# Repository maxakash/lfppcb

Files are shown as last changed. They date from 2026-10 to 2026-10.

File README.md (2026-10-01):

# LFP-8: 40-cell LiFePO4 33140 charger / discharger / IR tester

An open hardware tester for LiFePO4 32140/33140 cells. One **LFP-8 board**
handles **8 cells**. Five boards, JLCPCB's minimum order, test **40 cells at
once**. Each channel can

* **charge** with constant current then constant voltage: ≈ 1.0 A, CV 3.58 V,
  hardware OV latch at 3.82 V
* **discharge** at ≈ 1.07 A, with a hardware under-voltage backstop at 2.22 V
* measure **capacity** (coulomb counting, mAh/mWh) and **internal resistance**
  (pulse method, R_ohmic at 10 ms and DC-IR at 1 s) through true **4-wire
  Kelvin** connections
* read a 10 k **NTC** on every cell

Every board reports over Wi-Fi: a web dashboard and a JSON API served by its
ESP32-C3. The boards find each other, so any one of them shows all 40 cells.

| | |
|---|---|
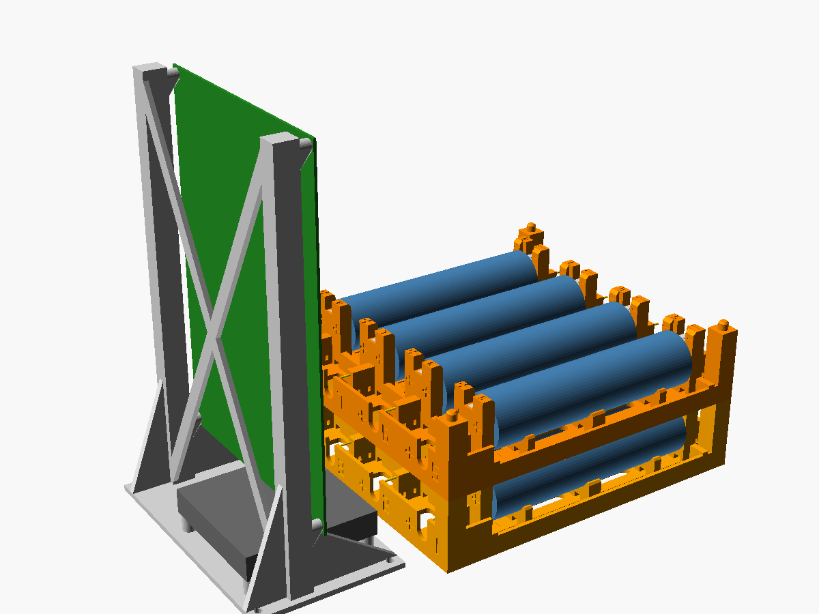
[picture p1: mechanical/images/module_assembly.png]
holder
| PCB |  |
| LFP-8 PCB (216 × 146 mm, 2 layers, JLCPCB assembly) | 3D-printed 8-cell module + board stand (Ender 3 S1 Pro) |

## Repository map

| Path | What |
|---|---|
| [`docs/DESIGN.md`](docs/DESIGN.md) | Architecture, circuit description, design numbers |
| [`docs/INTERFACE.md`](docs/INTERFACE.md) | Hardware ⇄ firmware contract: GPIO map, shift-register bits, thresholds, measurement formulas |
| [`docs/TEST_REPORT.md`](docs/TEST_REPORT.md) | Results of every simulation, adversarial and board-level test |
| [`docs/ORDERING_AND_ASSEMBLY.md`](docs/ORDERING_AND_ASSEMBLY.md) | How to order from JLCPCB, hand-solder parts, wiring, bring-up |
| `hardware/gen/` | **Single source of truth**: the netlist DSL (`lfp8_circuit.py`) and the generators for schematic, PCB, routing, checks and fab files |
| `hardware/kicad/` | Generated KiCad 7 project (schematic, PCB, project library) |
| `hardware/fab/` | Gerbers, drill, JLCPCB BOM + CPL, DRC report, check report |
| `sim/` | ngspice models, benches and the pytest suite (functional, adversarial, Monte Carlo, loop stability) |
| `firmware/` | ESP32-C3 Arduino firmware, web UI, REST API, IR calculator, host tests and simulator |
| `mechanical/` | OpenSCAD holder (4-cell cradles, board stand), STLs, printability checks |

## Quick start

1. **Order PCBs**: upload `hardware/fab/lfp8_gerbers.zip`, then
   `lfp8_bom_jlcpcb.csv` and `lfp8_cpl_jlcpcb.csv` for assembly. Details in
   [ORDERING_AND_ASSEMBLY.md](docs/ORDERING_AND_ASSEMBLY.md).
2. **Print the holders**: `mechanical/stl/`, 10 cradles + 5 board stands, PETG,
   no supports.
3. **Flash the firmware** through the J3 USB header:
   `make -C firmware build upload`, or open `firmware/lfp8` in the Arduino IDE
   with the ESP32 core, board *ESP32C3 Dev Module*, partition scheme
   *Minimal SPIFFS*.
4. **Power**: 5.20 V, ≥ 10 A per board. Join the board's Wi-Fi AP `LFP8-<id>` (password `lfp8admin`)
   and open `http://192.168.4.1`, or configure your Wi-Fi and use
   `http://lfp8-<id>.local`.

## Safety features (hardware, independent of firmware)

| Feature | Behaviour |
|---|---|
| CV limit | Kelvin-sensed 3.576 V (3.51–3.62 V worst case); firmware also stops at 3.60 V |
| OV latch | 3.82 V: cell isolated + charger drive killed until the cell is removed or SAFE_EN cycles |
| UV backstop | discharge stops at 2.22 V under load even if firmware hangs |
| Charge/discharge interlock | the charger is forced off while the load is on |
| Reverse cell | detected in < 50 µs; cell isolated (0.1 mA residual) whether the board is powered or not |
| Back-to-back isolation FETs | an unpowered board does not drain or back-feed the cells (81 µA residual) |
| Watchdog | a stuck or too-slow firmware loop (< 100 Hz heartbeat) shuts every channel down in 23–33 ms |
| Rail UV / OV | 4.48 V / 5.49 V |
| Board over-temperature | 70–95 °C → all channels off |
| E-STOP button | all channels off in 126 µs |
| PTC fuse per channel | 2 A hold; a board-side short trips in 0.22 s |
| TVS + reverse crowbar on the 5 V input | |

## Running the tests

```bash
./run_all_tests.sh          # ngspice suite, netlist + DRC checks, firmware tests, holder checks
QUICK=1 ./run_all_tests.sh  # shorter Monte Carlo
```

Regenerate the hardware from the DSL with `make -C hardware` (KiCad 7,
Freerouting 2.x and Java are required for routing).

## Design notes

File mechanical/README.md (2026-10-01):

# LFP-8 cell holder system (40 × LiFePO4 33140)

3D-printable, parametric holders for the 40-cell LFP-8 tester. Five LFP-8 boards with
8 channels each test 40 cells. Every cell gets a **4-wire Kelvin** connection (force and
sense at each terminal) plus an NTC bead under the cell.

* **Cradle**: 4 cells lying side by side. Two cradles stack (pins/sockets) into one
  **8-cell module per LFP-8 board**. 10 cradles = 40 cells.
* **Board stand**: holds one LFP-8 PCB vertically next to the module, with 4 × M3
  standoffs and a 60/80 mm 5 V fan under the board blowing up across both faces.
* Accessory: **pogo gauge** (sets the pogo pin protrusion). The earlier flat `board_tray`
  is still in the SCAD, but it is not built: the final 216 × 146 mm PCB is larger than a cradle.

Everything is generated from one OpenSCAD file. Every part prints in its modelled
orientation **without supports** on a Creality Ender 3 S1 Pro, inside a
210 × 210 mm footprint and under 260 mm height.

| | |
|---|---|
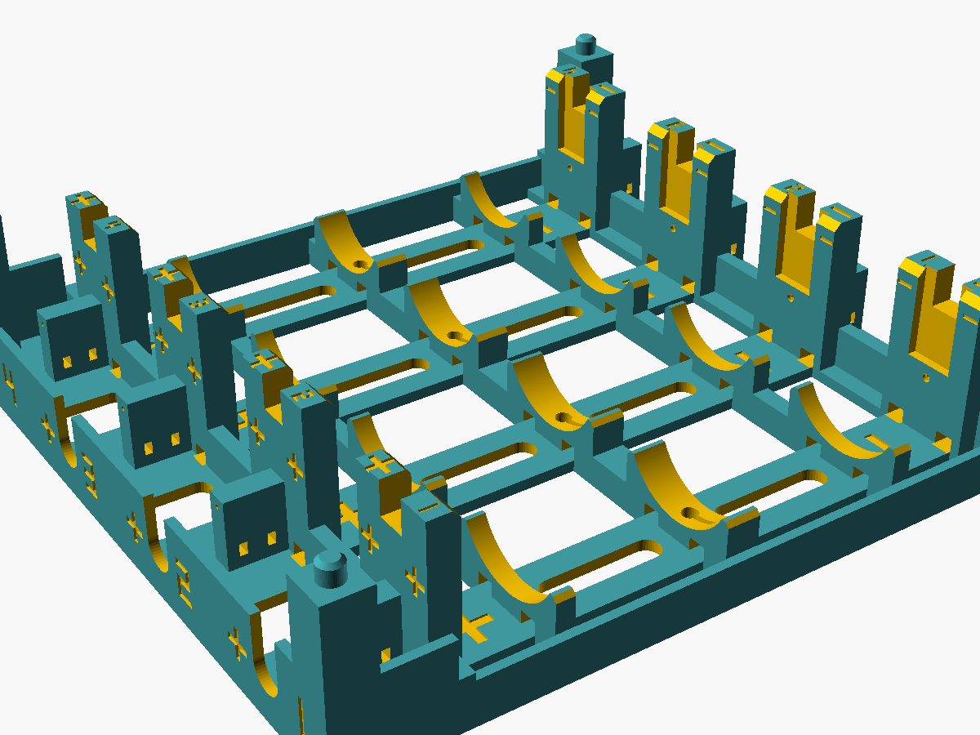
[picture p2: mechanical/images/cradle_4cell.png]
cradle
|  | module |
| 4-cell cradle (channels 1–4) | 8-cell module (2 cradles) + LFP-8 board stand |
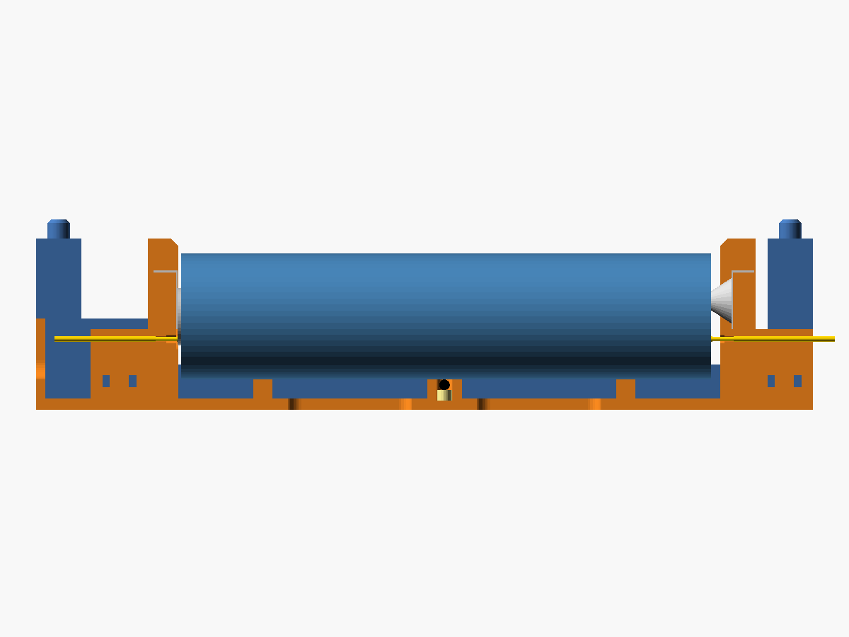
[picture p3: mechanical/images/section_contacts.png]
section
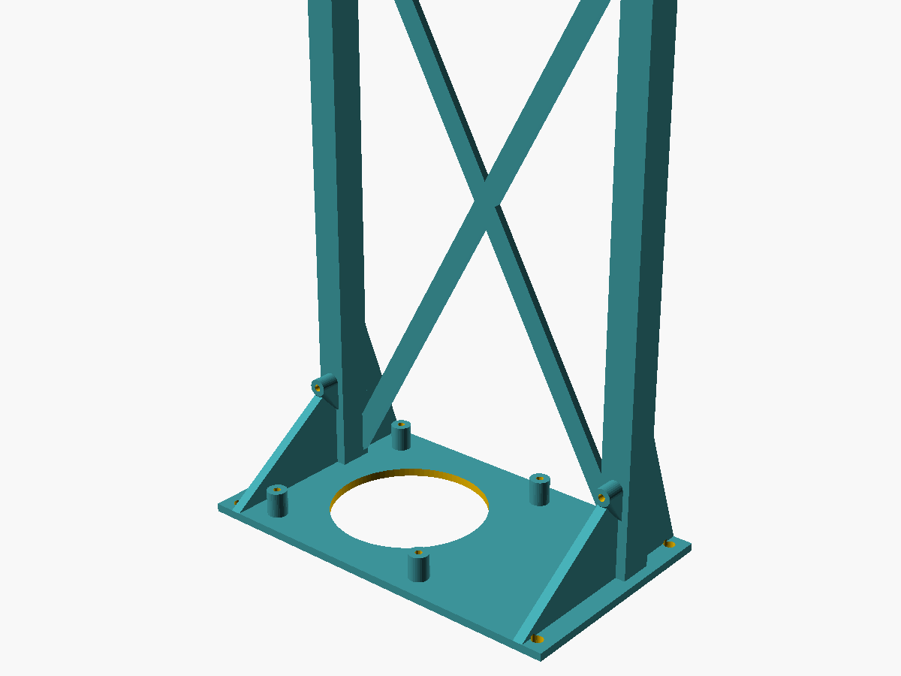
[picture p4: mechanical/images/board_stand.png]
stand
|  |  |
| Section through one cell: + plate, + pogo, NTC bead, − spring, − pogo | Board stand (fan posts, gusseted M3 standoffs, X-brace) |

## Files

| File | Purpose |
|---|---|
| `lfp_holder.scad` | Parametric source. Select the part with `-D 'part="…"'`: `cradle`, `board_stand`, `board_tray`, `pogo_gauge`, `assembly`, `section` |
| `build.sh` | Regenerates all STLs and PNGs, then runs the checker. Any OpenSCAD warning aborts it. |
| `check_printability.py` | Mesh and design checks. Exits non-zero on failure (see *Checks*). |
| `stl/cradle_4cell_labels_1-4.stl` | Cradle labelled channels 1–4: the **lower** cradle of a module (print 5) |
| `stl/cradle_4cell_labels_5-8.stl` | Cradle labelled channels 5–8: the **upper** cradle of a module (print 5) |
| `stl/board_stand.stl` | Vertical PCB stand with fan mount (print 5) |
| `stl/pogo_gauge.stl` | Pogo protrusion gauge (print 1) |
| `stl/params.echo` | Parameter dump (JSON in the OpenSCAD echo) that the checker reads |
| `images/*.png` | Previews |

Rebuild everything with `./build.sh`. You need OpenSCAD 2021.01, `xvfb-run` for the PNGs, and
`pip install numpy-stl trimesh rtree networkx`.

## Design summary

Coordinates are those of the cradle in its print orientation, in mm.
X runs along the cell axis, with x = 0 at the outer face of the wire raceway (connector / **+** end).
Y runs across the cells, with y = 0 at one long side. Z is up, with z = 0 at the bed/table.

| Item | Value |
|---|---|
| Cradle outside dimensions (X × Y × Z) | 203.95 × 192.0 × 45.0 (+5 mm stacking pins) |
| Stack pitch | 45.0 (the upper cradle floor sits 3.4 mm above the tallest cell) |
| Cell centres (Y) | 24, 72, 120, 168 (pitch 48, so there is a 14.4 mm finger gap between cells) |
| Saddle radius / clearance | R 17.2, which is 0.40 mm radial for Ø33.6 and 0.70 mm for Ø33.0 |
| Cell axis height (resting) | z 24.5 (Ø33.0) … 24.8 (Ø33.6); contacts referenced to z 24.65 |
| **+ contact plane P** (face of + plate) | x = 37.25. The spring presses every cell against it, so P is the fixed datum. |
| + force plate (B+F) | 15 × 15 plate. Centre is 4.0 mm **above** the cell axis (y = cell centre, z = 28.65). |
| + sense pogo (B+S) | 6.0 mm **below** the axis (z 18.65, y = cell centre). Free tip at x 38.25, i.e. 1.0 mm preload. |
| − spring plate (B−F) | Spring base at x 182.55. Plate centre is 4.0 mm above the axis, so the spring tip misses any M4/M5 hole. |
| − sense pogo (B−S) | z 18.65, y = cell centre. Free tip at x 176.25, so a 139.5 mm cell compresses it by 0.5 mm. |
| + plate face to − spring base | 145.3 mm (nominal 0.4 mm plates) |
| NTC pocket | Ø4.2 × 5.5 deep at x 107.25 (cell middle), y = cell centre, top at the saddle bottom (z 8) |
| Wire exit per channel | U-notch in the raceway lip at y = cell centre, z 8…24 (+45 for the upper cradle) |

**Spring calculation.** The check script verifies this over all tolerances: cell
139.5–141.5 mm, plates 0.3–0.5 mm, spring free height 8–10 mm, solid height 3 mm.

* 141.5 mm cell with the thickest plates: the spring is compressed to **3.6 mm** working height.
  That is ≥ 2 mm, 0.6 mm above solid, with 4.4–6.4 mm of deflection.
* 139.5 mm cell with the thinnest plates and an 8 mm spring: the spring still has **2.0 mm pre-load**
  (3–4 mm with 9–10 mm springs).

**Why the + plate is offset.** On the **+** end the force plate and the sense pogo must
both land on the raised cap (Ø14–16 mm) without touching each other. The plate is shifted
4 mm up and the pogo sits 6 mm below the axis. That leaves 1.75 mm between the plate edge
and the pogo head, and the plate still covers 124 mm² of a Ø14 cap. A Ø17.5 × 0.6 mm recess
around the cap means only the plate and the pogo can touch it. The rest of the wall stays
≥ 0.2 mm behind the cell shoulder, so a cap raised by ≥ 0.5 mm, with or without an M4/M5
thread, always seats on the plate. The pogo at 6 mm off-axis misses an M5 thread (r 2.5 mm).

**Pogo stroke.** P100 probes are 33.35 mm long with Ø1.36 mm barrels, a 4 mm working stroke
and 6.2–6.5 mm full stroke.

* + pogo: always compressed by 1.0 mm, because the cell is pressed against the + plate.
  The Ø2.2 head-clearance bore ends exactly at 4.0 mm of compression, which acts as a hard stop.
* − pogo: 0.5–2.5 mm of compression over the full 139.5–141.5 mm length range.
  If you use short-stroke pins (≈2 mm), set the − pin per cell batch with the gauge
  (see Assembly step 4).

**Printability rules.**

* All structural walls are ≥ 2.4 mm. The only thinner features are 0.6 mm label and recess
  depths, and the 1.6 mm web between the − slot floor and the pogo bore.
* There are no overhangs steeper than 45°.
* Bridges are ≤ 10 mm. The widest is the 5 mm wire tunnel. The fan opening in the tray has a 45° roof.
* Stacking pins are Ø6.0 in Ø6.4 sockets, i.e. **0.2 mm radial clearance**. The sockets have
  45° cone roofs and a 0.6 mm entry chamfer against elephant foot.

### Main parameters (top of `lfp_holder.scad`)

| Parameter | Default | Meaning |
|---|---|---|
| `cell_d_max`, `cell_len_min/max`, `cell_clr` | 33.6, 139.5/141.5, 0.4 | Cell envelope and radial clearance |
| `n_cells`, `pitch` | 4, 48 | Cells per cradle, centre distance |
| `base_t`, `min_wall` | 3, 2.4 | Floor and minimum wall |
| `fp_w/fp_h/fp_t`, `spring_free_min/max`, `spring_solid`, `spring_preload_min` | 15/15/0.4, 8/10, 3, 2 | Force contacts. `L_contact` is derived from these. |
| `force_off`, `sense_off` | 4.0, 6.0 | Plate offset above / pogo offset below the cell axis |
| `sense_style` | `"pogo"` | `"plate"` gives a second 10 × 10 slot per end for a sense plate instead of a pogo pin (− end: 10 × 10 plate **with** small spring) |
| `pogo_hole_d` | 1.40 | Pogo bore. Press fit for P100 after reaming. Use 1.70 for R100 receptacles. |
| `pos_pogo_preload`, `neg_pogo_preload` | 1.0, 0.5 | Pogo tip positions |
| `label_offset` | 0 | 0 gives labels 1–4, 4 gives labels 5–8 |
| `pcb_w`, `pcb_h`, `pcb_hole_inset` | 146, 216, 4.5 | LFP-8 PCB (216 × 146 mm) mounted **portrait**: `pcb_w` is the horizontal side. The stand follows these values. |
| `fan_size`, `fan_hole_spacing`, `fan_t`, `fan_dx` | 80, auto, 15, 20 | Fan: 80 × 15 mm slim fan, which keeps the stand 252 mm tall. 60 gives 50 mm hole spacing, 80 gives 71.5 mm. `fan_dx` shifts it towards the PCB's power-stage edge. |
| `screw_pilot_d` | 2.8 | M3 self-tapping pilot. Use 4.0 for M3 heat-set inserts. |
| `bed_x/y/z`, `bed_margin` | 220/220/270, 5 | Printer. The SCAD asserts that the cradle fits. |

Example: `openscad -o stl/board_stand_60mm.stl -D 'part="board_stand"' -D fan_size=60 -D fan_t=15 lfp_holder.scad`

## Bill of materials

### For all 40 cells (10 cradles, 5 stands)

| Qty | Item | Search terms / notes |
|---|---|---|
| 40 (+10) | **+ contact plate**, flat, nickel-plated steel, 15 × 15 × 0.3–0.5 mm, solder tab | "battery contact plate 15x15 positive flat nickel plated solder tab". Usually sold as +/− pairs. Tab ≤ 7 mm wide. |
| 40 (+10) | **− contact plate with conical spring**, 15 × 15 mm, spring free height 8–10 mm, base Ø ≤ 12 mm | "battery spring contact plate 15x15 negative conical spring" |
| 80 (+20) | **Pogo pin P100 series**: Ø1.36 barrel, 33.35 mm long, 4 mm working stroke | "P100-B1 spring test probe 1.36mm 33.35mm" (pointed). A crown/serrated head (often listed as P100-H2 / P100-Q2; check the head drawing) bites better on nickel-plated flat terminals. Avoid cup heads. Usually sold in 100-packs. |
| (80) | *optional* R100 receptacle Ø1.67 mm | "R100-2W pogo receptacle". Makes pins replaceable; set `pogo_hole_d = 1.70`. |
| 40 (+5) | **NTC 10 kΩ, B = 3950**, epoxy bead Ø ≤ 3 mm | "MF52AT 10K 3950 NTC thermistor". Needs ~130 mm leads to the raceway, so extend with 30 AWG wire if they are shorter. |
| 40 | Foam disc Ø4 × 3 mm (EVA / silicone sponge) | Pushes the NTC bead against the cell |
| 40 | **JST-XH 2.54 mm 6-pin pre-crimped lead, single-ended, 40–50 cm** | "JST XH 6P single head 50cm 24AWG". XH contacts take 22–28 AWG; 22 AWG preferred for the force wires. The mating B6B-XH-A headers are on the LFP-8. |
| ~10 m | Hook-up wire 22–24 AWG (silicone) | Extensions / repairs. Force wires 22–24 AWG, sense and NTC 24–28 AWG. |
| 1 set | Heat-shrink 1.5 mm and 3 mm | Over every solder joint at pogo tails and tabs |
| 200 | Zip ties 2.5 × 100 mm | 2 per fin (+ and − end) per cell |
| 5 | **Fan 5 V, 80 × 80 × 15 (slim)**, ≤ 0.25 A | Driven by `FAN_PWM` on the LFP-8 (J2). A 25 mm thick fan makes the stand 262 mm tall, too tall for the S1 Pro. |
| 20 | M3 × 8–10 pan-head screw (self-tapping into PETG, or machine screw + heat-set insert) | PCB, 4 per stand |
| 20 | M3 × 20 (80 × 15 fan) | Fan, 4 per stand, self-tapping into the Ø2.8 posts |
| (20) | *optional* M3 heat-set inserts M3 × 5 × 4 | Rebuild with `screw_pilot_d = 4.0` |
| (20) | *optional* M4 screws | Fix stand bases to a common base board (Ø4.5 holes) |
| – | Tools | 1.4 mm drill bit in a pin vise (1.35 mm for a tighter press fit), soldering iron, thin CA glue (optional) |

Per cradle: 4 + plates, 4 − spring plates, 8 pogo pins, 4 NTC, 4 foam discs, 8 zip ties.

## Print settings (Ender 3 S1 Pro)

* **Material: PETG** (preferred over PLA). The cradles sit next to warm electronics and
  cells. PLA softens at ~55 °C, PETG at ~75–80 °C. Nozzle 235–245 °C, bed 75–80 °C,
  part cooling 30–50 %. Use glue stick as a release agent on smooth PEI.
* 0.4 mm nozzle, **0.2 mm layers** (0.24 mm first layer), **4 walls**, 5 top / 4 bottom layers,
  **25–30 % gyroid**, 50–60 mm/s (outer walls 30–40 mm/s).
* **No supports.** Print every part as exported: cradle floor down, stand base down,
  tray down, gauge flat.
* Brim optional (5 mm), useful on the cradles because of their large thin floor grid.
  Elephant-foot compensation 0.1–0.15 mm helps the pin/socket fit.
* The cradles nearly fill the bed (204 × 192 mm). Align their long side with X if your slicer
  complains.

### Filament and time

From `check_printability.py`: solid volume × 45 % effective fill × 1.27 g/cm³. Time uses a
rough Ender 3 S1 Pro model (≈4 mm³/s average, 6 s per layer, 6 min setup).

| Part | Qty | Solid vol. | Filament each | Time each | Total |
|---|---:|---:|---:|---:|---:|
| `cradle_4cell_labels_1-4` | 5 | 213.8 cm³ | 122 g (40 m) | 7.2 h | 611 g, 36 h |
| `cradle_4cell_labels_5-8` | 5 | 213.8 cm³ | 122 g (40 m) | 7.2 h | 611 g, 36 h |
| `board_stand` | 5 | 150.5 cm³ | 86 g (28 m) | 6.9 h | 430 g, 34.5 h |
| `pogo_gauge` | 1 | 3.0 cm³ | 2 g | 0.2 h | 2 g |
| **Whole set** | | | | | **≈1.65 kg PETG (~2 × 1 kg spools), ≈107 h** |

Most cradle features are within 4 perimeters (ribs, rails, fins, the 3 mm floor). A slicer
may therefore report 20–40 % more filament than the 45 % rule. Use the slicer figure for
ordering.

## Assembly

1. **Post-process.** Remove the brim. Check that two cradles stack: pins on the corner posts,
   sockets underneath.
2. **Ream the pogo bores.** Small horizontal holes print undersize. From the **cell side**,
   run a 1.4 mm drill (1.35 mm for a tighter grip) through the end wall **and** the support fin
   in one pass, at both ends of every slot.
3. **Contact plates.** Do this before the pogo pins.
   * **− end (spring)**: bend the solder tab 90° backwards at the plate edge. Slide the plate
     down the slot with the spring facing the cell and the tab riding down the notch in the
     back of the wall. The plate edges are held behind the 2.4 mm skin and the spring sticks
     through the window.
   * **+ end (flat)**: bend the tab the same way and slide the plate down the pocket. The bent
     tab comes to rest on the notch floor, so the plate hangs at exactly the right height.
     The cell's spring force presses it flat.
   * Solder the force wires (**B+F**, **B−F**) to the tab ends behind the walls.
4. **Pogo pins.** The head (Ø1.5) is larger than the bore, so insert each pin **tail first
   from the cell side**. Push it through the wall and the fin until the free tip protrudes:
   * **+ end:** **0.8 mm** in front of the wall face (the `+` pad of the gauge). That is
     1.0 mm in front of the plate.
   * **− end:** **3.4 mm** in front of the wall face (the `−` pad of the gauge). That is right
     for any 139.5–141.5 mm cell with P100 pins.

   To use the gauge, lay its flat side on the wall face with the slot around the plunger.
   The tip must be flush with the top of the pad. If the fit is loose, add a drop of thin CA
   at the fin end. Tin the tail ends and solder **B+S** / **B−S** quickly; don't overheat the
   spring inside. Add heat-shrink.
5. **NTC.** Put a foam disc in the pocket of the middle rib and lay the bead on it, so it
   stands ≈0.5–1 mm above the saddle. Lead the wires through the small groove into the wire bay.
6. **Route the wires.** The − end wires (B−F from the tab, B−S from the pogo tail):
   * go down the back of the − wall, beside the fin;
   * pass through the two bottom tunnels;
   * run along the floor strip under the cell, through the rib notches;
   * leave through the tunnels at the bottom of the + wall into the raceway.

   Zip-tie the wires to the fins (2 slots per fin). In the raceway, gather the 6 wires of the
   channel and tie them to the + fin for strain relief. They leave through the U-notch next
   to the channel number.
7. **Connectors.** Solder or crimp to the JST-XH 6-pin lead in the pin order below.
   Heat-shrink every joint and label the lead with its channel number.
8. **Module.** The `1-4` cradle goes at the bottom and the `5-8` cradle on top (pins in
   sockets). Leave a ~10 cm service loop: to change cells in the lower cradle you lift the
   upper one off.
9. **Board stand.**
   * Screw the fan onto the 4 posts with the airflow arrow **up**. Air enters through the
     10 mm gap under the fan.
   * Screw the PCB onto the 4 standoffs with its component side away from the X-brace,
     **portrait** (long side vertical), with the JST connector edge on the side the fan is
     offset to. The 8 power stages then sit in the fan's air stream.
   * Place the stand at the + (connector) end of the module and plug in the 8 leads.
10. **Cells.** Check the polarity marks, then insert:
    * Marks: the big **+** on the floor, the tower tops and the raceway is the **connector end**.
      **−** is at the spring end.
    * To insert: push the cell's flat **− end into the spring** (≈2 mm), then lower the **+ cap**
      end into the saddle against the + plate.
    * To remove: grip the cell in the finger gaps, push it toward the spring and lift the + end.

### Kelvin wiring, per channel

```
 JST-XH 6P (to LFP-8)                       cell slot (top view)
 pin 1  B+F  ─22-24 AWG─┐                                                    ┌─22-24 AWG─  B-F  pin 4
 pin 2  B+S  ─24-26 AWG─┼──┐                                              ┌──┼─24-26 AWG─  B-S  pin 3
                        │  │      + end (fixed datum)        - end        │  │
                        │  │    ┌──────────────────────────────────────┐  │  │
                        └──┼──► │+ plate │                   │ spring  │◄─┼──┘   force: plate / spring
                           │    │  ║    │  +cap  33140  can  │   ║     │  │      carry the current
                           └──► │+ pogo ●│        cell       │● - pogo │◄─┘      sense: separate pogo
                                │        │         ◉ NTC     │         │         pins, no current
                                └─────────────────┬──────────────────────┘
 pin 5  NTC  ──────────────────────────────────── ┤  (10k B3950 bead, under the cell middle)
 pin 6  GND  ──────────────────────────────────── ┘
```

* Force and sense meet **only at the cell terminal**. On each end they are separate parts,
  ≥ 1.6 mm apart. The voltage drop of plates, springs, wires and connector is
  therefore not measured.
* All 6 wires of a channel run in one bundle (raceway → U-notch → lead) to keep loop area
  and noise pickup low. Twist B+S / B−S if you extend them.
* The NTC is isolated (epoxy bead on the PVC wrap). Pin 6 is its return.

## Checks (`check_printability.py`)

The script is run by `build.sh`; its output for the current design ends with **ALL CHECKS PASSED**.

* Every STL:
  * watertight, consistent winding, positive volume, a single body;
  * numpy-stl and trimesh volumes agree;
  * bounding box ≤ 210 × 210 × 260 mm and sitting on z = 0;
  * every downward patch steeper than 45° is a bridge ≤ 10 mm (widest: 5.0 mm cradle tunnels,
    2.0 mm on the stand, 4.0 mm in the tray roof).
* Volume → grams, metres of 1.75 mm filament and print time, per part and for the whole set.
* Cradle checks, using the parameters exported by `lfp_holder.scad`:
  * radial clearance ≥ 0.3 mm (0.40 mm);
  * the longest cell stays 0.9 mm off the − wall;
  * shoulder clearance on the + wall;
  * cap recess;
  * spring height and pre-load over all tolerances;
  * pogo stroke budget and hard stop;
  * the + pogo lands on a Ø14 cap;
  * plate-to-pogo separation and plate/cap overlap;
  * pogo tail room;
  * stack gap and pin clearance.
* **Mesh test**: ≈46 k points on the cell envelope (Ø33.6 + 0.3 mm radial, 141.5 mm long,
  both diameters resting in the saddle, cap face and shoulder) must all be outside the
  cradle mesh in all 4 slots. A **negative control**, an envelope only 0.05 mm larger than
  the saddle, must be detected, which shows the test actually works.

## Safety

* **Never leave cells charging or discharging unattended.** A 15 Ah LiFePO4 cell holds
  ~48 Wh. A short through a mis-bent tab or a loose wire can drive > 100 A.
* **Check the polarity marks before every insertion.** **+** (flat plate) is at the
  raceway / connector end, **−** (spring) at the far end. A reversed cell is not shorted by
  the holder, because each end's contacts touch only one terminal, and the LFP-8 reports
  it as `REVERSED`. Still, remove it immediately.
* Insulate every solder joint (heat-shrink). Keep tabs and pogo tails from touching
  neighbouring channels. The − pogo tails stick out 5.7 mm behind the cradle, so leave
  ≥ 15 mm free behind the module.
* Do not use cells with damaged wraps: the can is the negative terminal. Do not stack more
  than two cradles.
* Use PETG (or ABS/ASA), not PLA. Keep the module away from flammable material, run the fan,
  and respect the firmware temperature limits.

## Notes for the electronics designer

* **Connector end = cell + end.** Per channel, one 6-wire bundle leaves the cradle through
  the raceway lip:
  * position: y = 24 / 72 / 120 / 168 mm from one long side, at the exit centre (pitch 48 mm);
  * height: z = 8–24 mm (channels 1–4, lower cradle) or z = 53–69 mm (channels 5–8, upper cradle).
* **Wire length** from each contact to the exit notch:
  * B+S ≈ 30 mm, B+F ≈ 80 mm, NTC ≈ 130 mm;
  * B−F / B−S ≈ 260 mm (they run back under the cell).

  The default stand places the PCB plane about 60 mm from the raceway face. The total length
  from contact to header is then ≈ 0.35–0.5 m, including a 10 cm service loop for lifting
  the upper cradle. **Specify 40–50 cm XH leads.**
* **Force-loop resistance.** Per wire: 0.5 m of 24 AWG ≈ 42 mΩ (22 AWG ≈ 26 mΩ). Each
  plate/spring contact adds 5–20 mΩ and each XH contact ≈ 10 mΩ. That gives ≈ 0.15 Ω per loop,
  ≈ 0.25 V at 1.7 A, which must fit in the charger headroom on the 5 V rail. Sense lines carry
  no current, so this does not affect the measured voltage.
* **Sense contact.** P100 pogo, ~50 mΩ, 1.8 N. It lands on the + cap 6 mm off-axis, and on
  the flat − can 6 mm off-axis.
* **Reversed cell.** The + plate and + pogo touch the cell's −, and the spring and − pogo
  touch the cell's + (the spring tip lands 4 mm off-axis on the cap). All four wires then see
  ≈ −3.3 V, so the `REVERSED` detection in `docs/INTERFACE.md` works.
* **Empty slot.** Both force paths and both sense pins are open, so the inputs float.
  `EMPTY` detection relies on the board's bias, not the holder.
* **NTC.** 10 kΩ B3950 bead, sitting on the PVC wrap at the cell's middle. Expect it to lag
  the can by minutes and read 1–3 °C low.
* **PCB / stand.**
  * Holes: 4 × M3 at the PCB corners, 4.5 mm inset, i.e. 137 × 207 mm spacing for the
    146 × 216 mm board mounted portrait. They are parametric: set `pcb_w`, `pcb_h`,
    `pcb_hole_inset`.
  * Clearance behind the board: 8 mm. Keep bottom-side parts and leads < 6 mm.
  * The uprights cover a 12 mm-wide strip behind each pair of holes, so keep back-side parts
    > 10 mm from the left and right edges.
  * The fan (80 × 15 mm) sits under the bottom edge, centred on the PCB plane but shifted
    20 mm towards the power-stage edge, and blows up along both faces. On the LFP-8 the eight
    power stages (load resistors, pass FETs) form one strip along the JST edge, so mounted
    portrait they are a vertical column in the air stream.
  * The component side faces the module, so the 8 JST-XH headers are best on the bottom or
    side edges of that face.

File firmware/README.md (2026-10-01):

# LFP-8 firmware

Firmware for the **LFP-8** board: one ESP32-C3-WROOM-02 controlling 8
LiFePO4 channels (33140, 3.2 V, 15 Ah). Five boards test 40 cells and show up
together on one web dashboard. The hardware/firmware contract is
[`docs/INTERFACE.md`](../docs/INTERFACE.md); this firmware follows it
(GPIO map, 74HC595 bit map, CD4051 mux, ADS1115 configs, safety chain, test
policy, IR method, networking).

Features: charge (CC/CV with pulse precharge), discharge to 2.5 V, full
capacity test (charge -> rest -> discharge with mAh/mWh -> rest -> storage
charge to 50 % -> IR), DC-IR and ohmic IR (section 7.1), per-cell and board
temperature supervision, 24 h V/I history per channel, multi-board dashboard,
resistance calculator, pack builder (SxP grouping), CSV export, settings and
calibration in NVS, OTA.

## Layout

```
firmware/
  lfp8/                     Arduino sketch (arduino-cli compile ... firmware/lfp8)
    lfp8.ino                setup()/loop() -> app_esp32
    lfp8_config.h           board constants, pins, timing (INTERFACE.md sections 2-8)
    hal.h                   HAL interface: shift register, ADS1115 registers, ESP32 ADC, GPIO, time
    adc_conv.*              ADS1115 config words, code->V/I, NTC, VIN, board temperature
    shiftreg.*              32-bit 74HC595 word builder, CHG/DIS interlock
    channel.*               per-channel state machine + test programs, coulomb counters
    coulomb.h               trapezoidal mAh/mWh integration (double accumulators)
    ir_calc.*               R_ohmic (10 ms) / R_dc (1 s) computation
    supervisor.*            safety supervisor (SAFE_RB, VIN, temperatures, ADC/I2C faults)
    controller.*            scanner, IR engine, outputs, heartbeat, fan, LEDs, commands
    history.*, leds.*, settings.*, peers.*, packbuilder.*
    json_writer.*, json_reader.*   tiny JSON emitter / reader (no ArduinoJson)
    api.*                   JSON/CSV documents and request parsing for the HTTP API
    *_esp32.*               ESP32-only glue: HAL, control task, NVS, WiFi/mDNS/UDP/OTA, HTTP
    webui_html.h            the dashboard (HTML/CSS/JS, PROGMEM, no CDN)
  test/                     host tests (own mini framework) + simulated board
  API.md                    HTTP/UDP API
  Makefile                  make test | make build | make clean
```

Everything outside `*_esp32.*`, `lfp8.ino` and `webui_html.h` is plain C++17
without Arduino headers and is compiled and tested on the host against
`test/sim_board.cpp`, a model of the board (74HC595 decode, ADS1115 register
emulation, LFP cells with OCV curve + R0 + RC, CC/CV charger with ISET DAC and
CV limit, 2.75 ohm load with UV backstop, OV latch, NTCs, heartbeat charge
pump / SAFE_EN chain).

## Building

### arduino-cli

```sh
arduino-cli config add board_manager.additional_urls \
  https://raw.githubusercontent.com/espressif/arduino-esp32/gh-pages/package_esp32_index.json
arduino-cli core update-index
arduino-cli core install esp32:esp32          # tested with 3.3.12
arduino-cli compile --fqbn esp32:esp32:esp32c3:PartitionScheme=min_spiffs firmware/lfp8
# or: make -C firmware build
```

Only libraries bundled with the core are used (WiFi, WebServer, ESPmDNS,
Preferences, Wire, Update, ArduinoOTA). The partition scheme is
**Minimal SPIFFS** (2 x 1.9 MB OTA app slots, 128 KB SPIFFS, same NVS
location as the default scheme). Result with core 3.3.12:

```
Sketch uses 1240851 bytes (63%) of program storage space. Maximum is 1966080 bytes.
Global variables use 165144 bytes (50%) of dynamic memory, leaving 162536 bytes for local variables.
```

(With the default scheme the same image would fill 94 % of a 1.25 MB slot.)
The LFP-8 code itself is ~90 KB of flash (37 KB of it the web page) and
~122 KB of static RAM (92 KB is the 24 h history ring). A board that was
flashed with a different partition scheme must be flashed once over USB with
this one (OTA cannot change the partition table; settings in NVS survive).

Flash over USB (native USB-Serial/JTAG on IO18/IO19):

```sh
arduino-cli upload -p /dev/ttyACM0 --fqbn esp32:esp32:esp32c3:PartitionScheme=min_spiffs firmware/lfp8
arduino-cli monitor -p /dev/ttyACM0 -c baudrate=115200    # console log
```

To produce `lfp8.ino.bin` for OTA:
`arduino-cli compile --fqbn esp32:esp32:esp32c3:PartitionScheme=min_spiffs --output-dir /tmp/lfp8-bin firmware/lfp8`.

The console uses the USB-Serial/JTAG peripheral regardless of the
"USB CDC On Boot" menu (an own `HWCDC` instance) - UART0 is never started,
because its pins IO20/IO21 are `SAFE_RB` and `FAN_PWM` on this board. The
ROM bootloader still prints on IO21 at reset (the fan may twitch briefly).

### Arduino IDE 2.x

1. *File -> Preferences -> Additional boards manager URLs*: add the URL above;
   install **esp32 by Espressif Systems** (3.x) in the Boards Manager.
2. Open `firmware/lfp8/lfp8.ino`. Board: **ESP32C3 Dev Module**,
   Partition Scheme **"Minimal SPIFFS (1.9MB APP with OTA/128KB SPIFFS)"**,
   Flash 4 MB, USB CDC On Boot either setting.
3. Upload via the USB port. If the board does not enter the bootloader, hold
   BOOT (IO9) while pressing EN.

### Host tests

```sh
make -C firmware test
```

Builds and runs 76 unit/integration tests (ADC conversions incl. sign,
ADS1115 config words, ISET set-points and the passive current ceiling,
shift-register bit map and interlock, state machine: empty/reversed
detection, CC/CV, I_TERM and plateau termination (hardware CV 3.51 V),
V_MAX_CHG, 2.5 V cut-off, thermal-policy pulsing (20 % below 2.80 V, 50 %
below 3.05 V), refusal below 2.0 V, OV faults and hardware OV-latch
detection/release, timeouts, temperature pause/resume, current plausibility;
contact-resistance hint, IO1 cross-check dwell with the RC filter, heartbeat
timing (VREF delay at boot, 15 ms hiccup tolerated, 40 ms trips); IR on a
simulated cell (R0 8 mOhm, R1 4 mOhm, tau 0.5 s -> R_ohmic 8.07, R_dc 11.47
mOhm) incl. the charge-pulse fallback; coulomb counting (1.000 A x 1 h =
1000 mAh, also through the full ADC chain: -0.006 %); supervisor (SAFE_RB
loss, stalled loop, ADC cross-check mismatch and stray current stop the
heartbeat, I2C faults, VIN window, board temperature derating); pack builder
(40 random cells, 4S10P spread < 1 %); JSON emitter/reader and every API
document), parses all emitted JSON with `python3 -c 'import json'`, checks the
embedded web UI (`node --check` when node is installed) and runs
`sim_cell_test`: a full capacity test on 8 simulated 15 Ah cells (37 h of
simulated time in ~70 s, hardware CV spread over 3.51-3.62 V, one cell
starting at 2.58 V) that must report every capacity within +-1 % and never
keep CHG_EN on longer than one 1 s pulse below 3.0 V.

## Power

Set the external +5V supply to **5.20 V** (5.00-5.25 V allowed; the
charge-current set-points scale with V_IN/5.20). The hardware drops SAFE_EN
below 4.48 V or above 5.50 V; the firmware aborts jobs outside its own window
(default 4.80-5.40 V, `vin_min`/`vin_max`) and shows a hint when the rail is
outside 5.00-5.25 V.

## First boot and WiFi

1. Power the board. Without stored credentials it opens the access point
   **`LFP8-<id>`**, password **`lfp8admin`**. Connect and open
   `http://192.168.4.1/`.
2. *Settings*: enter WiFi SSID/password and a unique **board id 1..5**
   (cells are numbered `(id-1)*8 + k`, so board 3 shows cells 17-24; the
   default id is derived from the MAC and may collide). *Save*, then
   *Reboot board*.
3. The board joins the WiFi (hostname `lfp8-<id>`, mDNS
   `http://lfp8-<id>.local/`). If the network is not reachable within 15 s it
   opens the AP again (and keeps retrying the WiFi in the background; the AP
   is switched off 2 minutes after the WiFi connection is back and no AP
   client is connected).
4. Holding **BOOT for 5 s** while running clears the WiFi credentials and
   restarts in AP mode.

On the first boot the board-temperature diode is calibrated assuming the
board is at 25 C (V25); recalibrate later in *Settings* if needed.

## Multi-board operation

* Every board broadcasts `{"t":"hello","id":..,"ip":..,"fw":..}` on UDP
  45454 every 2 s and keeps a peer table (`GET /api/peers`).
* Open the dashboard of **any** board: the browser fetches `/api/peers` from
  that board and then polls `http://<peer>/api/status` of every board
  directly (CORS `*`), so the grid shows all 40 cells. Commands go straight
  to the owning board (`POST http://<peer>/api/cmd`). Offline boards are
  marked, duplicate board ids are flagged.
* History charts and IR traces are fetched from the owning board; the pack
  builder posts the cells of all boards to the board that served the page.
* All boards and the browser must be in the same broadcast domain (same
  WiFi/subnet). Through the AP (192.168.4.1) only that board is visible.

## Using the tester

Per cell: **Charge**, **Discharge**, **Cap test**, **IR**, **Stop**,
**Reset** (clears a fault and the stored results). Board panel: VIN, board
temperature, SAFE status, heartbeat, fan, **ISET** (0..7, 0.24-1.69 A,
board-wide; >= 6 only below 50 C), alarm acknowledge, stop board, identify.
Header: **Stop all** (all boards).

| Program | Sequence |
|---|---|
| charge | rest voltage < 2.00 V -> `FAULT_DEAD_CELL` (refused); 2.00-2.80 V -> precharge at 20 % duty (1 s on / 4 s off); 2.80-3.05 V -> 50 % duty (0.5 s on / 0.5 s off) - thermal policy of the SOT-23 pass FET, decided on the rest voltage in the off phases; >= 3.05 V continuous CC; CV detected at >= 3.50 V or when the current falls below 85 % of what the charger should deliver (set-point and passive ceiling (V_IN-0.38-V)/1.5 ohm). End of charge by **current**: I < 0.05 A for 60 s, or a CV current below 0.2 A that stopped falling for 10 min (plateau); the hardware CV is 3.51-3.62 V so no particular voltage is required. V >= 3.60 V (V_MAX_CHG) stops the charge as well. |
| discharge | 2.75 ohm load (~1.07 A at 3.29 V) until 2.50 V under load (3 consecutive samples); mAh/mWh reported. Refused below 2.62 V (the load cannot start below 2.59 V; hardware backstop 2.22 V under load). |
| captest | charge -> rest 30 min -> discharge (capacity) -> rest 30 min -> charge 50 % of the measured Ah -> rest 5 min -> IR -> DONE |
| ir | rest >= 5 s, 16-sample V0/I0, 1 s load pulse sampled at 860 SPS, R at 10 ms and 1 s; charge pulse (ISET 4) below 2.65 V |

The **B- path** value on each cell is the wire + contact resistance of the
negative connection, estimated whenever >= 0.2 A flows from the B-
diagnostic (AIN1-AIN3 = I x (R + 2 x 28 mOhm + 0.1 ohm), measured at
+-1.024 V full scale). Above 300 mOhm it shows `CONTACT_WARN` (warning only).

The measured current is used for all accounting (trapezoidal integration at
~6 Hz per channel, double accumulators); results survive a reboot (NVS).

LED codes (green LED per channel): EMPTY off, IDLE 50 ms blip / 2 s,
REVERSED 4 Hz, PRECHARGE double blink, CC 1 Hz, CV long on, DISCHARGING 2 Hz,
RESTING short flash, IR 10 Hz, PAUSED 0.5 Hz, DONE steady. Faults: N blinks
then a pause - 2 OV, 3 DEAD_CELL, 4 TIMEOUT, 5 OVERTEMP, 6 ADC, 7 CURRENT,
8 SAFETY. Board alarm: all LEDs 2 Hz in sync; identify: all LEDs 5 Hz.

## Calibration

Defaults are 1.000 for every `CAL_V[k]`/`CAL_I[k]`; factors are limited to
0.90-1.10 and stored in NVS.

1. **Voltage**: insert a cell, measure it with a calibrated DMM directly at
   the cell terminals, enter the value in *Settings -> Calibration ->
   Reference V* of that channel, press *Cal V*. (`{"ch":k,"cmd":"calv","value":3.3012}`)
2. **Current**: start a charge (or discharge) on the channel, put a DMM in
   series (or use a calibrated clamp), enter the reading (negative while
   discharging), press *Cal I*. Repeat per channel; the shunt is +-1 %.
3. **Board temperature**: enter the true board temperature and press
   *Calibrate* (sets V25; diode 0.601 V at 25 C, -1.97 mV/K). Done
   automatically at first boot assuming 25 C.
4. Check: the ESP32 IO1 cross-check (`vchk` in `/api/status`) must stay
   within 60 mV of the ADS1115.

## Safety design

The hardware safety chain (INTERFACE.md section 6) isolates every cell when
SAFE_EN drops; the firmware is designed to fail into that state.

* **Heartbeat** (IO10) is a plain GPIO write at the end of every control-loop
  iteration (`Controller::step()`, edges every ~1 ms = ~500 Hz square wave;
  the hardware needs >= 100 Hz and rejects <= 50 Hz), executed only when the
  supervisor is happy. It is never generated by LEDC/RMT/timers. The control
  loop is a dedicated FreeRTOS task (priority 10, above the web server; it
  waits at most 3 ms for the shared lock) so slow HTTP clients cannot starve
  it; if it stalls, the hardware drops SAFE_EN within 23-33 ms; the task
  watchdog resets the chip after 3 s. SAFE_EN is low for ~50 ms after
  power-up (VREF settling); that is not treated as a fault.
* **Flash writes** (NVS) can stall the CPU longer than 23 ms during a sector
  erase, so settings/results are written only while no job is running (or
  just before a reboot, after the outputs are off); changes take effect in RAM
  immediately. OTA is refused while jobs run.
* **Heartbeat is stopped** (all jobs aborted, all-zero written to the
  74HC595, hardware isolates every cell; latched until *Acknowledge*) on:
  SAFE_RB lost while expected high (reason recorded: VIN, temperature,
  control-loop stall, otherwise E-STOP/unknown - SAFE_EN therefore cannot come
  back by itself when the E-STOP is released), ADC cross-check mismatch
  (ESP32 IO1 vs ADS1115 B+ > 60 mV, 3 consecutive checks), repeated
  I2C/ADS1115 failures, ADS1115 missing at boot, current > 0.1 A on a channel
  whose outputs are off ("stray current", e.g. a shorted MOSFET), CHG+DIS
  requested together (interlock). Acknowledging restarts the heartbeat; if
  the cause persists the alarm trips again.
* **VIN** outside 4.80-5.40 V for 1 s, **board** > T_BOARD_MAX + 7 C: abort all
  jobs (latched alarm). Board > 70 C: discharges paused, no new discharges;
  >= 50 C: ISET limited to 5; unreadable board sensor: treated as hot.
* **OV latch** (hardware, 3.78-3.87 V): isolates the cell and kills its
  charger; firmware detects it (CHG_EN on, I ~ 0, V >= 3.75 V -> `FAULT_OV`).
  The latch only releases when SAFE_EN drops, so *Reset* of a `FAULT_OV`
  channel (or *Acknowledge* while an OV fault exists) pauses the heartbeat
  for 120 ms as soon as no job is running on the board (shown as "OV latch
  release pending/active"; new jobs on that channel are refused until then).
* **Per channel**: V > V_ABS_MAX with the charger on -> `FAULT_OV`
  immediately, for 2 s at rest -> `FAULT_OV`; V >= V_MAX_CHG ends the charge;
  cell > 55 C pause / < 45 C resume, > 65 C `FAULT_OVERTEMP`; < 0 C no charging;
  NTC short or lost during a job -> `FAULT_ADC`; no or wrong-direction current,
  current above ISET, > 2.2 A -> `FAULT_CURRENT`; no valid measurement for
  3 s or any I2C error during a job -> `FAULT_ADC`; charge/discharge
  timeouts 30 h; precharge that does not recover the cell in 4 h -> dead.
* CHG_EN and DIS_EN are never set together (word builder interlock, tested),
  and every change between charge and discharge goes through >= 2 s of rest.
* Settings are clamped to LFP-safe ranges (e.g. V_MAX_CHG <= 3.65 V,
  V_MIN_DIS >= 2.30 V) whatever is sent to the API.
* OTA (web or ArduinoOTA) is refused while any job runs (unless forced);
  during an update the outputs are off and the heartbeat stops on purpose.

Practical notes: never leave lithium cells charging unattended in a place
where a fire could spread; use a fused 5 V supply sized for 8 x 1.7 A plus
fans; the hardware CV limit (3.575 V +-1.5 %) and OV latch (3.82 V) work
independently of this firmware.

## Known limitations / open points

* IO1 (ADC_VCHK) has a 1M/1M + 10 nF divider (tau 5 ms): the cross-check
  keeps the multiplexer on the channel >= 26 ms before reading IO1, which
  is done for one channel per scan cycle (full scan ~175 ms, >= 5 Hz/channel).
* Results finished while other jobs keep running are held in RAM until the
  board is idle (NVS write deferral); a power loss before that loses them.
* The ESP32-C3 ADC at 11 dB saturates around 2.9-3.1 V, below the 3.2 V
  "no NTC" threshold of INTERFACE.md section 5; readings that convert to
  < -20 C are therefore also treated as "no NTC fitted".
* An open B- *sense* wire cannot be told apart reliably from the data the
  hardware provides; the B- diagnostic only gives warnings (idle offset,
  CONTACT_WARN).
* While an IR pulse runs (~1.1 s) the other 7 channels are not sampled
  (coulomb counting interpolates across the gap; hardware protections remain
  active).
* The interface leaves the sign convention of the section 7.1 formula open; the
  firmware reports positive resistances for both pulse types
  (R = dV/dI with signed current) and the pulse current with its sign.
* Unauthenticated LAN API for commands (settings/OTA can be protected with the
  admin password). Do not expose the boards to untrusted networks.

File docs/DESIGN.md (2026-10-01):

# LFP-8 design notes

LFP-8 is an 8-channel charger, discharger and internal-resistance tester for
LiFePO4 32140/33140 cells (3.2 V, ~15 Ah). Five identical boards test **40 cells
at once**. Each board runs on one 5 V supply and reports over Wi-Fi through its
ESP32-C3.

```
            +5V bus (5.20 V, ≤ 8.5 A)                       ESP32-C3 ── Wi-Fi / web UI
                │                                              │ SPI-like      │ I²C
   ┌────────────┼──────── channel k (×8) ─────────────┐   4×74HC595 (32 bit)  ADS1115
   │  Q1 P-FET ─ D1 SS34 ─ R6 1.2 Ω ─┬─ BP ─ PTC ─ B+F │   CHG/DIS/LED ×8     ▲ ▲
   │  (linear CC/CV pass)            │                 │   mux select, ISET   │ │
   │       ▲ CC amp ◄── R6 drop      ├─ 4×11 Ω ─ Q4 ─ GND  (discharge 1.07 A) │ │
   │       ▲ CV amp ◄── Kelvin B+S/B−S                 │                      │ │
   │  OV latch, UV backstop, reverse sentinel          │   5× CD4051 ─────────┘ │
   │  B− ─ Q5 ┐ back-to-back ┌ Q8 ─ 0.1 Ω shunt ─ GND  │   (B+S, B−S, SH+, SH−, NTC)
   └──────────┴──────────────┴─────────────────────────┘
        SAFE_EN = watchdog ∧ rail UV ∧ rail OV ∧ board OT ∧ E-STOP  → isolates every cell
```

## Why this architecture

* **Cheapest possible BOM that still measures properly.** Every channel is
  built from JLCPCB *basic* parts (LM324, SOT-23 MOSFETs, BJTs, 0603 passives).
  Only six part types are *extended*: ESP32-C3 module, ADS1115, the 0.1 Ω shunt,
  the 1.2 Ω and 11 Ω 2512 resistors and the PTC fuse. There is no charger IC per
  channel. A discrete linear CC/CV loop costs about $0.15 per channel and has
  no inductor, so there is no switching noise in the Kelvin measurements.
* **One 5 V supply.** An LFP cell charges to 3.6 V, so a linear charger from
  5.2 V wastes at most (5.2 − 3.2 V) × 1 A ≈ 2 W per channel. It is spread over
  the pass FET, the Schottky diode and the 1.2 Ω ballast. The ballast also
  senses the CC current, so the FET only dissipates ≈ 0.3 W. Five boards need a
  common 5 V / 50 A supply; a 5 V / 10 A brick per board also works.
* **Resistive discharge.** 4 × 11 Ω 2512 resistors (2.75 Ω) switched by an
  AO3400A draw 1.07 A at the 3.29 V LFP plateau (≈ 0.07 C for a 15 Ah cell).
  That is slow but adequate for a capacity test and needs no regulation. The
  ADS1115 measures the real current through the Kelvin shunt, so the
  coulomb counter does not care that the current falls slightly with voltage.
* **True 4-wire (Kelvin) measurement.** Each cell has force and sense wires at
  both terminals (6-pin JST-XH: B+F, B+S, B−S, B−F, NTC, GND). The ADS1115
  measures the cell differentially between the sense wires through the
  multiplexers, and the current differentially across the Kelvin pads of the
  shunt. The CV loop and every protection comparator also use the sense wires,
  so contact resistance (often 30–100 mΩ with pogo pins) affects neither the
  charge voltage nor the IR result. If a sense wire breaks, a 100 Ω fall-back
  resistor ties it to its force wire, so the channel degrades gracefully.

## Channel circuit (`hardware/gen/lfp8_circuit.py`, `build_channel`)

| Block | Parts | Function |
|---|---|---|
| Pass device | Q1 AO3401A, Q2 MMBT3904 (1 k emitter degeneration), R3 10 k, C9 1 nF | Q2 sinks a gate current set by the error amps, so Q1 is a voltage-controlled current source |
| Error amps (LM324 A/B) | CC amp: differential integrator across the 1.2 Ω ballast vs VS (balanced, 47 nF / 1 k). CV amp: differential Kelvin B+S − B−S vs 0.38 × VREF (10 nF / 10 k) | The lower of the two outputs wins (diode min-select D2/D3 into the Q2 base node NB) |
| Charge enable | R7/R8 from `CHG_EN_k`, D7/D8 anti-windup into CHG_EN | Soft start; the integrators start from zero on every enable |
| Interlock | Q3 2N7002 on NB driven by the discharge driver output | The charger cannot run while the load is on |
| Discharge | LM324 C: drives Q4 when `DIS_EN_k` is high **and** Kelvin V_cell > UV threshold (positive feedback gives 2.22 V trip / 2.59 V re-arm) | Hardware backstop: a stuck firmware can never over-discharge a cell |
| OV latch | LM324 D: differential comparator with heavy positive feedback | Trips at 3.82 V; pulls GEN (gate enable) low, which isolates the cell and kills the charger drive. Releases when the cell is removed or SAFE_EN drops |
| Isolation | Q5 + Q8 AO3400A back-to-back in the B− path, gates driven from +5V via Q9 (PNP) and referenced to their common source with R53 22 k | Blocks current in both directions when off, including when the board is unpowered and with a reversed cell |
| Reverse sentinel | Q6 NPN, Q7 PNP + Q11 NPN, 150 k / 91 k divider | Pulls GEN low when B− is more than ~1.6 V above B+ in either power state |
| Measurement | 0.1 Ω Kelvin shunt R50, 1 k series resistors + 10 nF into the CD4051 muxes, NTC pull-up | ADS1115 AIN0−AIN1 (cell) and AIN2−AIN3 (current) |
| Fuse | 2 A hold PTC in B+ force | Board-side short or a stuck pass FET into a short cell |

All the numbers in the table below come from ngspice (behavioural LM324 /
LM393 / TL431, VDMOS FETs, an LFP cell model with OCV curve and RC polarisation),
see `sim/` and [TEST_REPORT.md](TEST_REPORT.md).

| Parameter | Value |
|---|---|
| CC charge current (ISET 4, 5.20 V rail) | 0.97–1.00 A (passive ceiling ≈ (V_IN − 0.38 − V_cell)/1.5 Ω) |
| ISET codes 0–7 | 0, 0.26, 0.52, 0.77, 1.0, 1.0, 1.0, 1.0 A at 3.3 V cell |
| CV voltage | 3.576 V nominal, 3.51–3.62 V over tolerances (Monte Carlo, 100 runs) |
| OV latch | 3.82 V nominal, 3.78–3.87 V |
| Discharge current | 1.07 A at 3.29 V |
| Discharge UV backstop | 2.22 V under load, no restart below 2.59 V |
| IR measurement error (Kelvin) | +0.6 % (8.13 vs 8.08 mΩ ohmic, 11.60 vs 11.54 mΩ DC) |
| Loop stability | CC phase margin ≥ 90° (fc 26 Hz – 1.3 kHz over 23 corners), CV ≥ 94° |
| Unpowered drain per cell | 81 µA |

## Board-level safety chain (`SAFE_EN`)

Two LM393s form an open-collector wired-AND. SAFE_EN drives the 74HC595 `/OE`
(through Q8 2N7002), so when it is low every control output goes high-Z and is
pulled to its off state. It also pulls every channel's GEN node low, which
isolates every cell.

| Input | Implementation | Trip |
|---|---|---|
| Watchdog | `HEARTBEAT` (ESP32 IO10, ≥ 100 Hz) → 100 nF / BAT54 charge pump → comparator vs VREF divider | 23–33 ms after the toggling stops; ≤ 50 Hz rejected |
| Rail UV | 8.2 k / 10 k divider vs VREF, 1 M hysteresis | 4.48 V |
| Rail OV | 12 k / 10 k divider vs VREF | 5.49 V (also catches a failed VREF) |
| Board over-temperature | diode-connected MMBT3904 (0.601 V @ 25 °C, −1.97 mV/K) vs VREF divider | 70–95 °C |
| E-STOP | SW1 shorts SAFE_EN to GND | 126 µs to isolation |

## Supply

* `+5V` input through a terminal block (J1). An SMBJ6.0A TVS and an SS54
  reverse-polarity crowbar sit next to it. The supply must be current-limited
  or fused (≤ 15 A); a reversed PSU otherwise burns the SS54.
* AMS1117-3.3 for the ESP32. CJ431 2.495 V shunt reference (VREF) for every
  threshold.
* ISET DAC: three 74HC595 outputs into a binary-weighted resistor network
  (10 k / 20 k / 40.2 k / 4.3 k) buffered by an LM358. It scales with the rail,
  which keeps the charger's headroom constant.

## PCB

* 216 × 146 mm, 2 layers, 1.6 mm FR-4, 1 oz copper, JLCPCB standard rules.
  Minimum 0.2 mm clearance, 0.25 mm tracks, 0.3 mm vias.
* Eight 25 mm channel columns. The JST-XH connectors are on the bottom edge,
  with the power stage (pass FET, Schottky, ballast, load bank, isolation FETs,
  shunt) directly above them and the analogue small-signal parts above that.
  The common section (ESP32-C3 with its antenna on the top edge, shift
  registers, multiplexers, ADC, safety chain) runs along the top.
* `+5V` bus: 6.5 mm wide on both layers along the bottom edge, fed from J1 by a
  5 mm wide feed on both layers. Each channel taps it with a 1 mm spur.
* GND: solid plane on B.Cu, plus a GND pour on F.Cu.
* Every 1 A path is pre-routed as a locked 0.8–1.6 mm track (`make_pcb.py`,
  `ch_preroutes`). The load-bank pads sit on solid copper zones for heat
  spreading. Freerouting routes everything else.
* The board needs a fan while discharging. 8 channels × 4.1 W = 33 W of heat
  goes mostly into the 11 Ω resistors. The board stand in `mechanical/` holds
  a fan under the board, and the firmware runs it from the `FAN` header (J2).

## Single source of truth

```
hardware/gen/lfp8_circuit.py ──► sim/spicelib.py    → ngspice benches (sim/tests)
                             ├─► make_sch.py        → hardware/kicad/*.kicad_sch
                             ├─► make_pcb.py        → placement + power pre-routes → DSN
                             │   route_pcb.py       → Freerouting → routed board
                             ├─► verify_netlist.py  → schematic == PCB == DSL (pin by pin)
                             └─► make_fab.py        → Gerbers, drill, BOM, CPL
```

The same Python netlist feeds the simulator, the schematic and the PCB, so the
simulated circuit is, pin for pin, the circuit that gets manufactured.
`verify_netlist.py --pcb` proves it after every change.

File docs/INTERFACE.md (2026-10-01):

# LFP-8 Hardware ⇄ Firmware Interface Specification

This document is the contract between the **LFP-8 channel board** (8 LiFePO4
channels per board, 5 boards = 40 cells) and the ESP32-C3 firmware. If the
schematic and this document disagree, the schematic generator
(`hardware/gen/lfp8_circuit.py`) is the source of truth and this file must be
updated.

## 1. Electrical domains

| Rail | Source | Used by |
|---|---|---|
| `+5V`  | External PSU, **set to 5.20 V** (5.00–5.25 V allowed) | Charge path, LM324/LM393/LM358, 74HC595, CD4051, ADS1115 |
| `+3V3` | AMS1117-3.3 from `+5V` | ESP32-C3-WROOM-02 only (+ NTC pull-ups) |
| `VREF` | CJ431 shunt reference 2.495 V | CV set-point, OV/UV thresholds, watchdog/rail/temp thresholds |

The ESP32 (3.3 V) talks to the 5 V domain through BSS138 level shifters
(I²C and the shift-register lines).

## 2. ESP32-C3-WROOM-02 GPIO map

| GPIO | Module pin | Direction | Net | Function |
|---|---:|---|---|---|
| IO0  | 18 | ADC1_CH0 in | `ADC_NTC`  | Output of mux D (cell NTC divider, 0–3.3 V) |
| IO1  | 17 | ADC1_CH1 in | `ADC_VCHK` | Mux A output ÷ 2 (1M/1M + 10 nF, τ = 5 ms) – independent cross-check of the selected cell's B+ sense. Keep the mux on that channel ≥ 25 ms before reading |
| IO2  | 16 | out (strap, pulled high) | `RCLK3` | 74HC595 storage-register clock (latch), rising edge latches |
| IO3  | 15 | ADC1_CH3 in | `ADC_VIN`  | `+5V` × 0.3197 (100k over 47k divider) |
| IO4  |  3 | ADC1_CH4 in | `ADC_TBRD` | Board temperature: Vbe of diode-connected MMBT3904 biased at ≈100 µA (0.601 V @ 25 °C, −1.97 mV/K) |
| IO5  |  4 | I²C SDA | `SDA3` | ADS1115 (addr 0x48) via level shifter, 100–400 kHz |
| IO6  |  5 | I²C SCL | `SCL3` | |
| IO7  |  6 | out | `SER3` | 74HC595 serial data |
| IO8  |  7 | out (strap, pulled high) | `SRCLK3` | 74HC595 shift clock, rising edge shifts |
| IO9  |  8 | in (strap, BOOT button to GND, pull-up) | `BOOT` | User button after boot (active low) |
| IO10 | 10 | out | `HEARTBEAT`| Hardware watchdog charge pump input. **Must be toggled by software in the main control loop, ≥ 100 Hz square wave (toggle at least every 5 ms)** (see §6) |
| IO18 | 13 | USB D− | `USB_DN` | Native USB-Serial/JTAG (programming + console) |
| IO19 | 14 | USB D+ | `USB_DP` | |
| IO20 | 11 | in | `SAFE_RB`  | Read-back of `SAFE_EN` (high = hardware allows power stages) |
| IO21 | 12 | out | `FAN_PWM`  | Fan low-side MOSFET gate (PWM allowed, 25 kHz recommended) |
| EN |  2 | – | `EN` | Reset button |

Boot straps: IO2 and IO8 are held high by the level-shifter pull-ups, IO9 by
its pull-up. Do not drive IO2/IO8 low before `setup()` runs.

## 3. Shift-register chain (4 × 74HC595, 32 bits)

* Firmware shifts a 32-bit word **MSB first** on `SER3`/`SRCLK3`, then pulses
  `RCLK3`. After that, **bit *i* of the word appears on output position *i***,
  where position = 8·(chip−1) + (QA=0 … QH=7).
* The 74HC595 `OE` pin is driven by hardware (`OE_N = NOT SAFE_EN`). When the
  hardware safety chain is not satisfied, all outputs are high-Z and pulled
  to their safe (off) state. Firmware must still write 0s on any fault.
* Max shift clock: 1 MHz (BSS138 shifters). Use ≤ 400 kHz.

| Bits | Name | Meaning (1 = active) |
|---|---|---|
| 3·(k−1)+0 | `CHG_EN_k` | Enable charger of channel k (k = 1…8) |
| 3·(k−1)+1 | `DIS_EN_k` | Enable discharge load of channel k |
| 3·(k−1)+2 | `LED_k` | Channel LED (green) |
| 24 | `MUX_S0` | CD4051 select A (all five muxes in parallel) |
| 25 | `MUX_S1` | CD4051 select B |
| 26 | `MUX_S2` | CD4051 select C |
| 27 | `ISET_B0` | Charge-current DAC bit 0 (LSB) |
| 28 | `ISET_B1` | Charge-current DAC bit 1 |
| 29 | `ISET_B2` | Charge-current DAC bit 2 (MSB) |
| 30 | `AUX_OUT` | Spare open output on header J_AUX pin 3 |
| 31 | – | unused, write 0 |

Mux select value `n = S2·4 + S1·2 + S0` selects **channel k = n + 1**.

**Interlock:** hardware forces the charger off while the discharge driver
output is high, but firmware must never set `CHG_EN_k` and `DIS_EN_k`
together.

## 4. Charge current DAC (board-wide)

`ISET = ISET_B2·4 + ISET_B1·2 + ISET_B0` (0…7) sets the CC limit of **all
8 channels** of the board (`I = VS / 1.2 Ω`, VS from a 3-bit DAC fed by the
5 V shift-register outputs, so it scales with the rail):

| ISET | 0 | 1 | 2 | 3 | 4 | 5 | 6 | 7 |
|---|---|---|---|---|---|---|---|---|
| set-point @ 5.20 V (A) | 0 (charger blocked) | 0.265 | 0.532 | 0.797 | 1.064 | 1.328 | 1.595 | 1.860 |
| simulated @ 3.30 V cell (A) | 0.000 | 0.260 | 0.517 | 0.772 | 1.004 | 1.003 | 1.003 | 1.003 |

`ISET_LUT_A[] = {0, 0.265, 0.532, 0.797, 1.064, 1.328, 1.595, 1.860}` × `V_IN/5.20`.
The linear charger also has a **passive current ceiling** set by the 1.2 Ω
ballast, the SS34 diode and the cell wiring:
`I_max ≈ (V_IN − 0.38 V − V_cell) / 1.5 Ω` (≈ 1.0 A at 3.3 V with a 5.20 V
rail). Codes above 4 therefore only help for low cell voltages. Default
ISET = 4. The *measured* current is used for all accounting.

**Hardware CV limit:** 3.576 V nominal; component tolerances give
3.51–3.62 V (Monte Carlo, 100 runs). Firmware still stops at `V_MAX_CHG`.

**Thermal policy (pass MOSFET is a SOT-23):** continuous CC only when
`V_cell ≥ 3.05 V`. Between 2.80 and 3.05 V pulse `CHG_EN_k` at 50 % duty
(1 s period); between 2.00 and 2.80 V precharge at 20 % duty; below 2.00 V
refuse (`DEAD_CELL`).

## 5. Analog measurement chain

Five CD4051 multiplexers share the select lines; for channel k:

| Mux | Input k | Output goes to | Signal |
|-----|---|---|---|
| A | `B+S_k` (via 1 kΩ) | ADS1115 **AIN0** and ESP32 IO1 (÷2) | Cell + Kelvin sense |
| B | `B−S_k` (via 1 kΩ) | ADS1115 **AIN1** | Cell − Kelvin sense |
| C | `SHP_k` (via 1 kΩ) | ADS1115 **AIN2** | Shunt top (Kelvin) |
| E | `SHN_k` (via 1 kΩ) | ADS1115 **AIN3** | Shunt bottom (Kelvin) |
| D | `NTC_k` | ESP32 IO0 | Cell NTC (10 k pull-up to 3.3 V) |

ADS1115 (address 0x48, VDD = 5 V):

| Quantity | MUX config | PGA | Formula |
|---|---|-----|---|
| Cell voltage | AIN0 − AIN1 (`0b000`) | ±4.096 V (LSB 125 µV) | `V_cell = code · 4.096/32768 · CAL_V[k]` |
| Cell current | AIN2 − AIN3 (`0b011`) | ±0.256 V (LSB 7.8125 µV) | `I_cell = code · 0.256/32768 / R_SHUNT · CAL_I[k]` with `R_SHUNT = 0.100 Ω` |
| Neg. sense vs shunt-gnd (diagnostic) | AIN1 − AIN3 (`0b010`) | ±1.024 V | B− contact / wiring resistance: `R = V/I − 0.156 Ω` while ≥ 0.2 A flows; > 300 mΩ ⇒ `contact_warn` |

* **Sign convention:** `I_cell > 0` = charging, `I_cell < 0` = discharging.
* `CAL_V[k]`, `CAL_I[k]` default to 1.000 (stored in NVS, editable on the web UI).
* After changing the mux select, wait ≥ 2 ms before starting a conversion
  (1 kΩ + mux R into 10 nF filter caps).
* Use 128 SPS for routine scanning, 860 SPS for IR pulses.
* `V_cell` reads ≈ −1 V to −3.3 V for a **reversed cell** (hardware isolates it
  within ~50 µs; firmware must flag `REVERSED`).
* `V_cell` < 0.5 V with no current ⇒ `EMPTY` (no cell; an empty slot reads ≈ 0.03 V). A full channel scan
  (both conversions × 8 channels) at 128 SPS takes ≈ 150 ms.

ESP32 ADC (12-bit, use `analogReadMilliVolts`, 11 dB attenuation):

| Pin | Conversion |
|-----|---|
| IO0 `ADC_NTC` | `R_ntc = 10k · V/(3.3 − V)`; Beta model B=3950, R25=10k. V > 3.2 V ⇒ no NTC fitted |
| IO1 `ADC_VCHK` | `V_B+S = 2 · V`. Must agree with ADS1115 `B+S` within ±60 mV (ESP32 ADC is coarse) else `ADC_FAULT` |
| IO3 `ADC_VIN` | `V_IN = V / 0.3197` |
| IO4 `ADC_TBRD` | `T = 25 + (V − V25)/(−0.00197)` °C, `V25` calibrated at first boot assuming ambient (default 0.601 V) |

## 6. Hardware safety chain (`SAFE_EN`) – what firmware must respect

`SAFE_EN` is the AND (open-collector wired-AND) of:

1. **Watchdog:** `HEARTBEAT` square wave ≥ 100 Hz (a charge pump keeps a
   comparator happy; ≤ 50 Hz is rejected). If the toggling stops (stuck high
   or low) `SAFE_EN` drops within 23–33 ms. `SAFE_EN` also stays low until
   VREF has settled (≈ 50 ms after power-up).
   **Never use LEDC/RMT/timer hardware to generate the heartbeat** – it must
   come from the main control loop so a hung loop really trips the watchdog.
2. **Rail UV:** `+5V` > 4.48 V (with ~40 mV hysteresis).
3. **Rail OV:** `+5V` < 5.50 V.
4. **Board over-temperature:** board sensor < ≈ 80–90 °C (trips between 70 and 95 °C in simulation).
5. **E-STOP button** not pressed.

When `SAFE_EN` is low: every cell is galvanically isolated by its low-side
MOSFET, the 74HC595 outputs are high-Z, chargers and loads are off.
Firmware behaviour on `SAFE_RB` = low while it expected high: abort all
channel jobs, record the reason (heartbeat stopped? VIN? temperature? e-stop),
write all-zero to the shift registers, show the alarm on the web UI.

Per-channel hardware protections that firmware will observe:

| Protection | Trip | Firmware sees |
|---|---|---|
| CV limit (charger) | Kelvin V_cell ≥ 3.576 V (3.51–3.62) | current tapers to 0 |
| OV latch | Kelvin V_cell ≥ 3.82 V (3.78–3.87) | cell isolated **and** charger drive killed; releases only when V_cell < 2.74 V (cell removed) **or when SAFE_EN goes low** — firmware can reset all latches by stopping the heartbeat for ≥ 100 ms (firmware uses 120 ms) |
| Discharge UV backstop | Kelvin V_cell < 2.22 V under load; discharge cannot (re)start below 2.59 V | discharge current stops; use a charge pulse for IR on cells below 2.6 V |
| Reverse polarity | B− more than ~1.6 V above B+ | cell isolated (~0.1 mA residual), charger drive killed; `V_cell` negative |
| Unpowered | PSU off | cell isolated by back-to-back MOSFETs; residual drain ≈ 80 µA via the sense networks (≈ 0.4 %/month) |
| PTC fuse 2 A hold | short / > 4 A | `V_cell` collapses / channel dead until PTC cools |
| Charge path current limit | `I_chg` > ISET setpoint | measured current never exceeds setpoint (+10 %) |

## 7. Firmware cell-test policy (LiFePO4 33140, 15 Ah nominal)

| Parameter | Default | Notes |
|---|---|---|
| `V_MAX_CHG` | 3.60 V | firmware stops CV phase if exceeded (hardware CV is 3.575 V) |
| `V_ABS_MAX` | 3.70 V | > this for 2 s with CHG_EN=0 ⇒ `OV_FAULT` |
| `I_TERM` | 0.05 A | end of charge when CV current < I_TERM for 60 s |
| `V_MIN_DIS` | 2.50 V | discharge cut-off (measured under load) |
| `V_PRECHARGE` | 2.80 V | below this: pulse charge 1 s on / 4 s off |
| `V_DEAD` | 2.00 V | below this: refuse to charge (`DEAD_CELL`) |
| `T_CELL_MAX` | 55 °C | pause channel; resume < 45 °C |
| `T_BOARD_FAN` | 40 °C | fan 100 % above, else 40 % when any channel active |
| `T_BOARD_MAX` | 70 °C | firmware derates (stop new discharges) |
| `MAX_CHG_TIME` | 30 h | timeout ⇒ `TIMEOUT` |
| `MAX_DIS_TIME` | 30 h | |
| Capacity | coulomb counting at ≥ 5 Hz | report mAh and mWh |
| DC-IR | see §7.1 | report mΩ |

### 7.1 Internal resistance ("resistance calculator")

For each cell (on demand or automatically at 50 % SoC during a test):

1. Charger and load off; rest ≥ 5 s. Measure `V0`, `I0` (16-sample average,
   mux locked on the channel).
2. Enable `DIS_EN_k` (≈ 1.05 A). Sample `V_cell`/`I_cell` alternately at
   860 SPS for 1.0 s.
3. `R_ohmic = (V0 − V(10 ms)) / (I(10 ms) − I0)` — fast (≈ AC-IR like).
4. `R_dc = (V0 − V(1 s)) / (I(1 s) − I0)` — IEC 61960-style DC-IR.
5. Disable load. Report both in mΩ with the measurement current.

If the cell is below 2.65 V (UV backstop blocks the load), do the same with a
charge pulse instead (`CHG_EN_k`, ISET 4) and report with the sign flipped.

## 8. Fixed board constants

```
R_SHUNT        = 0.100 Ω  (2512, ±1 %, 50 ppm/K)
R_CHG_BALLAST  = 1.2 Ω    (charge path, also the CC sense resistor)
R_LOAD         = 2.75 Ω   (4 × 11 Ω 2512 in parallel) -> ≈1.07 A at 3.29 V, 1.2 A at 3.6 V
DIV_VCHK       = 0.5      (1M/1M, 10 nF)
DIV_VIN        = 0.3197   (+5V → 100k → ADC_VIN → 47k → GND)
NTC_PULLUP     = 10 kΩ to 3.3 V
VREF           = 2.495 V
CV_SET         = 3.576 V nominal (differential Kelvin sense)
OV_TRIP        = 3.82 V (latching, release 2.74 V or SAFE_EN low)
UV_TRIP        = 2.22 V under load (DIS_EN=1), re-arm 2.59 V
TBRD           = 0.601 V @ 25 °C, −1.97 mV/K
```

## 9. Multi-board networking (firmware convention)

* Each board has a `board_id` 1–5 (NVS, default from MAC) and hostname
  `lfp8-<id>`; channel numbers on the UI are global: `(board_id−1)·8 + k`.
* Boards announce themselves with a UDP broadcast on port **45454** every 2 s:
  `{"t":"hello","id":<id>,"ip":"x.x.x.x","fw":"x.y.z"}`.
* Every board serves the full dashboard at `/` and `GET /api/status`
  (JSON for its own 8 cells), `GET /api/peers`, `POST /api/cmd`. The
  dashboard aggregates all peers by fetching `http://<peer>/api/status`
  (CORS `Access-Control-Allow-Origin: *`).

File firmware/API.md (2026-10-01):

# LFP-8 HTTP / UDP API

Every board serves the same API on port 80. All JSON responses carry
`Access-Control-Allow-Origin: *` (plus `-Methods`/`-Headers: *`), so the
dashboard of one board can aggregate all boards. `OPTIONS` pre-flight requests
on any path are answered with `204`. Responses are `Cache-Control: no-store`.

Numbers that are unknown/not measured are `null` (never `NaN`). Channel `k`
is the **local** channel 1..8; `g = (board_id-1)*8 + k` is the global cell
number used on the UI. Current sign: **I > 0 charging, I < 0 discharging**.

Write requests accept a JSON body with `Content-Type: text/plain` (a CORS
"simple request", no pre-flight needed) or `application/json`.
Errors: `{"ok":false,"err":"reason"}` with HTTP 400 (bad request), 404, 409
(refused by the safety logic / state machine), 503 (controller busy) or 500.

| Method | Path | Purpose |
|---|---|---|
| GET  | `/` | dashboard (single page, embedded, works offline) |
| GET  | `/api/status` | board + 8 channels |
| GET  | `/api/history?ch=k` | 24 h V/I history of channel k (1 sample / 30 s) |
| GET  | `/api/irtrace` | samples of the last IR pulse on this board |
| GET  | `/api/peers` | boards discovered via UDP |
| POST | `/api/cmd` | channel / board commands |
| GET  | `/api/config` | settings (passwords are never returned) |
| POST | `/api/config` | change settings (admin password if set) |
| GET  | `/api/export.csv` | results of this board as CSV |
| POST | `/api/pack` | pack builder (S x P grouping) |
| GET  | `/update` | minimal OTA upload page |
| POST | `/update` | firmware upload (multipart, field `fw`) |

## GET /api/status

```json
{"id":2,"fw":"1.0.0","host":"lfp8-2","ip":"192.168.1.52","mode":"STA","rssi":-61,"dup_id":false,"uptime":5321,
 "board":{"vin":5.012,"tb":31.4,"safe":true,"safe_rb":true,"hb":true,"power":true,"meas":true,"fan":40,
          "iset":4,"iset_eff":4,"iset_a":0.970,"hot":false,"maint":false,"ident":false,
          "alarm":"","alarm_text":"","cond":"","loop_max_us":1180,"overruns":0,"i2c_err":0,
          "safe_losses":0,"scan_ms":168,"ir_busy":false,"ir_ch":0,"latch_reset":""},
 "ch":[{"k":1,"g":9,"st":"CHARGING_CC","prog":"captest","step":"charge","pause":"","valid":true,
        "v":3.3412,"i":0.9693,"t":24.6,"ntc":"ok","vchk":3.452,"vbm":0.1842,"bm_warn":false,
        "contact_mohm":34,"contact_warn":false,"ov_pending":false,"pulse_pct":0,
        "chg":true,"dis":false,"mah":1234.5,"mwh":4101.2,"target_mah":null,"el":4523,"step_el":4523,
        "cap_mah":null,"cap_mwh":null,"cap_s":0,"dis_term":"","chg_mah":null,"chg_mwh":null,"chg_term":"",
        "store_mah":null,"ir_ohm":null,"ir_dc":null,"ir_i":null,"ir_v0":null,"ir_mode":"","ir_at":0,"msg":""}, ...]}
```

Board fields: `vin` +5V rail (V), `tb` board temperature (C), `safe` debounced
SAFE_RB, `safe_rb` raw pin, `hb` heartbeat allowed by the supervisor, `power`
power stages may be enabled, `meas` measurements running (SAFE high),
`fan` %, `iset` configured DAC code, `iset_eff` after derating (>= 50 C limits
to 5), `iset_a` nominal current, `hot` board > T_BOARD_MAX (discharges
paused), `maint` OTA maintenance, `alarm` latched alarm
(`SAFE_LOST`, `VIN`, `BOARD_OVERTEMP`, `ADC_MISMATCH`, `I2C`, `ADS1115_MISSING`,
`STRAY_CURRENT`, `INTERLOCK`) with `alarm_text`, `cond` informational
condition, `loop_max_us` longest control-loop gap in the last 10 s,
`scan_ms` time for a full 8-channel scan, `latch_reset` `pending` (OV latch
release waits for an idle board) / `active` (heartbeat paused 120 ms) / empty.

Channel fields: `st` state: `EMPTY IDLE REVERSED CHARGING_PRE CHARGING_CC
CHARGING_CV DISCHARGING RESTING IR_MEASURE PAUSED DONE FAULT_OV
FAULT_DEAD_CELL FAULT_TIMEOUT FAULT_OVERTEMP FAULT_ADC FAULT_CURRENT
FAULT_SAFETY`; `prog` `none|charge|discharge|captest|ir`; `step`
`none|charge|rest_chg|discharge|rest_dis|storage|rest_ir|ir`; `pause`
`cell_hot|cell_cold|board_hot|iset0`; `ntc` `ok|none|short|invalid`;
`vchk` ESP32 IO1 cross-check of B+ (V), `vbm` B- diagnostic AIN1-AIN3 (V,
±1.024 V range); `contact_mohm` implied B- force-path (wire + contact)
resistance `vbm/I - 0.156 ohm`, estimated while >= 0.2 A flows (null if
unknown), `contact_warn` true above 300 mOhm (warning only), `bm_warn` B-
offset with no current (open B- wire?, warning only); `ov_pending` OV latch
release pending for this channel; `pulse_pct` 20/50 during pulsed charging
(thermal policy), else 0;
`chg`/`dis` actual CHG_EN/DIS_EN bits; `mah`/`mwh` live counter of the current
step (charged or discharged); `el`/`step_el` elapsed seconds of job/step.
Results (kept until the next job or a channel `reset`, persisted in NVS):
`cap_mah`/`cap_mwh`/`cap_s` discharge capacity to V_MIN_DIS and its duration,
`dis_term` (`cutoff|uv_backstop`), `chg_mah`/`chg_mwh`/`chg_term`
(`i_term|plateau|v_max`) last full charge, `store_mah` storage charge,
`ir_ohm` (10 ms) and `ir_dc` (1 s) resistance in mOhm, `ir_i` pulse current
(A, signed), `ir_v0` rest voltage, `ir_mode` `dis|chg`, `ir_at` uptime (s).

## GET /api/history?ch=k

```json
{"ch":1,"g":9,"interval":30,"count":2880,"age_s":12,"fmt":"mv,ma pairs, oldest first",
 "d":[3301,0,3305,968,null,null, ...]}
```

`d` holds `count` pairs (mV, mA), oldest first; the newest pair is `age_s`
seconds old. `null,null` = no valid measurement in that interval. Use
`d.length/2` as the authoritative count (the ring may advance while streaming).

## GET /api/irtrace

```json
{"valid":true,"ch":3,"g":11,"ok":true,"err":"","mode":"dis","v0":3.3001,"i0":0.0001,
 "v_10ms":3.2908,"i_10ms":-1.1462,"v_1s":3.2869,"i_1s":-1.1463,"r_ohmic_mohm":8.067,"r_dc_mohm":11.471,
 "v":[[0.58,3.2911],[2.91,3.2910], ...],"i":[[1.75,-1.1462], ...]}
```

`v`/`i` are `[ms after load on, value]`, decimated to <= 220 points.

## GET /api/peers

```json
{"self":{"id":1,"ip":"192.168.1.51","fw":"1.0.0","host":"lfp8-1"},"dup_id":false,
 "peers":[{"id":2,"ip":"192.168.1.52","fw":"1.0.0","age":0.8}]}
```

## POST /api/cmd

Channel commands (`ch` = local channel 1..8):

| Body | Effect |
|---|---|
| `{"ch":k,"cmd":"charge"}` | charge: 20 % duty below 2.80 V, 50 % duty below 3.05 V, then CC/CV; refuses below 2.00 V; ends on current taper |
| `{"ch":k,"cmd":"discharge"}` | discharge to 2.50 V, reports mAh/mWh (refused below 2.62 V) |
| `{"ch":k,"cmd":"captest"}` | charge -> rest -> discharge -> rest -> storage charge (50 % by Ah) -> rest -> IR |
| `{"ch":k,"cmd":"ir"}` | rest >= 5 s, IR pulse (section 7.1) |
| `{"ch":k,"cmd":"stop"}` | stop the job (results kept) |
| `{"ch":k,"cmd":"reset"}` | clear a fault **and the results** of the channel; for `FAULT_OV` also schedules the OV-latch release (heartbeat pause >= 100 ms when no job runs on the board) |
| `{"ch":k,"cmd":"calv","value":3.3012}` | set CAL_V[k] so that V reads the reference (cell present) |
| `{"ch":k,"cmd":"cali","value":-1.052}` | set CAL_I[k] from a reference current (>= 0.2 A flowing) |

Board commands:

| Body | Effect |
|---|---|
| `{"cmd":"iset","value":n}` | charge-current DAC 0..7 (persisted; >= 6 only below 50 C) |
| `{"cmd":"stop"}` / `{"cmd":"stopall"}` | stop all channels |
| `{"cmd":"ack"}` (or `reset` without `ch`) | acknowledge latched board alarms; restarts a stopped heartbeat (VIN / over-temperature alarms only clear once the cause is gone); schedules the OV-latch release if a channel is in `FAULT_OV` |
| `{"cmd":"identify"}` | blink all LEDs for 10 s |
| `{"cmd":"caltb","value":24.5}` | calibrate the board temperature sensor to the given C |
| `{"cmd":"reboot"}` | restart the board (outputs off first) |

Response: `{"ok":true}` or `{"ok":false,"err":"..."}` (HTTP 409 when refused,
e.g. `"dead cell (V < V_DEAD) - refusing to charge"`, `"no cell"`,
`"power stages not enabled (SAFE/alarm)"`).

## GET / POST /api/config

GET returns all settings; POST accepts any subset of the same keys (values
are clamped to safe ranges; malformed values are rejected and nothing is
changed). With an admin password set, POST requires HTTP basic auth (user
`admin`).

```json
{"board_id":1,"iset":4,"v25":0.6400,"v_max_chg":3.600,"v_abs_max":3.700,"i_term":0.050,"t_term_s":60,
 "v_min_dis":2.500,"v_precharge":2.800,"v_cc_min":3.050,"v_dead":2.000,"t_cell_max":55.0,"t_cell_resume":45.0,
 "t_cell_fault":65.0,"t_cell_min_chg":0.0,"t_board_fan":40.0,"t_board_max":70.0,"max_chg_h":30.0,
 "max_dis_h":30.0,"rest_chg_min":30,"rest_dis_min":30,"rest_ir_s":300,"ir_rest_s":5,"storage_pct":50,
 "captest_ir":1,"nominal_mah":15000,"xchk_tol_v":0.060,"vin_min":4.80,"vin_max":5.40,
 "wifi_ssid":"lab","wifi_pass_set":true,"admin_pass_set":false,
 "cal_v":[1.00000,...8],"cal_i":[1.00000,...8]}
```

Write-only keys: `wifi_pass` (>= 8 characters or empty), `admin_pass`.
Response: `{"ok":true,"changed":3,"reboot_required":false,"persisted":true}`
- a reboot is required after changing `wifi_ssid`, `wifi_pass` or
`board_id`. Changes apply immediately; `persisted:false` means they are
written to flash once no job is running (flash erases can stall the CPU
longer than the 23 ms hardware watchdog window).

Safe ranges enforced by the firmware: `v_max_chg` 3.40-3.65, `v_abs_max`
3.60-3.80 (and >= v_max_chg+0.05), `v_min_dis` 2.30-3.00, `v_precharge`
2.50-3.00, `v_cc_min` 3.05-3.20, `v_dead` 1.50-2.50 (and <= v_precharge-0.2), `t_cell_max` 35-60,
`t_board_max` 50-75, `max_*_h` 1-48, `ir_rest_s` >= 5, `cal_*` 0.90-1.10,
`vin_min` 4.55-4.95, `vin_max` 5.25-5.50.

## GET /api/export.csv

`board,ch,cell,state,program,step,v,i,t_cell,cap_mah,cap_mwh,cap_s,dis_term,chg_mah,chg_mwh,chg_term,store_mah,ir_dc_mohm,ir_ohmic_mohm,ir_i_a,ir_v0,ir_mode,elapsed_s,msg`
(one row per channel, CRLF line ends). The dashboard's "Export" tab builds
the same CSV for all boards.

## POST /api/pack

```json
{"s":4,"p":10,"sel":"top","irw":0.1,"cells":[9,15012.5,8.3, 10,14890.1,9.1, ...]}
```

`cells` is a flat array of `[id, capacity_mAh, dc_ir_mOhm]` triples (IR 0 =
unknown), up to 128 cells. `sel`: `top` (highest capacities) or `tight`
(narrowest capacity window) when more cells than S*P are given; `irw` weight
of the group-resistance balancing (0..10). Response:

```json
{"ok":true,"s":4,"p":10,"cap_spread_pct":0.157,"ir_spread_pct":0.16,"pack_cap_mah":148960.2,
 "pack_ir_mohm":3.52,"swaps":5,
 "groups":[{"n":1,"cap_mah":149021.4,"ir_mohm":0.881,"cells":[[9,15012.5,8.30], ...]}, ...],
 "unused":[17,23]}
```

## POST /update

Multipart upload of `lfp8.ino.bin` (field name `fw`). Refused with 409 while
any job is running unless `?force=1`. During the update all outputs are off
and the heartbeat is stopped on purpose. On success the board restarts.

## UDP discovery (port 45454)

Every 2 s each board broadcasts (subnet broadcast of STA and/or AP interface):

```json
{"t":"hello","id":1,"ip":"192.168.1.51","fw":"1.0.0"}
```

Peers not heard for 10 s are dropped. A board that hears its own `id` from a
different IP reports `dup_id:true`.

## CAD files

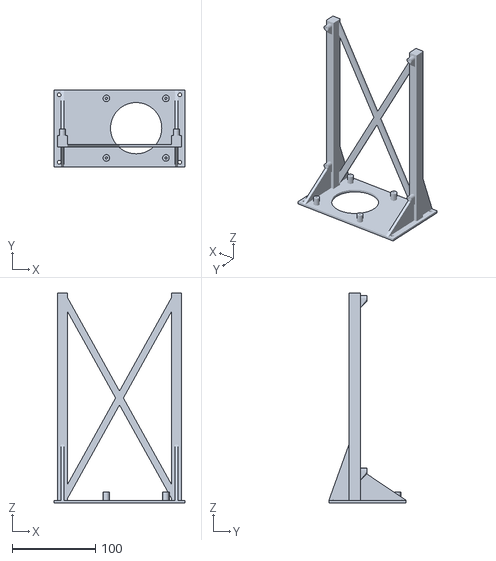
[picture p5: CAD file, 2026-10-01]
mechanical/stl/board_stand.stl
157.0 x 92.8 x 252.2

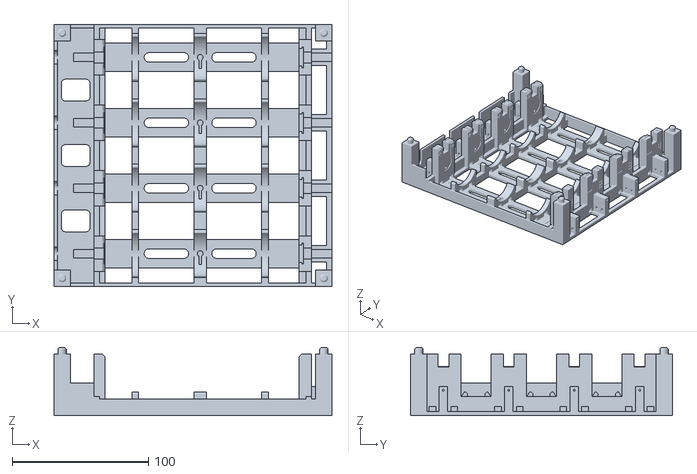
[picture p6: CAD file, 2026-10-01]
mechanical/stl/cradle_4cell_labels_1-4.stl
203.9 x 192.0 x 50.0

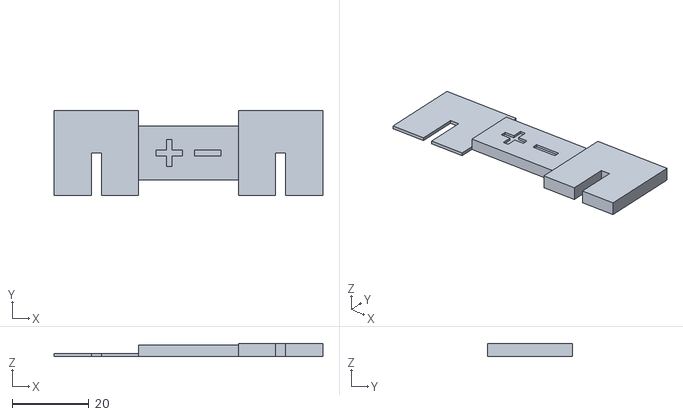
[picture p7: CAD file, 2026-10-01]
mechanical/stl/pogo_gauge.stl
70.0 x 22.0 x 3.40

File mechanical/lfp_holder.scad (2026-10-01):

// =============================================================================
//  lfp_holder.scad  -  parametric 3D-printable holder system for 40 x LiFePO4
//                      33140 cells, tested by five LFP-8 boards (8 ch each)
// -----------------------------------------------------------------------------
//  Target printer : Creality Ender 3 S1 Pro (220 x 220 x 270 mm bed); every part
//                   is kept inside 210 x 210 mm footprint and <= 260 mm height.
//  Tool           : OpenSCAD 2021.01 (no libraries, no fonts needed - all
//                   lettering is drawn as 7-segment glyphs).
//
//  PARTS (select with  -D 'part="..."'):
//    "cradle"      4-cell horizontal cradle (default). 10 are needed for 40 cells.
//                  Two cradles stack (pins/sockets) = one 8-cell module per LFP-8.
//                  -D label_offset=0 -> channels 1..4, label_offset=4 -> 5..8
//    "board_stand" vertical stand for one LFP-8 PCB (4x M3 standoffs) with a
//                  60/80 mm 5 V fan underneath blowing UP across both PCB faces.
//    "board_tray"  (accessory) flat tray that sits on top of a stacked module
//                  using the same stacking pins; PCB flat, fan blows across it.
//    "pogo_gauge"  (accessory) depth gauge to set the pogo-pin protrusion.
//    "assembly"    visual check only: 2 cradles + dummy cells + board stand.
//    "section"     visual check only: cut through one cell with plates, spring,
//                  pogo pins and NTC bead in place.
//
//  COORDINATE SYSTEM OF THE CRADLE (print orientation = use orientation):
//    X = cell axis.  x = 0 is the outer face of the wire raceway at the
//        POSITIVE ("connector") end; the NEGATIVE (spring) end is at +X.
//    Y = across the cells, cell i (0..n-1) is centred at y = (i + 0.5)*pitch.
//    Z = up, z = 0 is the print bed / table.
//    P (variable below) is the "positive contact plane" = face of the positive
//    force plate; every axial dimension of the cell is referenced to P.
//
//  KELVIN CONTACT SCHEME PER CELL
//    + end : flat 15x15 force plate (B+F) in a pocket, pogo pin (B+S) 6.0 mm
//            below the cell axis (lands on the raised + cap, clear of any M4/M5
//            thread), plate shifted 4.0 mm up so plate and pogo never touch.
//    - end : 15x15 plate with conical spring (B-F) in a captured slot, pogo pin
//            (B-S) 6.0 mm below the axis on the flat can bottom.
//    NTC   : pocket in the saddle under the middle of the cell.
//    The spring pushes every cell against the + plate, so the + end is the
//    fixed datum; cell-length tolerance is taken by the spring (and by the
//    4 mm working stroke of the - end pogo pin).
// =============================================================================

/* [Part selection] */
part = "cradle";        // [cradle, board_stand, board_tray, pogo_gauge, assembly, section]
label_offset = 0;       // 0 -> labels 1..4 ; 4 -> labels 5..8 (second cradle of a module)

/* [Printer] */
bed_x = 220;            // Ender 3 S1 Pro bed
bed_y = 220;
bed_z = 270;
bed_margin = 5;         // per side -> usable 210 x 210
z_margin = 10;          // -> usable height 260
nozzle = 0.4;
min_wall = 2.4;         // 3 perimeters x 0.4 mm x 2 (requirement)

/* [Cell (33140 LiFePO4, 15 Ah)] */
cell_d_nom = 33.0;
cell_d_max = 33.6;      // design envelope
cell_len_min = 139.5;   // overall length incl. + cap
cell_len_nom = 140.0;
cell_len_max = 141.5;
cap_d_min = 14;         // raised + cap (terminal) diameter range
cap_d_max = 16;
cap_h_min = 0.5;        // raised + cap height range 0.5..1 mm
cell_clr = 0.4;         // radial clearance: saddle radius - max cell radius (>= 0.3)
cell_mass_g = 290;

/* [Cradle layout] */
n_cells = 4;            // cells per cradle
pitch = 48;             // cell centre distance -> 14 mm finger gap between cells
base_t = 3;             // floor thickness (>= min_wall)
wire_gap = 5;           // floor top -> lowest point of the saddle (wires run here)
stack_gap = 3.4;        // max-cell top -> underside of the cradle stacked above
rib_t = 5;              // saddle rib thickness (X)
ntc_rib_t = 9;          // the middle rib carries the NTC pocket (2.4 mm walls around it)
rib_frac = [0.16, 0.5, 0.84];  // rib positions as fraction of cell_len_nom from P
ntc_rib_index = 1;
rib_drop = 8;           // rib top this far below the saddle axis (saddle wraps +-62 deg)
saddle_wing = 2.4;      // material beside the saddle at rib top
rib_link_h = 8;         // low link between saddles of a rib (leaves finger gap)
strip_w = 21;           // floor strip under each cell (wire bed)
strip_slot_w = 7;       // ventilation slot along the middle of the strip (middle bays)
rail_t = 2.4;           // side rails
rail_h = 12;
web_h = 14;             // height of the end-wall web between the contact towers
web_t = 4;              // web thickness (at the back side of each end wall)
tower_w_pogo = 26;      // contact tower width, sense_style = "pogo"
tower_w_plate = 32;     // contact tower width, sense_style = "plate"
ch_top = 2;             // 45 deg chamfer on tower top edges (cell lead-in)
ch_rib = 1.2;           // 45 deg chamfer on rib lips

/* [Force contacts] */
fp_w = 15;              // force plate width  (standard nickel-plated steel plate)
fp_h = 15;              // force plate height
fp_t = 0.4;             // nominal plate thickness (0.3..0.5)
fp_t_tol = 0.1;         // +- thickness tolerance used in the spring calculation
fp_clr = 0.2;           // side clearance of plate in pocket / slot
tab_notch_w = 8;        // notch for the solder tab (tab goes UP, bent 90 deg back)
pos_notch_drop = 0;     // + : notch floor = plate top edge -> plate hangs on its bent tab
neg_notch_drop = -0.7;  // - : plate sits on the slot floor, bent tab clears the notch floor
force_off = 4.0;        // force plate centre above cell axis (pogo style)
spring_free_min = 8;    // conical spring free height range 8..10 mm
spring_free_max = 10;
spring_solid = 3;       // fully compressed height
spring_preload_min = 2; // minimum compression for the SHORTEST cell
spring_base_d = 12;     // large diameter of the conical spring
pocket_d = 0.6;         // + plate pocket depth (plate face 0.1..0.3 behind wall face)
cap_clear_d = 17.5;     // recess around the + cap (cap 16 max + axis tolerance)
neg_skin = 2.4;         // front skin of the - slot (holds plate edges)
neg_slot_t = 0.9;       // - slot thickness (plate 0.3..0.5 + clearance)
neg_window_w = 13;      // window in the skin for the spring
pos_wall_t = 8;         // + end wall (contact tower) thickness
neg_back_t = 6;         // - end wall material behind the slot

/* [Sense contacts] */
sense_style = "pogo";   // [pogo, plate]
sense_off = 6.0;        // pogo centre below the cell axis (lands on + cap / - can)
pogo_hole_d = 1.40;     // press fit for P100 barrel 1.36 (drill/ream 1.40 after print;
                        //  1.70 for R100 receptacles)
pogo_guide_d = 1.40;    // bore in the support fin (same drill as the wall: ream both in one pass)
pogo_head_clear_d = 2.2;// clearance for the 1.5 mm plunger head
pogo_len = 33.35;       // P100 overall length (plunger free)
pogo_ext = 6.85;        // plunger tip beyond barrel front, free (P100: full stroke 6.2..6.5)
pogo_work = 4.0;        // recommended working travel of P100
pogo_full = 6.2;        // full travel
pos_pogo_preload = 1.0; // + pogo tip stands this far in front of the + plate face
neg_pogo_preload = 0.5; // - pogo compression for the SHORTEST cell
sp_w = 10;              // sense plate (sense_style = "plate")
sp_h = 10;
sp_gap = 1.6;           // plastic / air gap between force and sense plate
sp_spring_base_d = 7;   // small spring on the - sense plate
sp_notch_w = 5;
sp_window_w = 8;

/* [Wire management] */
race_w_min = 20;        // raceway inner width; with pogo pins it grows so that the
tail_clear = 2.5;       //  pogo tail ends tail_clear before the outer lip (solder room)
race_lip_t = 2.4;
race_lip_h = 24;
exit_w = 10;            // U-notch where each cell's 6-wire bundle leaves
exit_floor = 8;
fin_t = 6.2;            // pogo support fin (2.4 mm walls around the bore)
fin_len = 15;
fin_above = 2.6;        // fin top above pogo axis
tie_w = 2.0;            // zip-tie slot through the fins (for 2.5 mm ties)
tie_h = 3.2;
tunnel_w = 5;           // wire tunnels / rib notches (bridge <= 10 mm)
tunnel_h = 3.5;
wire_notch_off = 8;     // tunnels at cell centre +- this (2.4 mm under the saddle)
ntc_d = 4.2;            // NTC bead pocket (bead <= 3 mm + epoxy)
ntc_depth = 5.5;        // pocket depth below saddle bottom (bead + 3 mm foam)
ntc_lead_w = 1.6;

/* [Stacking] */
post = 12;              // corner post size
pin_d = 6;
pin_h = 5;
stack_clr = 0.2;        // radial clearance pin/socket

/* [Labels] */
label_depth = 0.6;      // deboss depth
lip_digit_h = 10;
top_digit_h = 8;
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

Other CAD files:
mechanical/stl/cradle_4cell_labels_5-8.stl

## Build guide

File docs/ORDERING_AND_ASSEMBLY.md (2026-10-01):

# Ordering, assembly and bring-up

## 1. Order the boards (JLCPCB)

Files are in `hardware/fab/` (regenerate with `make -C hardware fab`).

1. Upload **`lfp8_gerbers.zip`** at jlcpcb.com → *Order now*.
   * Layers 2, thickness 1.6 mm, 1 oz copper, HASL lead-free (cheapest) or ENIG,
     any solder-mask colour (green is cheapest and fastest).
   * Quantity **5**: one board per 8 cells, so 5 boards give 40 cells. This is
     also JLCPCB's minimum.
   * "Remove order number": *Specify a location* is not needed; choose
     *No* or accept the default.
2. Enable **PCB Assembly**, *Economic*, *Top side*, quantity 5 (or 2 to test
   first, then order the rest).
3. Upload **`lfp8_bom_jlcpcb.csv`** (BOM) and **`lfp8_cpl_jlcpcb.csv`**
   (pick-and-place).
4. In the parts list, check that every line matched the LCSC number given.
   * **U6 ESP32-C3-WROOM-02-N4 (C2934560)** could not be verified offline when
     this design was made. If JLCPCB shows it out of stock, pick another
     ESP32-C3-WROOM-02 4 MB variant (same footprint), or leave U6 unplaced and
     solder a module by hand.
   * Extended parts cost a one-time $3 loading fee each. There are 6 extended
     types: U6, U7 (ADS1115), R_x50 (0.1 Ω shunt), R_x06 (1.2 Ω), R_x24–27
     (11 Ω) and F_x01 (PTC). Everything else is basic or preferred, which has no
     loading fee.
5. **Check the placement preview carefully** (JLCPCB's DFM / 3D view). Rotation
   offsets for SOT-23, SOT-223, SOIC and TSSOP have already been applied in
   the CPL. Still confirm the pin-1 / cathode marks of:
   * SS34 / SS54 / SS14 diodes, BAT54WS, LEDs and SMBJ6.0A (cathode bar)
   * SOT-23 FETs and transistors (pin 3 alone on one side)
   * LM324 / LM358 / LM393 / 74HC595 / CD4051 / ADS1115 (pin-1 dot)
   * ESP32 module (antenna towards the board edge)
   If any part is rotated wrongly, fix it in the JLCPCB web editor (it lets you
   rotate parts), or correct `ROT_DB` in `hardware/gen/make_fab.py` and
   regenerate.

### Cost estimate (October 2026, before shipping and tax)

Researched and cross-checked against JLCPCB's fee pages, 2026 checkout records
and the JLC part database. No live quote was possible from the build machine,
so upload the files for an exact figure.

| Order | PCB fab | Fixed PCBA fees¹ | Joints² | X-ray³ | Parts | **Total** | **Per board** |
|---|---|---|---|---|---|---|---|
| 5 PCBs, 2 assembled (JLC minimum) | ≈ $26 | $29 | $6 | $3 | ≈ $44 | ≈ $108 | **≈ $54** |
| 5 PCBs, 5 assembled (one 40-cell set) | ≈ $26 | $29 | $16 | $8 | ≈ $100 | ≈ $180 | **≈ $36** |
| 10 PCBs, 10 assembled | ≈ $46 | $29 | $32 | $16 | ≈ $185 | ≈ $308 | **≈ $31** |

1. Economic PCBA, once per order:
   * setup $8.18
   * stencil $1.53
   * nitrogen reflow ≈ $0.90
   * $3.07 loading fee for each of the 6 extended part types: ESP32-C3 module,
     ADS1115, 0.1 Ω shunt, 1.2 Ω and 11 Ω 2512 resistors, PTC. The other 60
     BOM lines are basic or preferred parts and pay no loading fee.
2. 2016 SMT joints per board × $0.0016.
3. $1.64 per board if JLCPCB X-rays the ESP32 module's ground pad.

* Uncertainty is about ±15 %. The bare-PCB price ($20–34 for 5) and the
  basic-part prices are the soft spots. A $9 monthly SMT coupon may apply.
* Hand-soldered connectors (§2) add about $0.5–1 per board at LCSC minimum
  quantities.
* The board must stay on **Economic** PCBA:
  * 216 × 146 mm fits its 480 × 320 mm limit.
  * It is under the 650 cm² large-size fee threshold.
  * Standard PCBA would add ≈ $107 per order: feeder fees on all 66 BOM lines,
    higher setup and stencil fees.
* JLCPCB adds 5 mm edge rails automatically, because the ESP32 antenna sits at
  the edge (about +$1–3).
* Economic PCBA quantities are probably 2, 5, 10…, so check whether 3 or 4
  assembled boards can be selected.
* Shipping, tariffs and taxes depend on the destination. Example: to the US
  with DHL DDP (≈ $50–75), JLCPCB's pre-collected tariff (≈ 35 %) and state
  sales tax, the landed cost is ≈ $64–68 per board for the 5-board order.

## 2. Hand-soldered parts (per board)

`lfp8_hand_solder.csv` lists them:

| Ref | Part | Qty | Notes |
|---|---|---|---|
| J101…J801 | JST-XH B6B-XH-A, 6-pin vertical, 2.5 mm | 8 | Cell harness: 1 B+F, 2 B+S, 3 B−S, 4 B−F, 5 NTC, 6 GND |
| J1 | 2-pin 5.08 mm screw terminal (≥ 10 A, e.g. KF301-5.0-2P) | 1 | **+5 V input**. Use ≥ 1.5 mm² (16 AWG) wire, keep it short |
| J2 | 2-pin 2.54 mm header | 1 | 5 V fan (+ on pin 1) |
| J3 | 6-pin 2.54 mm header | 1 | USB: VBUS, D−, D+, GND, EN, BOOT (programming) |
| J4 | 6-pin 2.54 mm header | 1 | +5V, GND, AUX_OUT, SDA, SCL, +3V3 (expansion) |

## 3. Wiring the cells

Each channel connector carries **separate force and sense wires** at both cell
terminals. The holder in `mechanical/` provides a force plate plus a sense pogo
pin at each end:

```
JST pin 1  B+F  ─── + force plate     (≥ 0.5 mm² / 20 AWG, ≤ 30 cm)
JST pin 2  B+S  ─── + sense pogo      (any thin wire)
JST pin 3  B−S  ─── − sense pogo
JST pin 4  B−F  ─── − spring plate    (≥ 0.5 mm² / 20 AWG, ≤ 30 cm)
JST pin 5  NTC  ─── 10 k NTC (B 3950) on the cell body, other leg to pin 6
JST pin 6  GND
```

Do **not** join B+F and B+S (or B−F and B−S) at the connector. The
point of 4-wire sensing is that they meet only at the cell terminal.

## 4. Power supply

* 5.20 V (5.00–5.25 V) regulated, **≥ 10 A per board**, current-limited or
  fused. Five boards can share one 5 V / 50–60 A supply; run a separate pair of
  wires to each board.
* Adjust the PSU to 5.20 V **measured at J1 under load**. The web UI shows the
  rail voltage (`V_IN`).
* The board protects itself against reversed polarity with a crowbar diode
  (SS54) that shorts the input. Only a current-limited or fused supply survives
  that.

## 5. Bring-up checklist (per board)

1. Before connecting cells: power from a bench supply at 5.2 V with a 1 A limit.
   Idle current should be ≈ 80–120 mA. The red power LED (D10) is on and the
   green SAFE LED (D9) is off: SAFE_EN stays low until firmware runs the
   heartbeat.
2. Flash the firmware through J3 (USB D+/D− of the ESP32-C3), see
   `firmware/README.md`. After boot D9 turns on (SAFE_EN high).
3. Press E-STOP (SW1): D9 must go off and the web UI must show `ESTOP`.
4. Connect one cell. The UI shows its voltage within ±5 mV of a DMM measured
   at the cell terminals.
5. Start a charge at ISET 4. Current settles at ≈ 1.0 A. Raise the PSU current
   limit to 10 A before using all 8 channels.
6. Start a discharge. ≈ 1.07 A at 3.29 V, and the fan starts.
7. Run an IR measurement on a known cell and compare with a 4-wire IR meter.

## 6. Printing the holder

See `mechanical/README.md`. In short: 10 × cradle (5 of each label variant),
5 × board stand, PETG, 0.2 mm layers, no supports, all within the Ender 3 S1 Pro
volume.

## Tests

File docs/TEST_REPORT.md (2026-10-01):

# LFP-8 test report

Everything here is reproducible with `./run_all_tests.sh`. Raw numbers:
`sim/results/summary.json` (ngspice), `hardware/fab/check_report.json`
(PCB) and `hardware/fab/drc_report.txt` (KiCad DRC).

| Suite | Tests | Result |
|---|---|---|
| ngspice: functional + adversarial + Monte Carlo + stability (`sim/tests`) | 32 | **all pass** |
| Schematic netlist == DSL netlist (`verify_netlist.py`) | 835 parts, 431 nets | **pass** |
| PCB: DRC, PCB netlist == DSL, current capacity, BOM (`check_pcb.py`) | see §4 | see §4 |
| Firmware host tests (`make -C firmware test`) | 78 tests, 2230 checks + simulated 8-cell capacity run | **all pass** |
| Firmware ESP32-C3 build (arduino-cli, esp32 core 3.3.12) | flash 63 %, RAM 50 % | **pass** |
| Holder printability (`mechanical/check_printability.py`) | mesh + fit checks | **pass** |

## 1. Simulation setup

* ngspice 42 transient and AC analysis of the **exact** circuit that goes to
  the PCB: the netlist is generated from `hardware/gen/lfp8_circuit.py`.
* Models (`sim/models/lfp8_models.lib`):
  * LM324 / LM358: tanh input stage, GBW 1.2 MHz, Aol 100 dB, slew rate 0.5 V/µs,
    output high VCC − 1.5 V, input offset as a parameter
  * LM393: open-collector output
  * CJ431: shunt reference with VREF0 as a parameter
  * FETs: VDMOS AO3400A / AO3401A / 2N7002 / BSS138 with body diodes and
    capacitances
  * BJTs, Schottky diodes, TVS, LEDs
  * PTC: electro-thermal model, I_hold 2 A
  * LFP cell: OCV(SoC) table, R0 8 mΩ, two RC polarisation branches
    (4 mΩ / 0.5 s and 5 mΩ / 60 s); capacity is scaled down in the
    time-compressed tests
* Monte Carlo, 100 runs:
  * resistors ±1 %
  * CJ431 VREF ±0.5 %
  * LM324 offset: normal, σ 2.3 mV, truncated at ±7 mV

## 2. Functional results

| Test | Result | Pass criterion |
|---|---|---|
| CC→CV charge cycle (90 % → full) | I_CC 0.970 A, V_max 3.593 V, ends at 3.582 V / 0 A | CV ≤ 3.62 V, no overshoot past the OV latch |
| ISET DAC codes 0–7 at 3.30 V cell | 0 / 0.260 / 0.517 / 0.772 / 1.003 / 1.003 / 1.003 / 1.003 A | monotonic, code 0 blocks |
| Discharge current at 3.29 V | 1.075 A (R_eff 3.06 Ω incl. FET + shunt + wiring) | 1.0–1.15 A |
| IR measurement (Kelvin), cell R_ohmic 8.08 mΩ / R_dc 11.54 mΩ | 8.13 mΩ / 11.60 mΩ (+0.6 %) | ±3 %; a 2-wire reading would show 131 mΩ |
| Empty slot | reads 0.033 V, charger open-circuit V 3.572 V, no oscillation | firmware detects `EMPTY` |
| CC loop stability (Middlebrook, 23 corners: SoC, rail 4.75–5.25 V, cell R, ISET) | worst phase margin 90.3°, f_c 26 Hz – 1.3 kHz | PM ≥ 45° |
| CV loop stability (7 corners) | worst phase margin 94.0° | PM ≥ 45° |

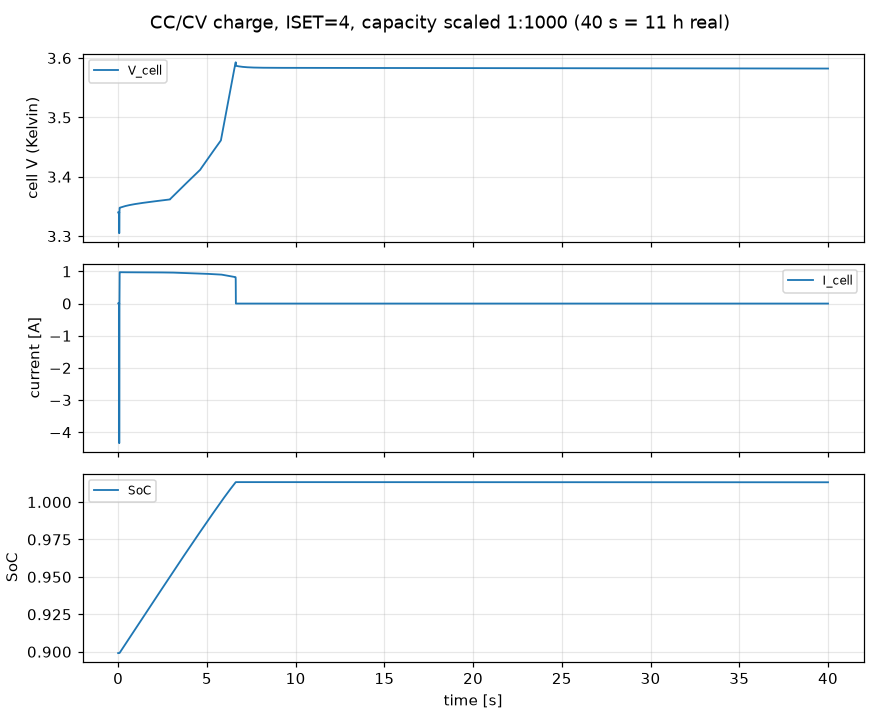
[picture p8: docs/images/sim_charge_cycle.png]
charge

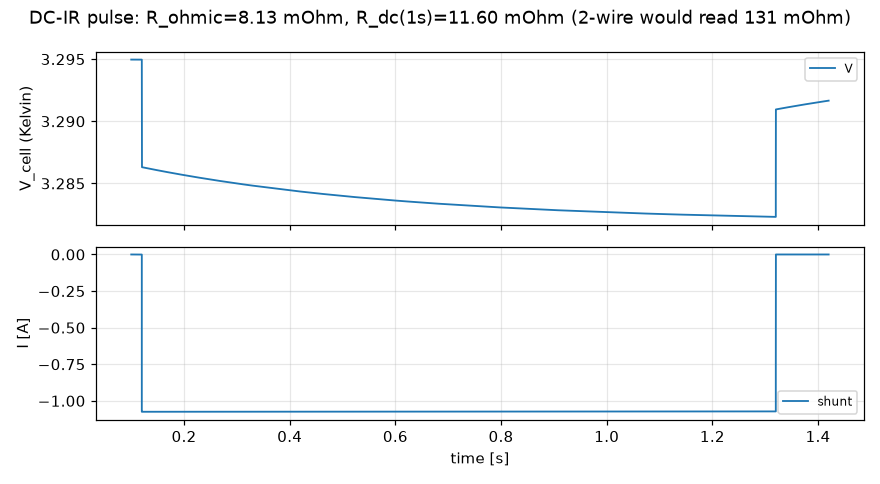
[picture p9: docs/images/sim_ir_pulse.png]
IR

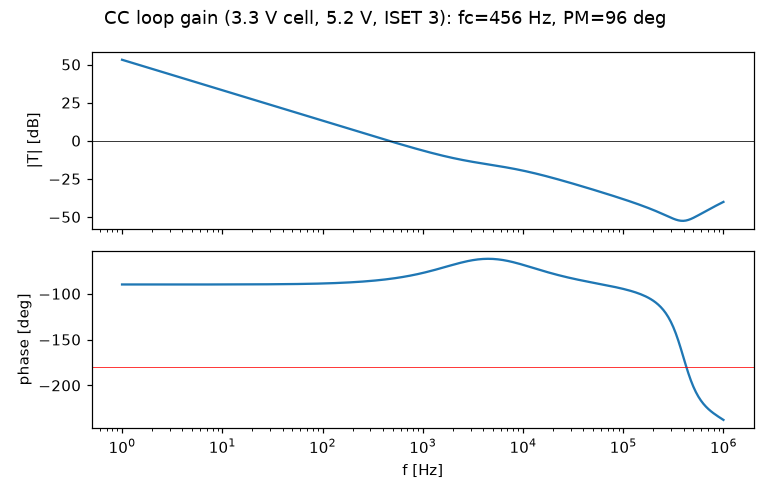
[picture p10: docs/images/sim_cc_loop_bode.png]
bode


## 3. Adversarial / fault-injection results

| Attack / fault | Result | Criterion |
|---|---|---|
| Firmware forgets to stop the discharge | hardware cuts off at **2.218 V** under load, no restart (rest 2.219 V) | ≥ 2.0 V, latched off |
| Discharge request on a 2.50 V cell | refused (0.1 mA) | < 1 mA |
| CHG_EN and DIS_EN both high | charge path 0.00002 A (was 0.987 A), discharge continues | charger forced off |
| Reversed cell while idle / charging / discharging | 0.1 mA steady, isolation FET gate 0.03–0.04 V, min IC input −0.46 V | < 1 mA, no IC input below −0.5 V |
| Reversed cell hot-plugged into a charging channel | 28 A peak for **52 µs** (0.05 mC), then 0.06 mA | < 100 µs, latched off |
| Unpowered board, cell inserted | 81 µA drain (58 mAh/month) | < 200 µA |
| Brown-out while charging (rail ramps down) | SAFE_EN drops at **4.48 V**, max reverse current 0.08 mA | no back-feed |
| Heartbeat stops (stuck low / stuck high) | SAFE_EN falls after **22.9 / 32.8 ms**, all outputs off | < 50 ms |
| Heartbeat frequency 20 / 50 / 100 / 200 / 1000 Hz | trips / trips / ok / ok / ok | ≤ 50 Hz must trip |
| Rail over-voltage 6 V | SAFE_EN 0.07 V, cell current 0.1 mA; recovers after | isolate |
| Board over-temperature 25 / 70 / 95 °C | ok / ok / **tripped** | trip between 70 and 95 °C |
| E-STOP pressed while charging | cell isolated in **126 µs** | < 1 ms |
| Pass FET shorted (D–S) during charge | OV latch at **3.824 V**, cell isolated (16 µA) | ≤ 3.9 V, isolated |
| B+ sense wire open / B− sense wire open | V_cell max 3.583 / 3.578 V | no over-charge |
| Board-side short across a channel | 12 A peak, PTC trips in **0.22 s**, 0.16 A after | PTC protects |
| Cell hot-plugged into a charging channel | 1.41 A inrush, settles 1.007 A, no false OV latch | < 2 A |
| Cell removed while charging | BP rises to 5.11 V max, OV latch released | no damage, recovers |
| Shift-register outputs high-Z (SAFE_EN low) | cell current 0.17 mA | everything off |
| Monte Carlo (100 runs) | CV 3.509–3.623 V (σ 26.7 mV), OV 3.778–3.872 V, min OV−CV margin **155 mV** | CV ≤ 3.65 V, margin ≥ 100 mV |
| Thermal budget | Q1 ≤ 0.38 W (continuous above 3.05 V; pulsed below), 1.2 Ω 1.27 W, each 11 Ω 1.01 W, board 32.9 W discharging | SOT-23 ≤ 0.4 W, 2512 ≤ 2 W |

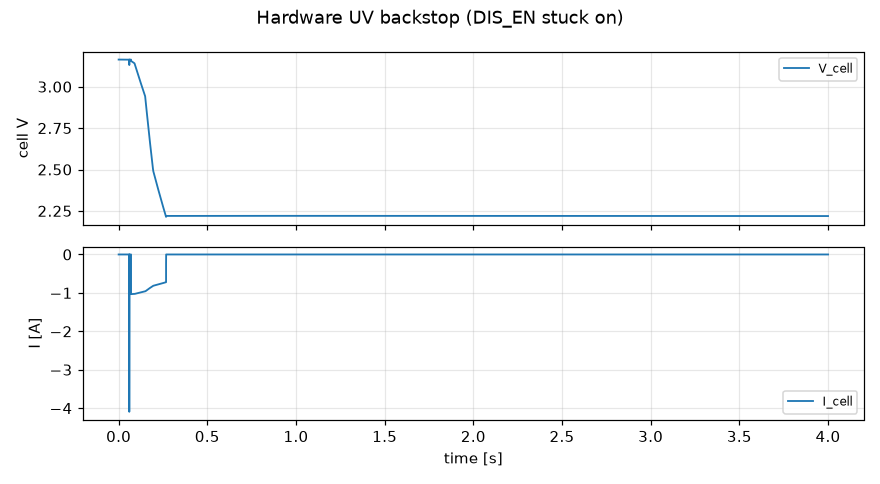
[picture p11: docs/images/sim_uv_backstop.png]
uv

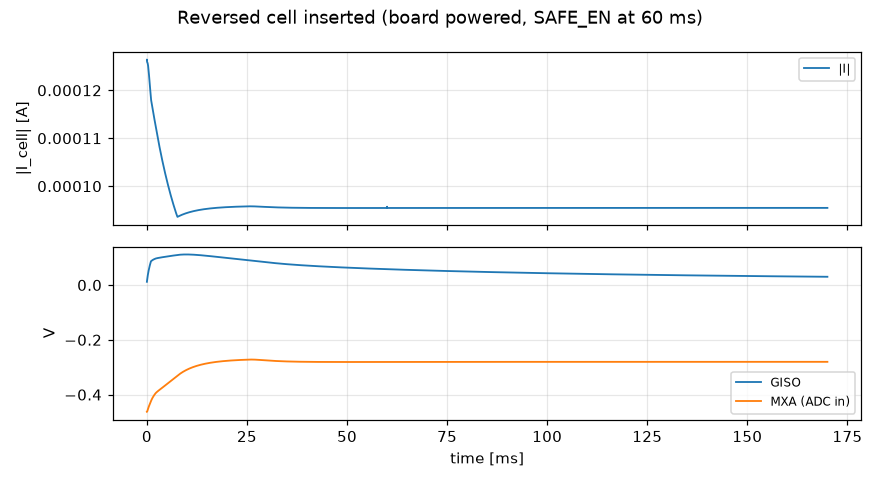
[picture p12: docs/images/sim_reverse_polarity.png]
reverse

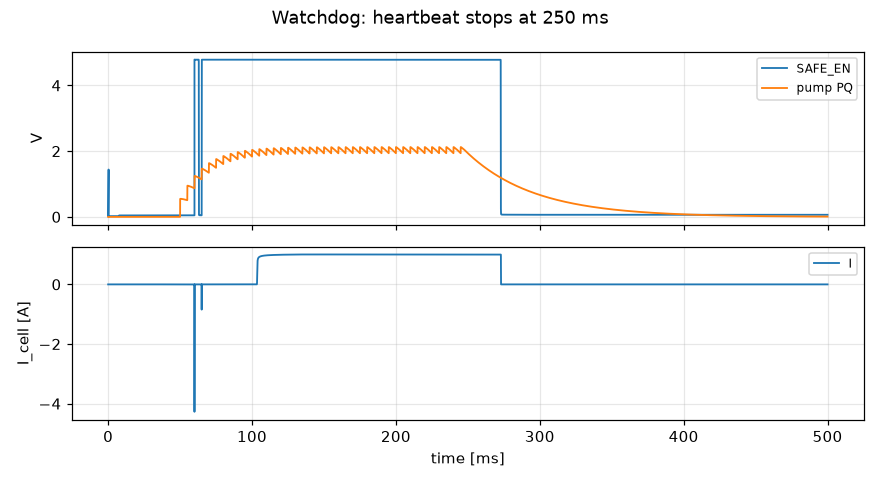
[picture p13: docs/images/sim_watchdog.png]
watchdog

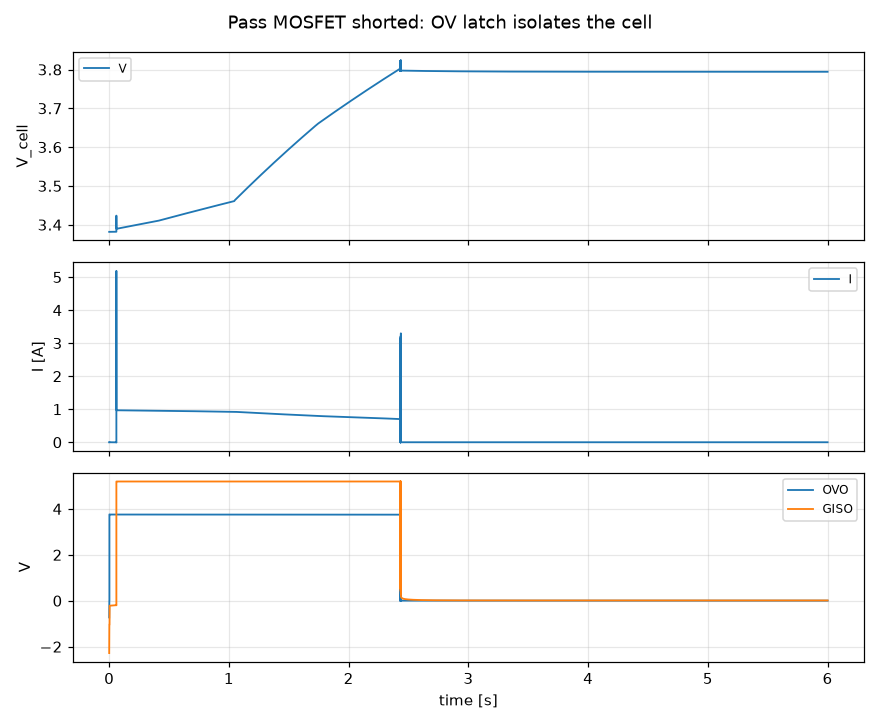
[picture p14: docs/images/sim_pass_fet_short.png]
fet short

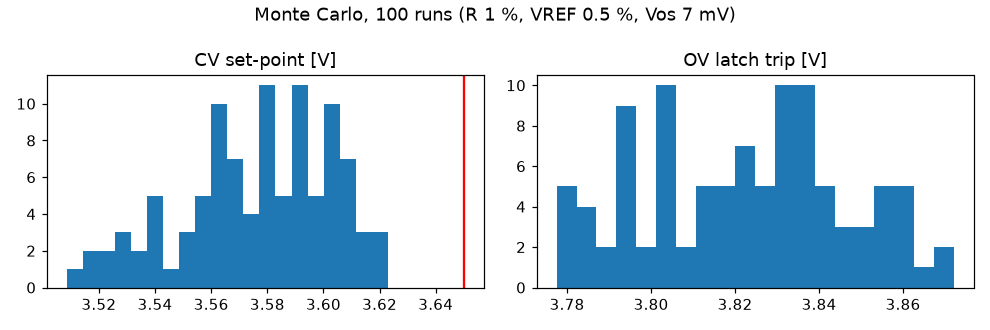
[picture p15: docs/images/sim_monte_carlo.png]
monte carlo

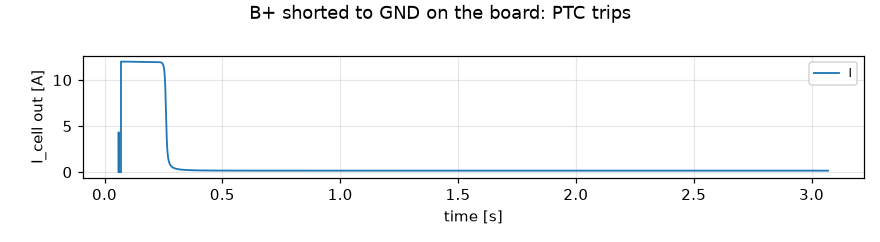
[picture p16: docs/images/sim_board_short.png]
board short

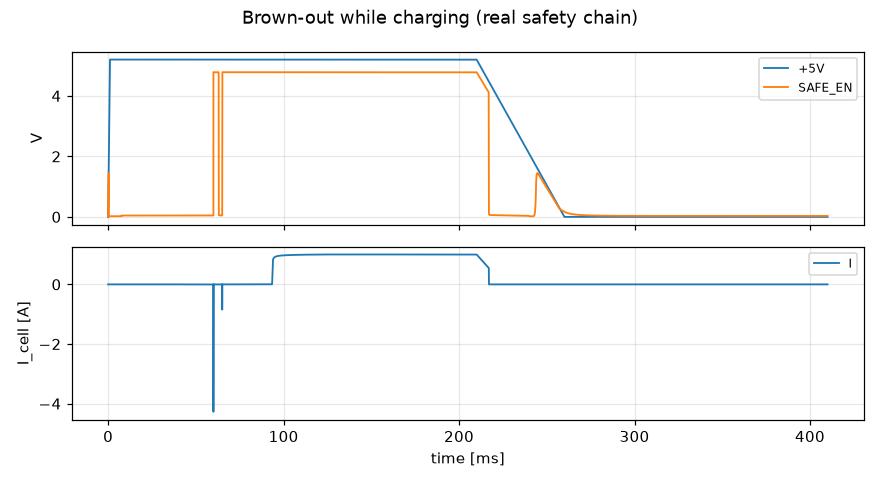
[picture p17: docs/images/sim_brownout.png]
brownout


Design bugs these tests found and fixed during development:
* integrator wind-up (fixed by soft start through anti-windup diodes)
* single-ended CV sense (made differential/Kelvin)
* OV latch tripping at power-up
* CC loop instability caused by an unbalanced differential integrator
* pass-FET over-temperature on deeply discharged cells (now a pulse policy
  enforced by firmware)
* reverse current through the isolation FET body diode
* isolation gate referenced to GND instead of the common source
* empty slot detected as a reversed cell
* sentinel unable to act while B+ is negative (added a complementary transistor)
* excessive unpowered drain (dividers scaled ×10)
* watchdog accepting a 20 Hz heartbeat

## 4. PCB checks

PCB_RESULTS_PLACEHOLDER

## 5. Firmware

`make -C firmware test` builds the portable controller core on the host and
runs 78 unit tests (2230 checks). They cover:
* the charge, discharge, capacity and IR state machines
* the thermal pulse policy
* the OV-latch reset sequence
* the shift-register bit map and interlock
* mux settling and the VCHK cross-check
* empty and reversed slots
* the JSON API
* the watchdog timing
* IR bursts: 8 simultaneous IR tests, and 3 IR tests while 5 channels discharge,
  finish without starving the scanner. This is a regression test for a bug found
  in review: queued IR pulses used to run back to back and fault the other
  channels with `FAULT_ADC`. The scanner now runs at most one IR pulse per
  full sweep.

A simulated 8-cell capacity test (`sim_cell_test`) checks the controller
against cell models with hardware CV spread 3.51–3.62 V:
* reported capacity within 0.24 % of the model
* IR within 0.15 mΩ
* never more than 1 s of continuous charge below 3.0 V

Hardware-in-the-loop testing has **not** been done: no boards exist yet.
Follow the bring-up checklist in
[ORDERING_AND_ASSEMBLY.md](ORDERING_AND_ASSEMBLY.md).

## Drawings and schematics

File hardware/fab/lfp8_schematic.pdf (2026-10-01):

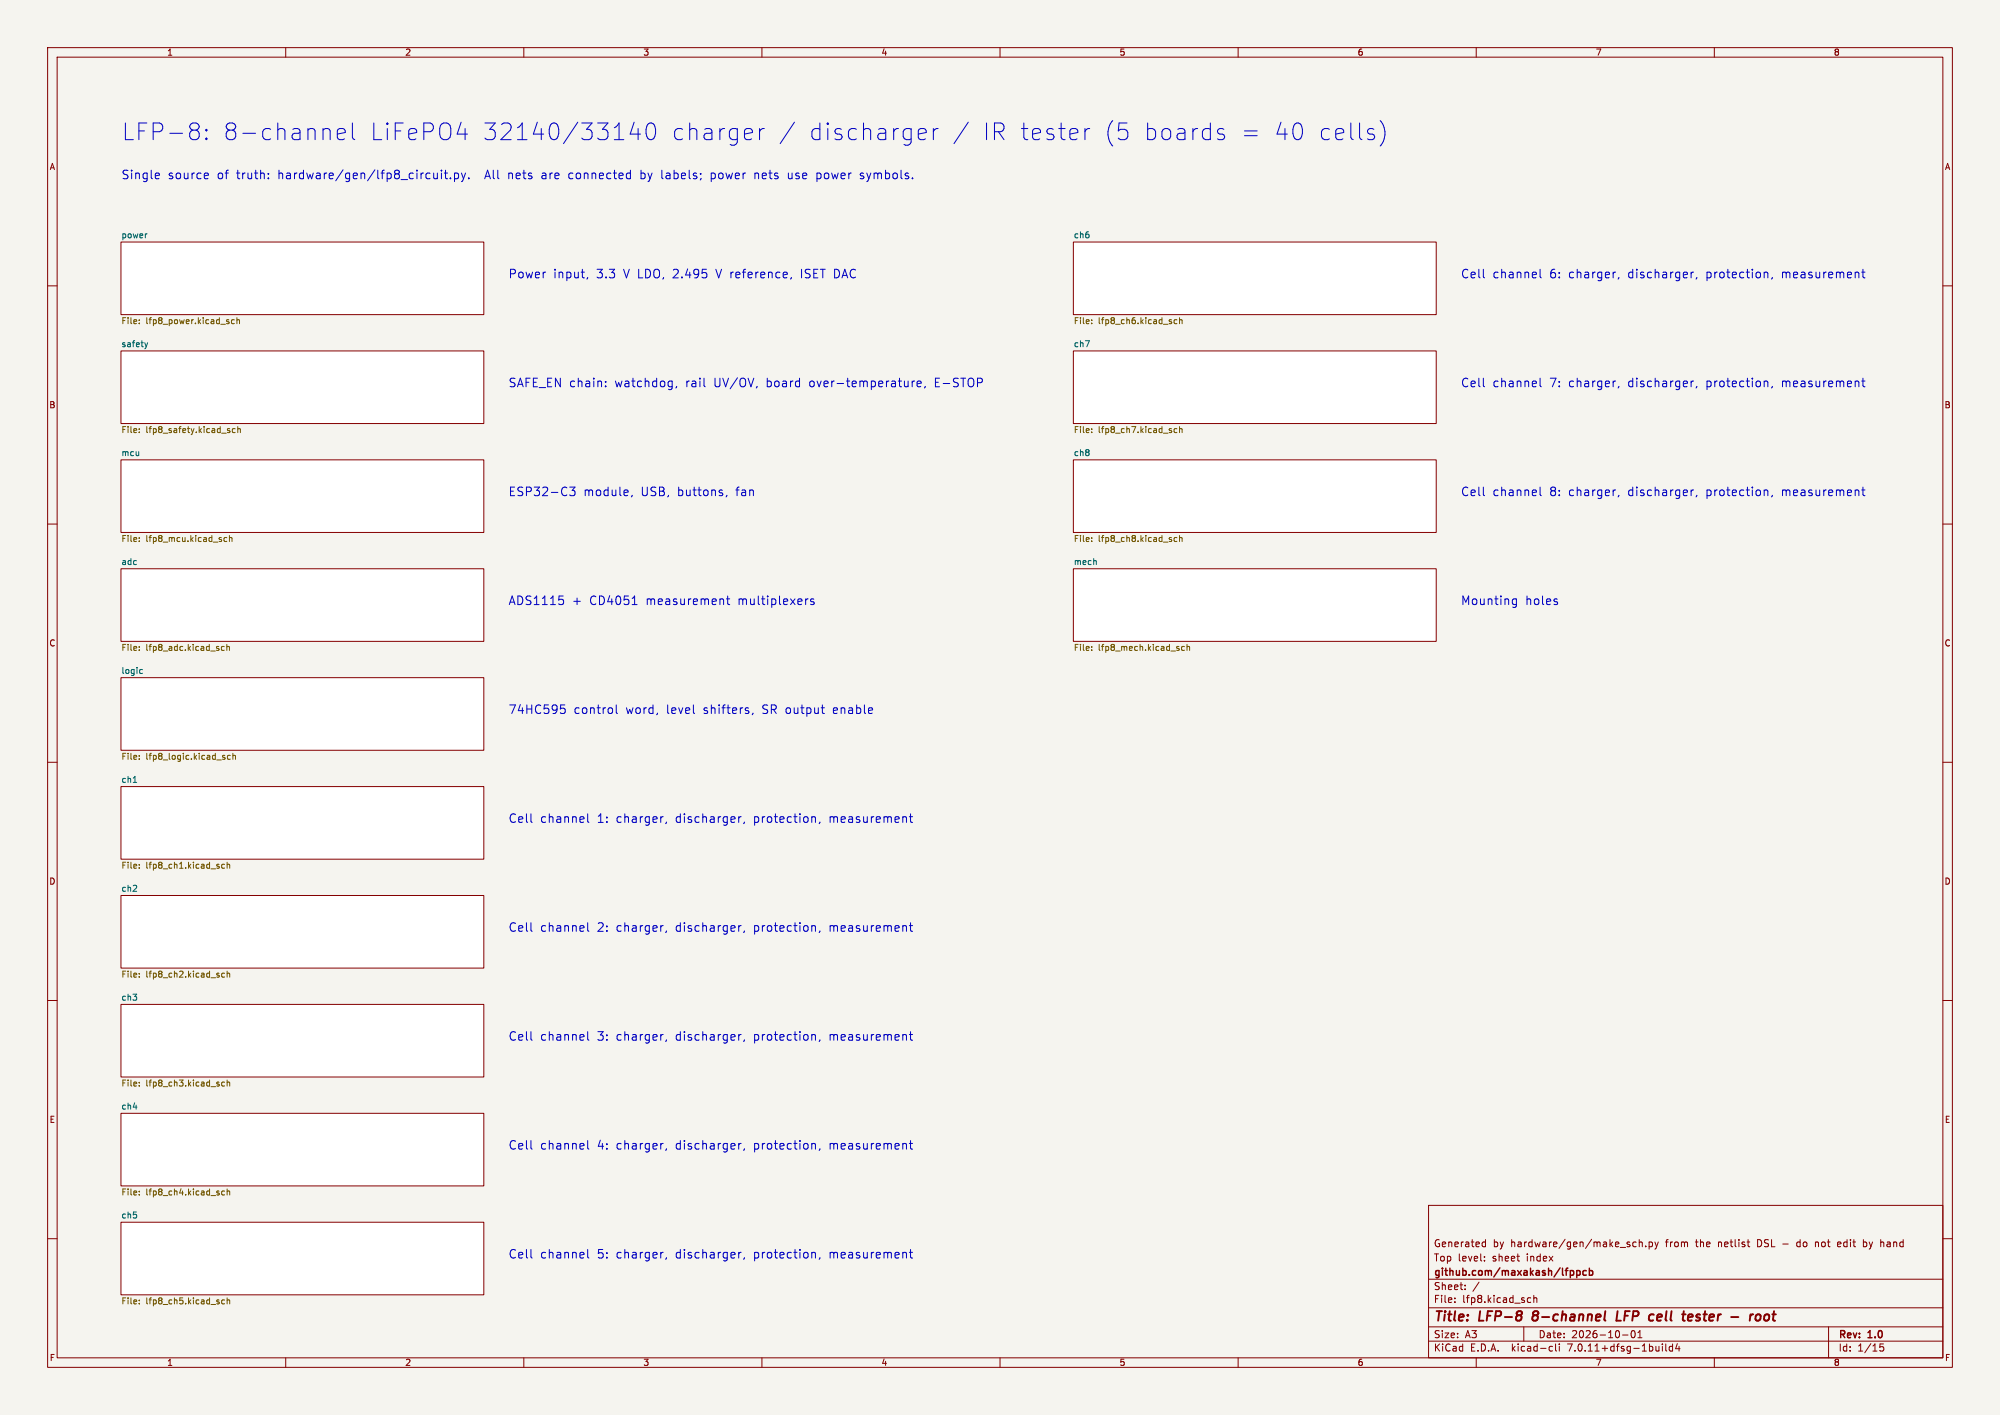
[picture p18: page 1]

safety File: lfp8_safety.kicad_sch
adc File: lfp8_adc.kicad_sch mcu File: lfp8_mcu.kicad_sch

Top level: sheet index Generated | | by | hardware/gen/make_sch.py | from the netlist | DSL - | do not edit | by | hand

8-channel LFP cell tester - root File: lfp8.kicad_sch Sheet: / github.com/maxakash/lfppcb Id: 1/15 Title: LFP-8

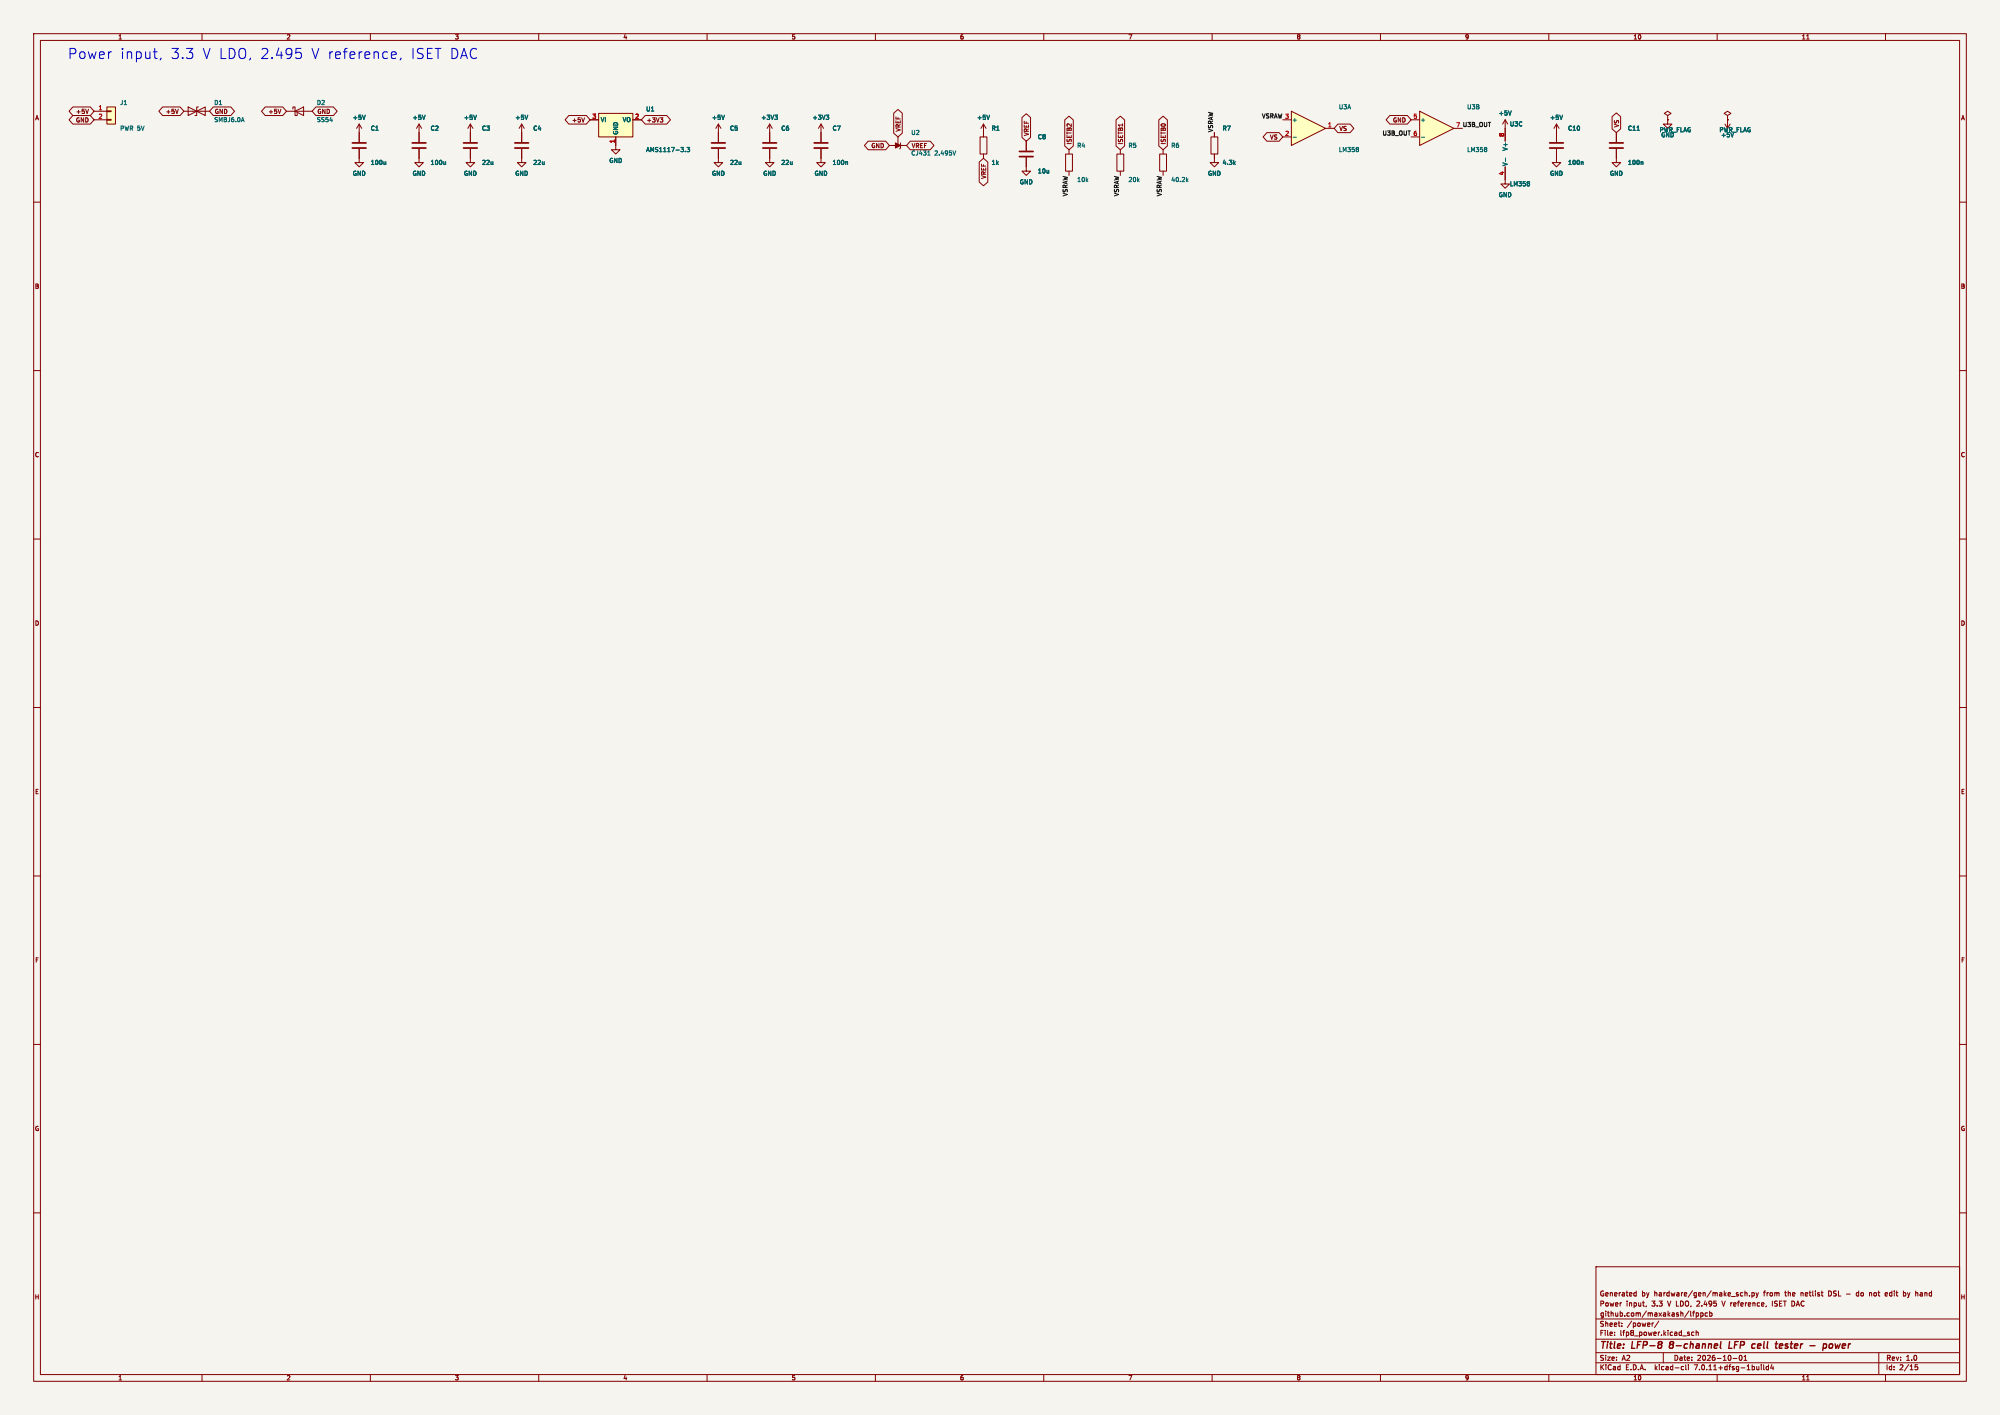
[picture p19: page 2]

VSRAW Power input, 3.3 V LDO, 2.495 V reference, ISET DAC

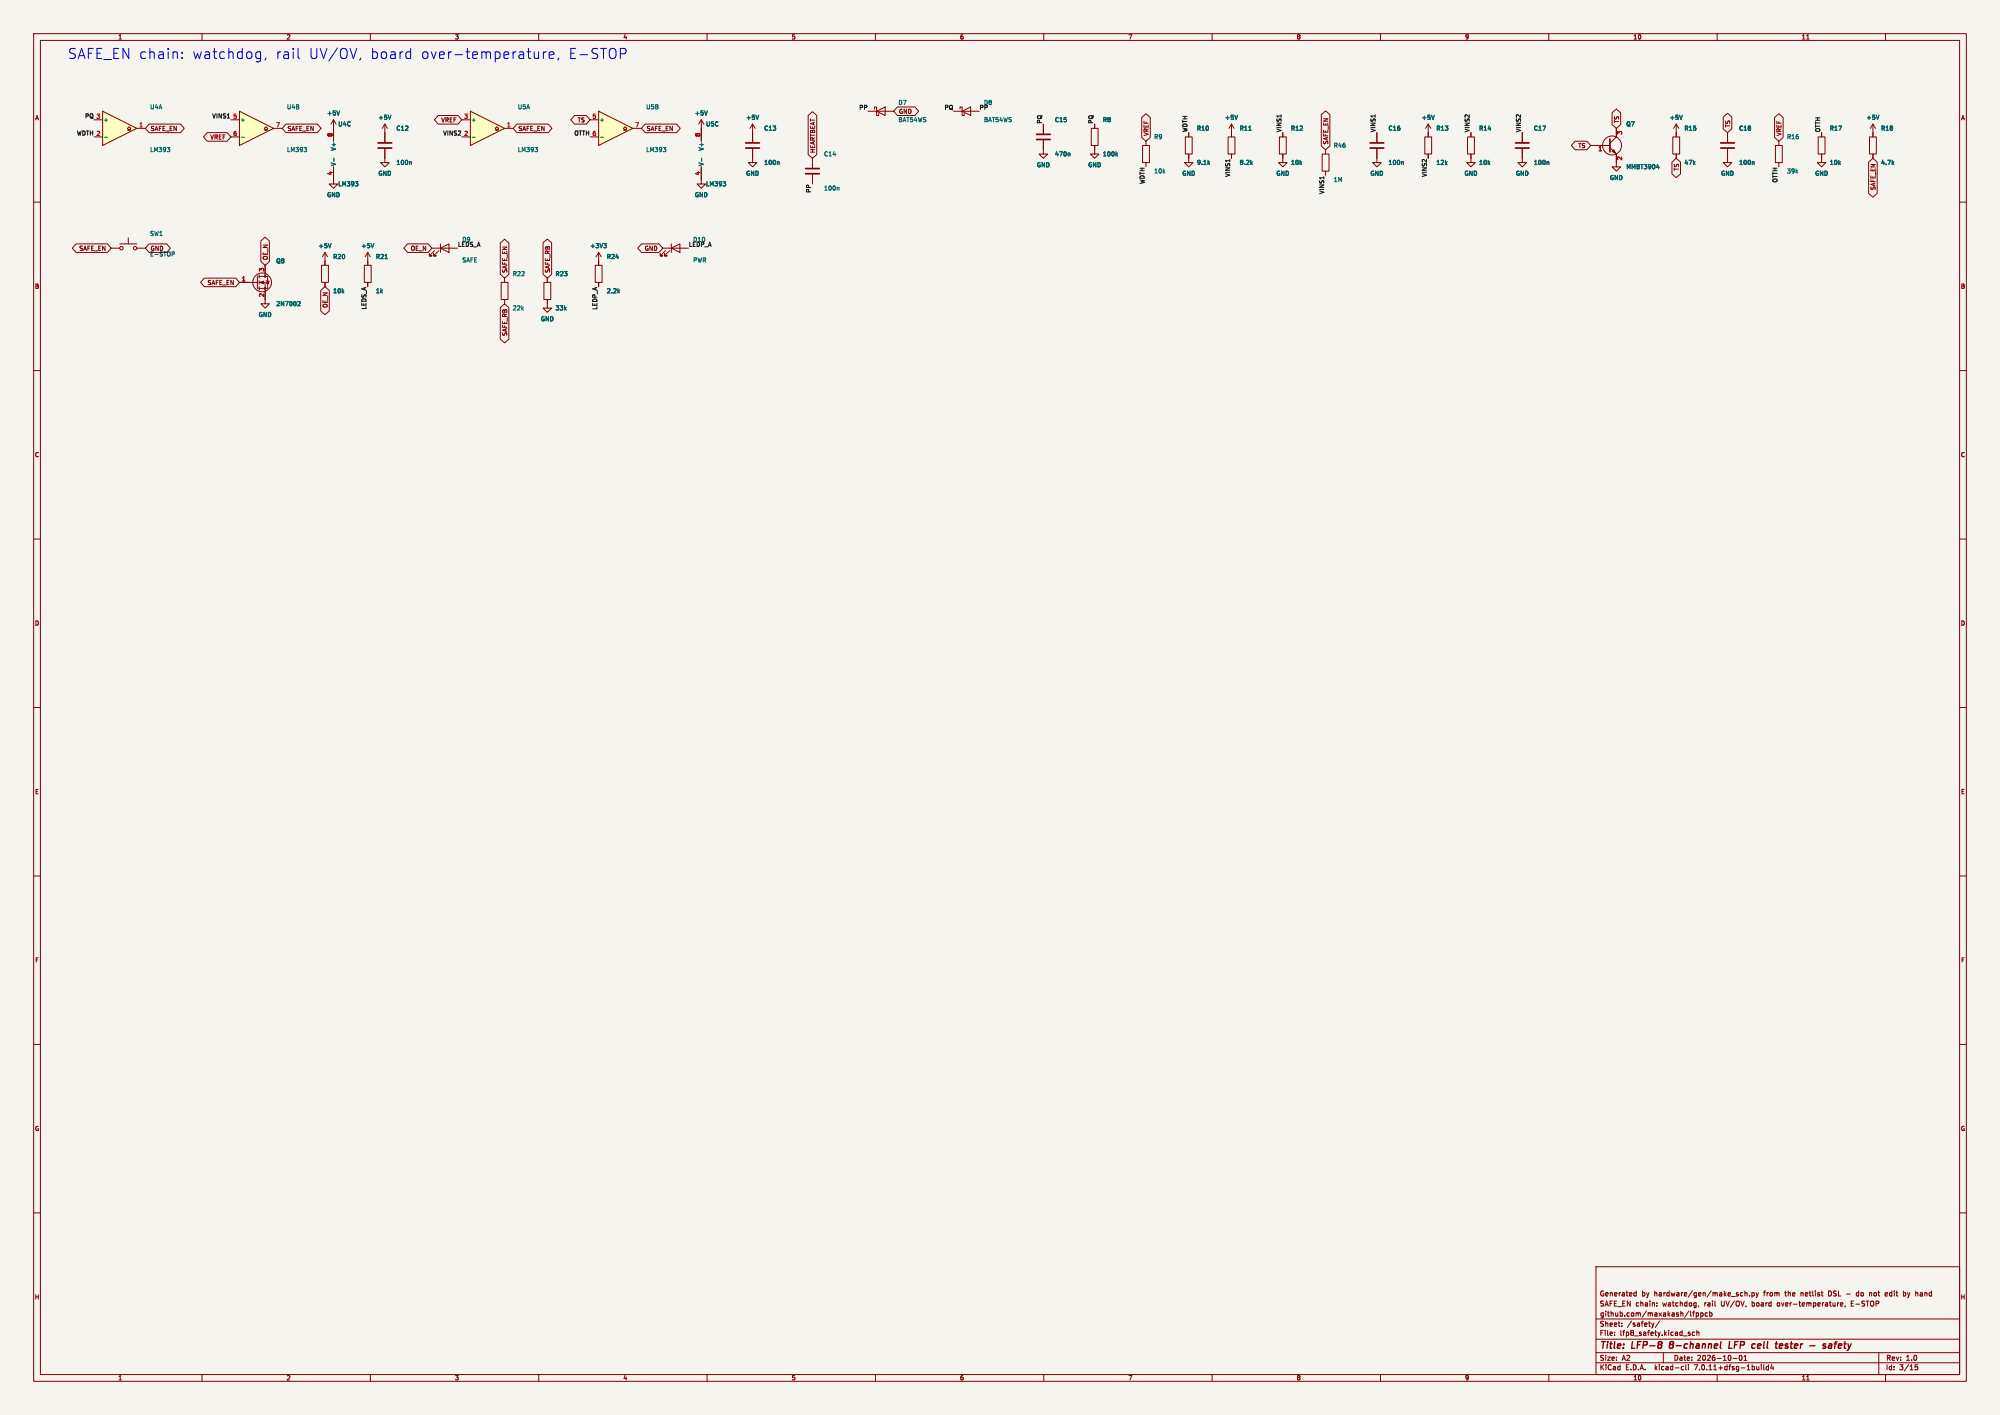
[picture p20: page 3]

github.com/maxakash/lfppcb
File: lfp8_safety.kicad_sch Sheet: /safety/

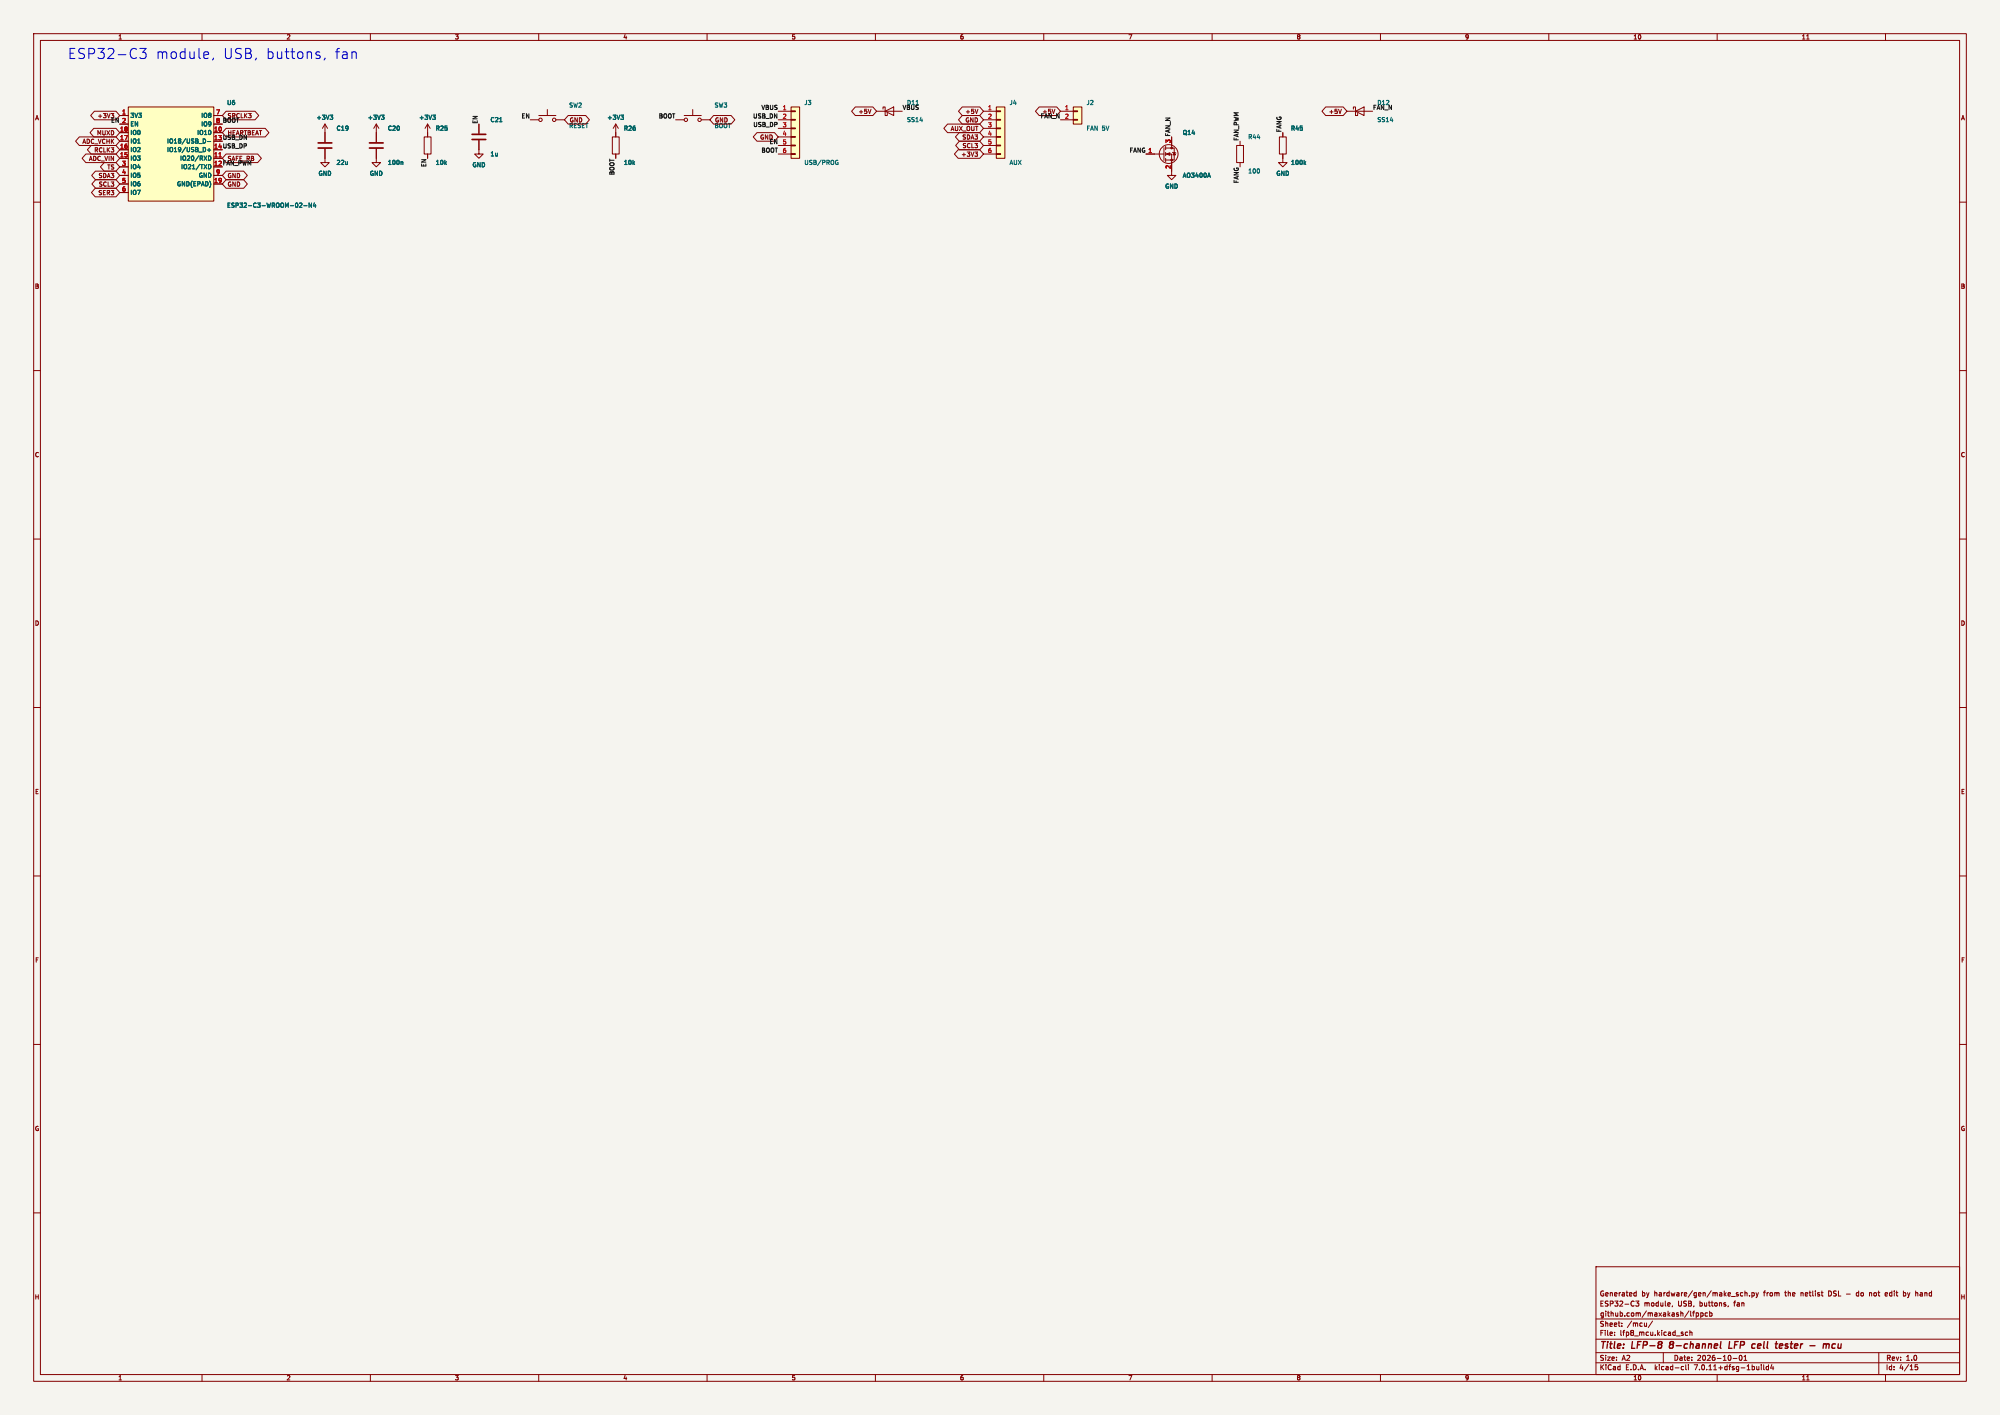
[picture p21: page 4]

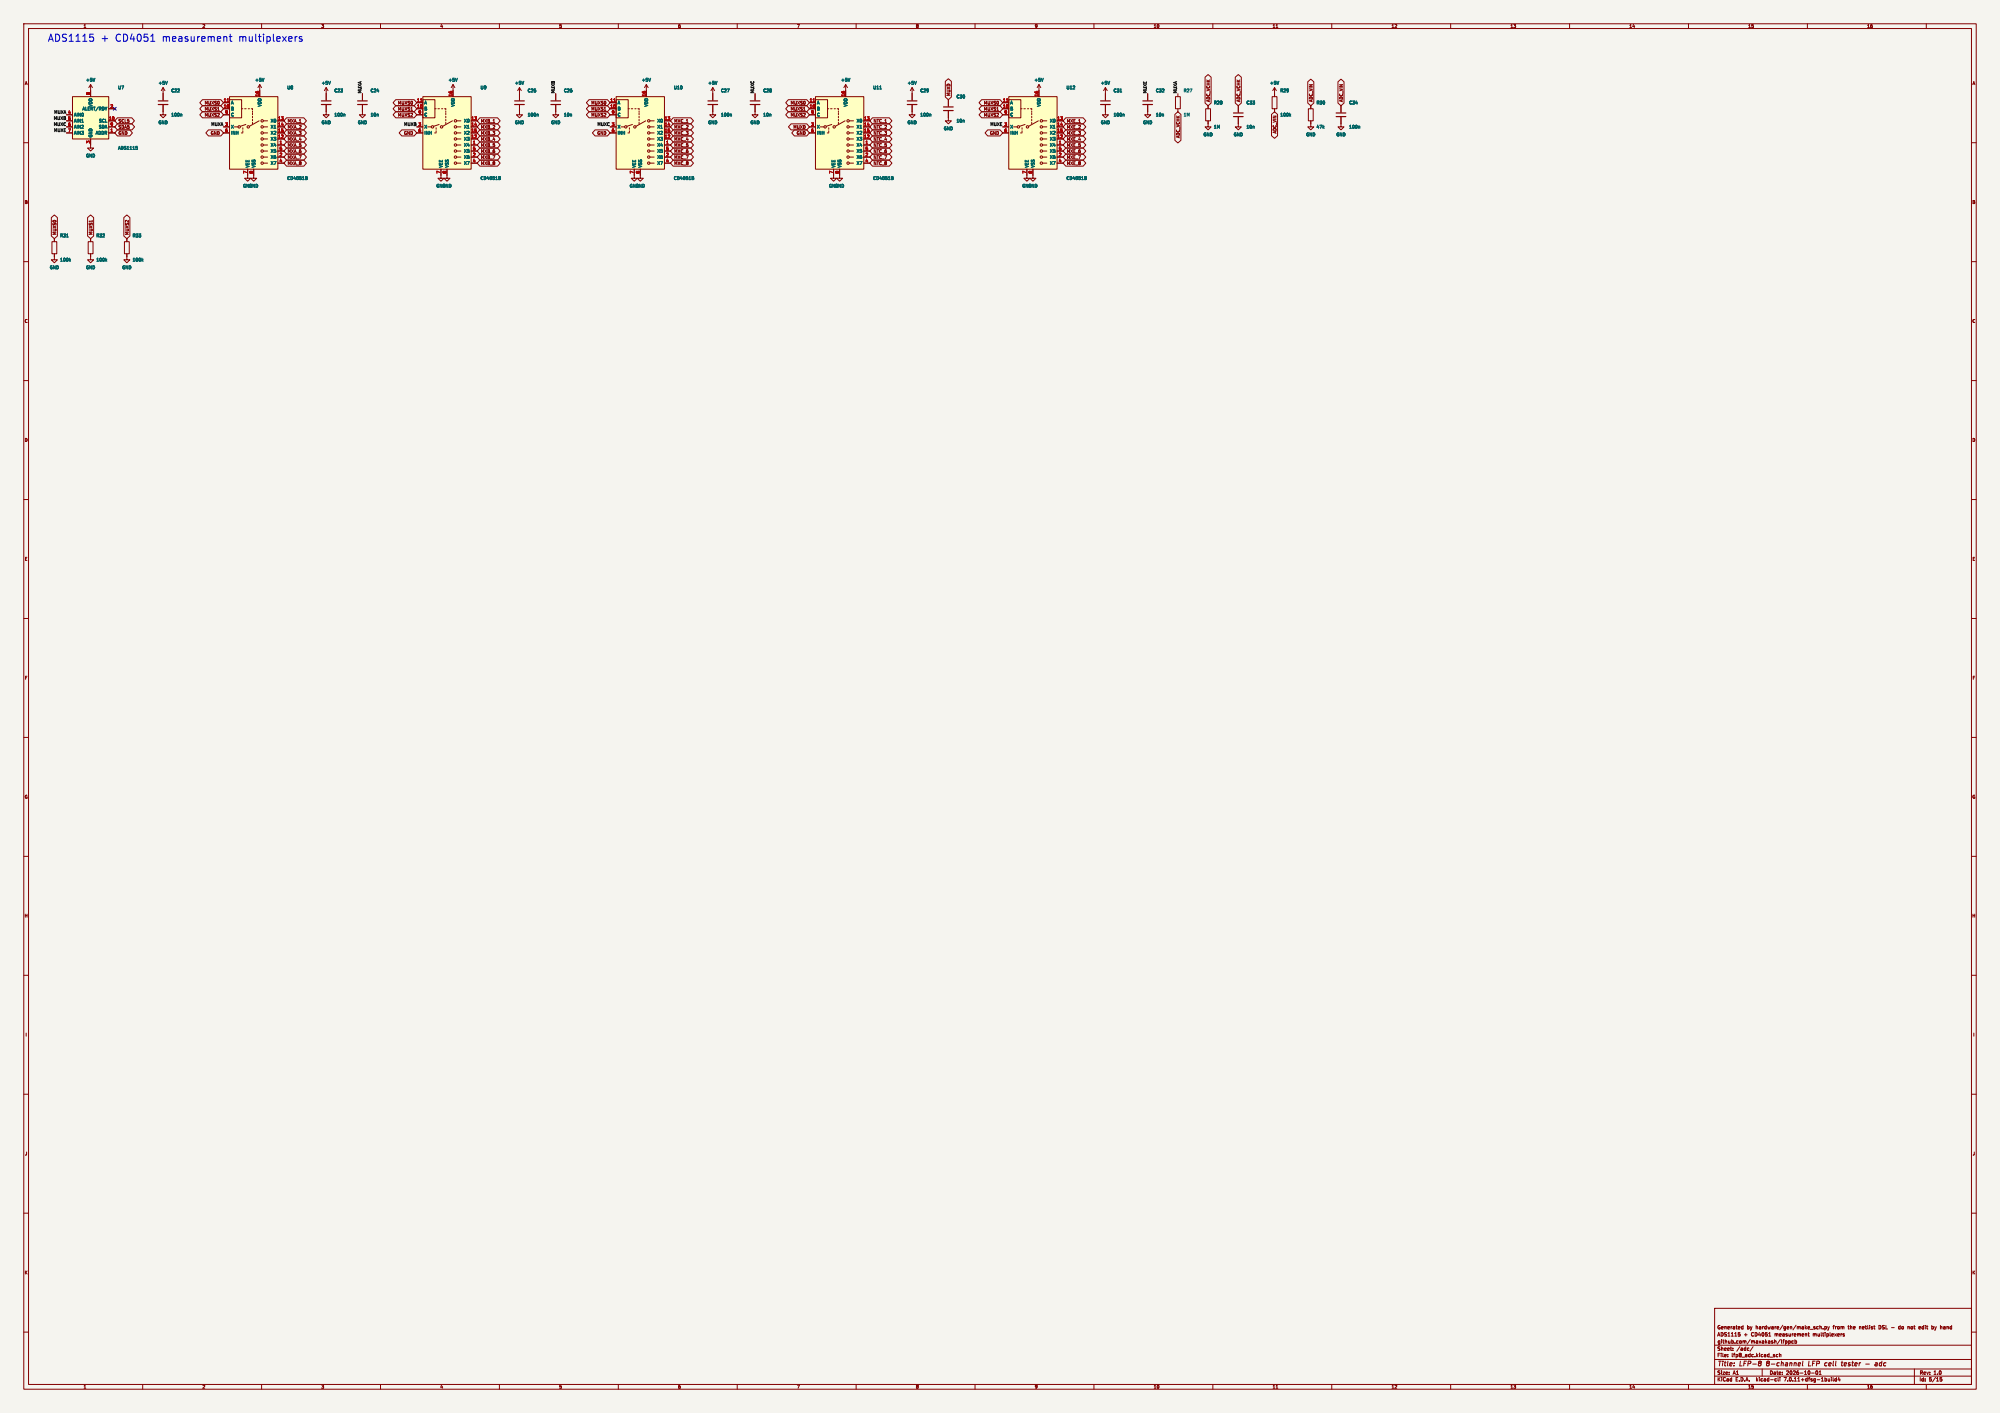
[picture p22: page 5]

U7ADS1115 ADDR 1 SCL 10 ALERT/RDY 2 GND

3 AIN0 4 AIN1 5 AIN2 6 AIN3 7 VDD
ADDR 1 SCL 10 ALERT/RDY 2 GND

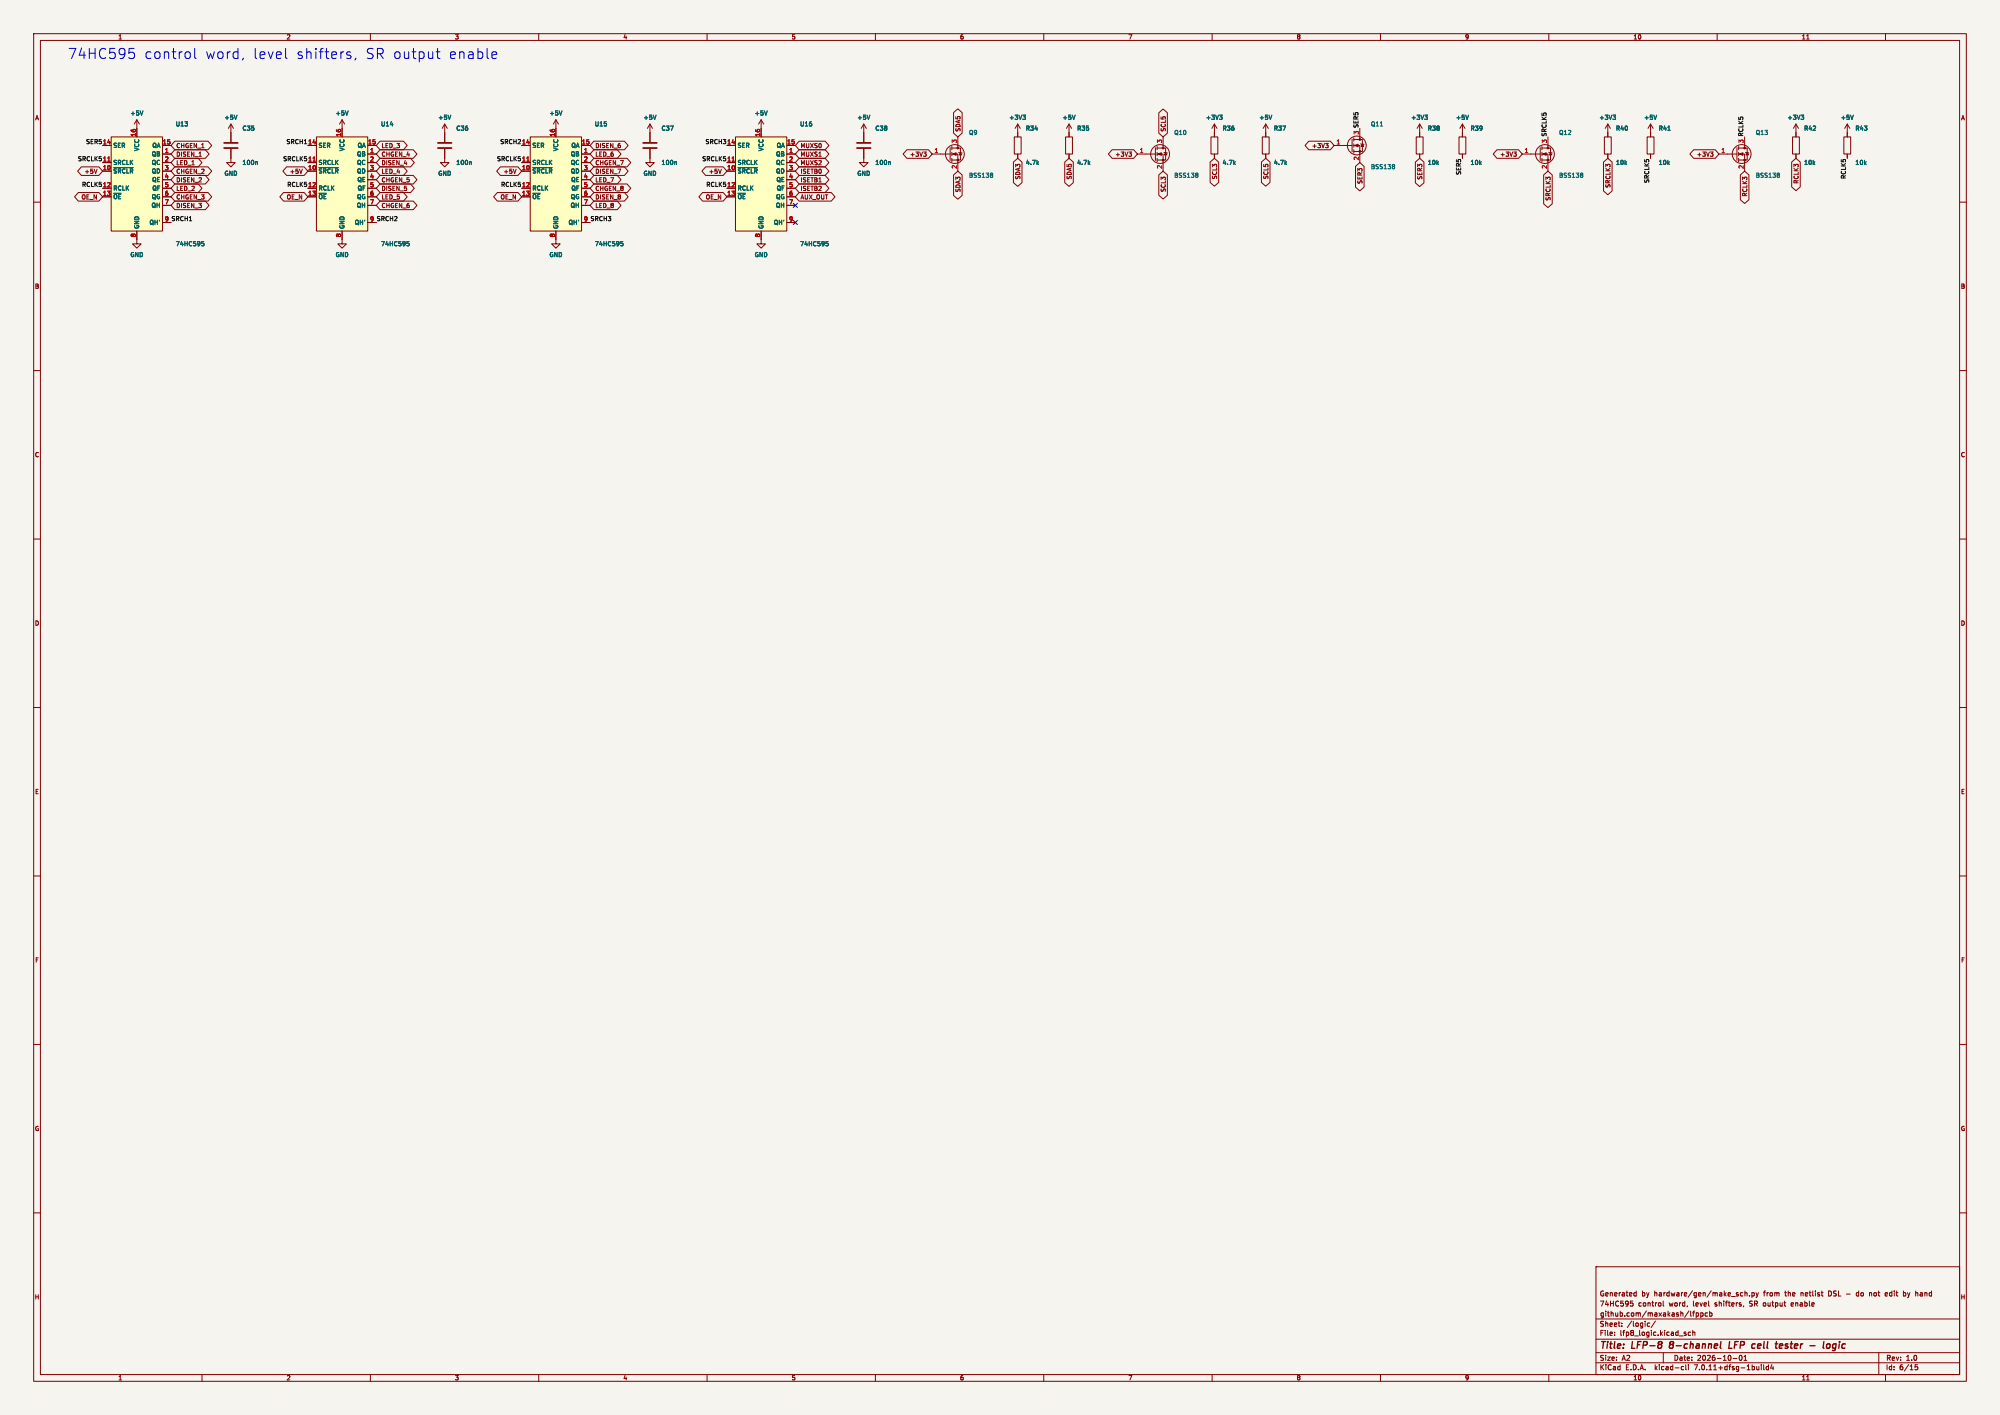
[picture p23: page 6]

SRCH1 SRCLK5 RCLK5 74HC595 control word, level shifters, SR output enable

github.com/maxakash/lfppcb
File: lfp8_logic.kicad_sch Sheet: /logic/

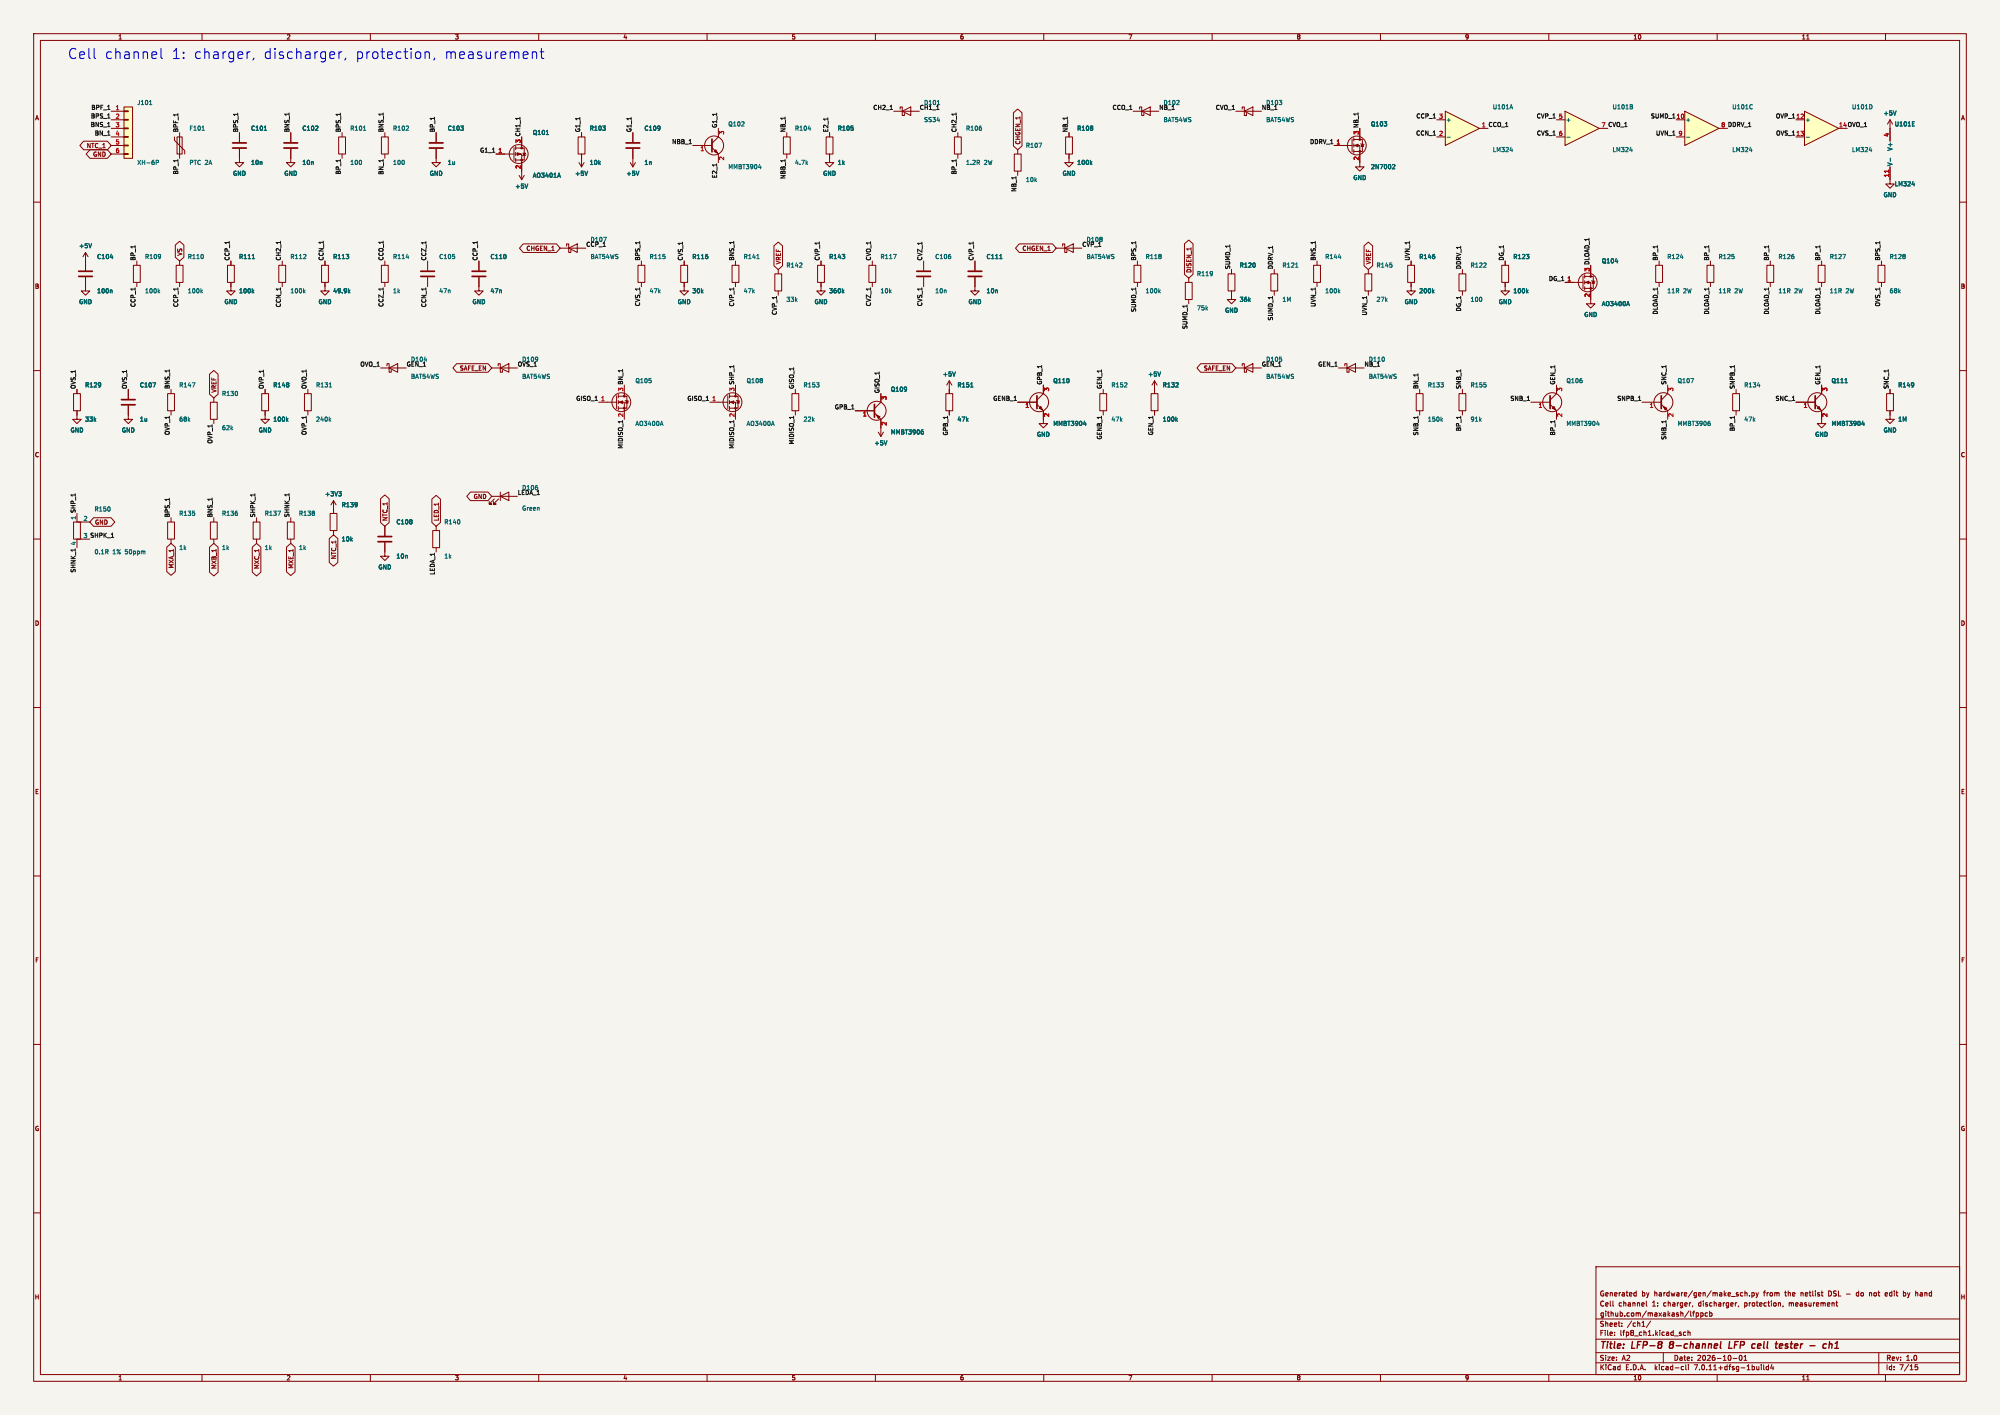
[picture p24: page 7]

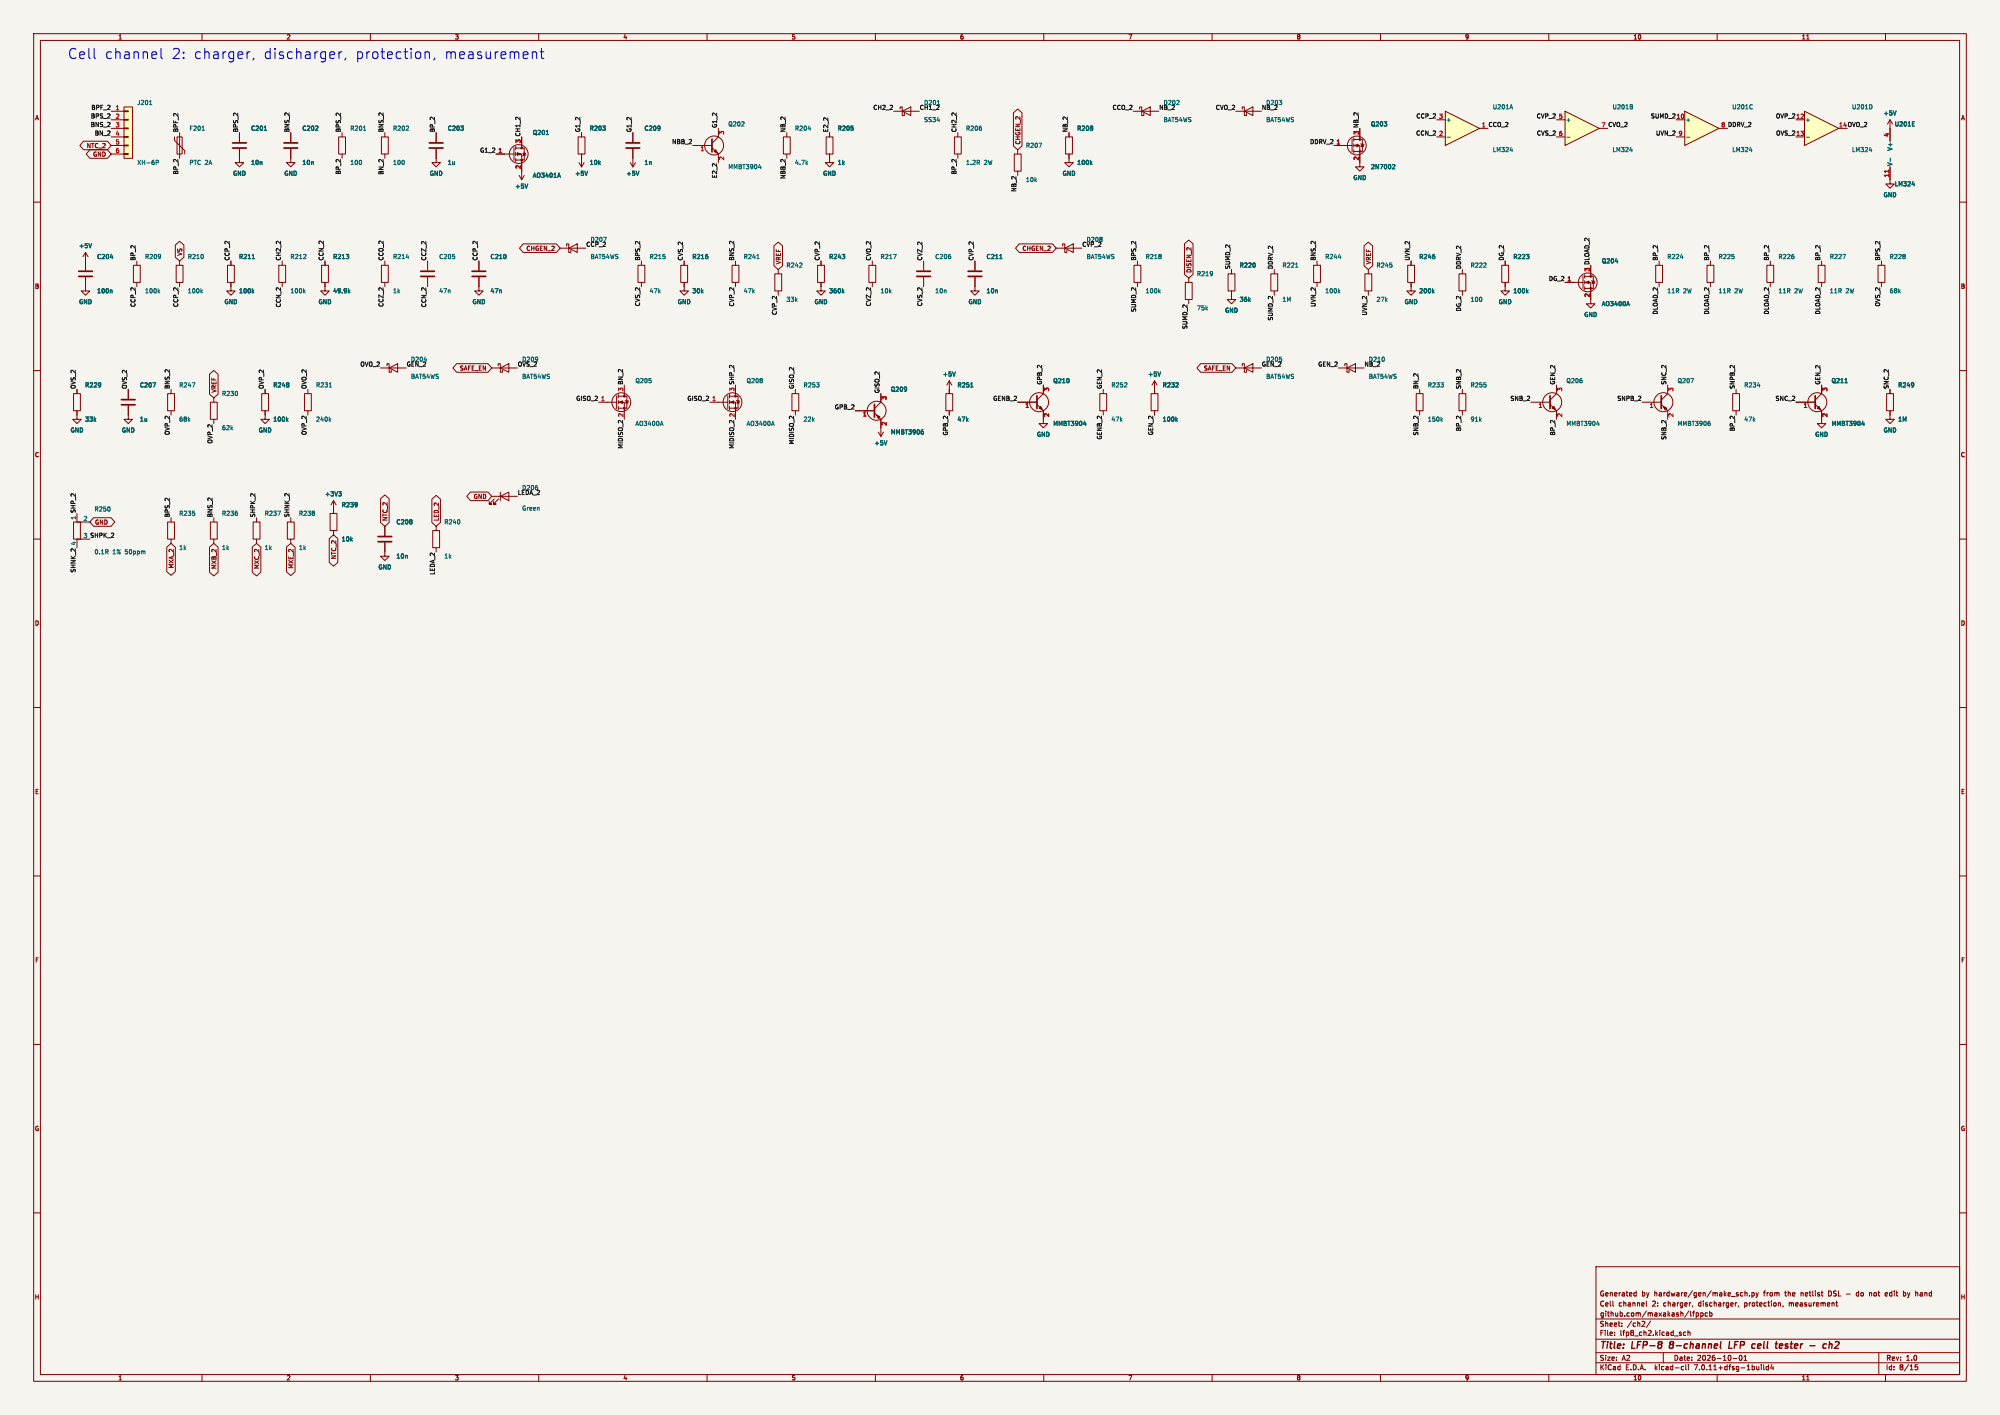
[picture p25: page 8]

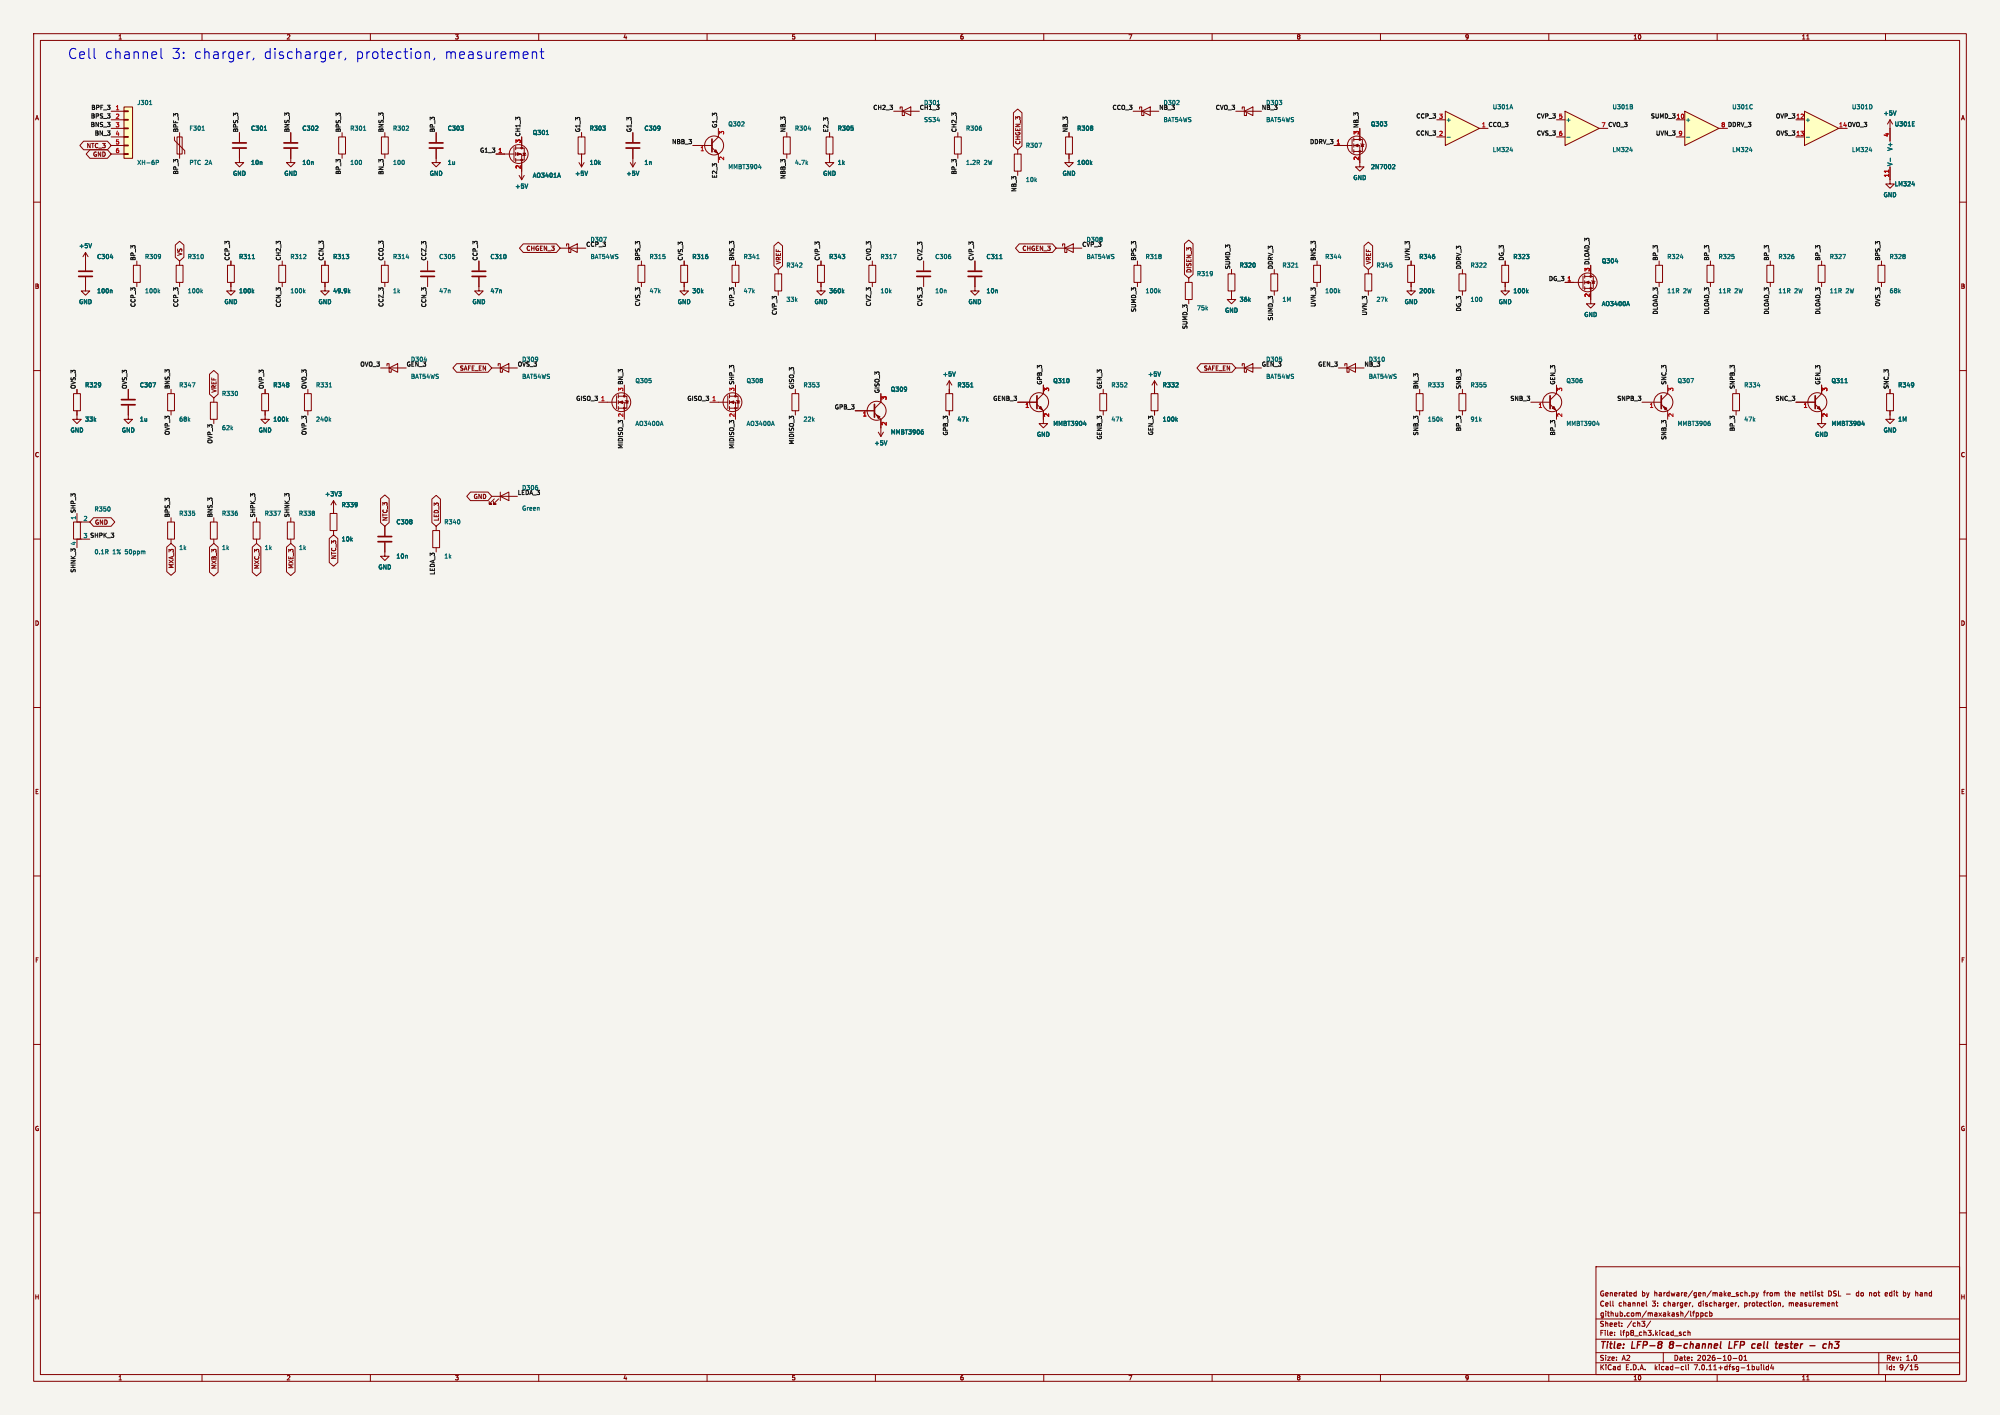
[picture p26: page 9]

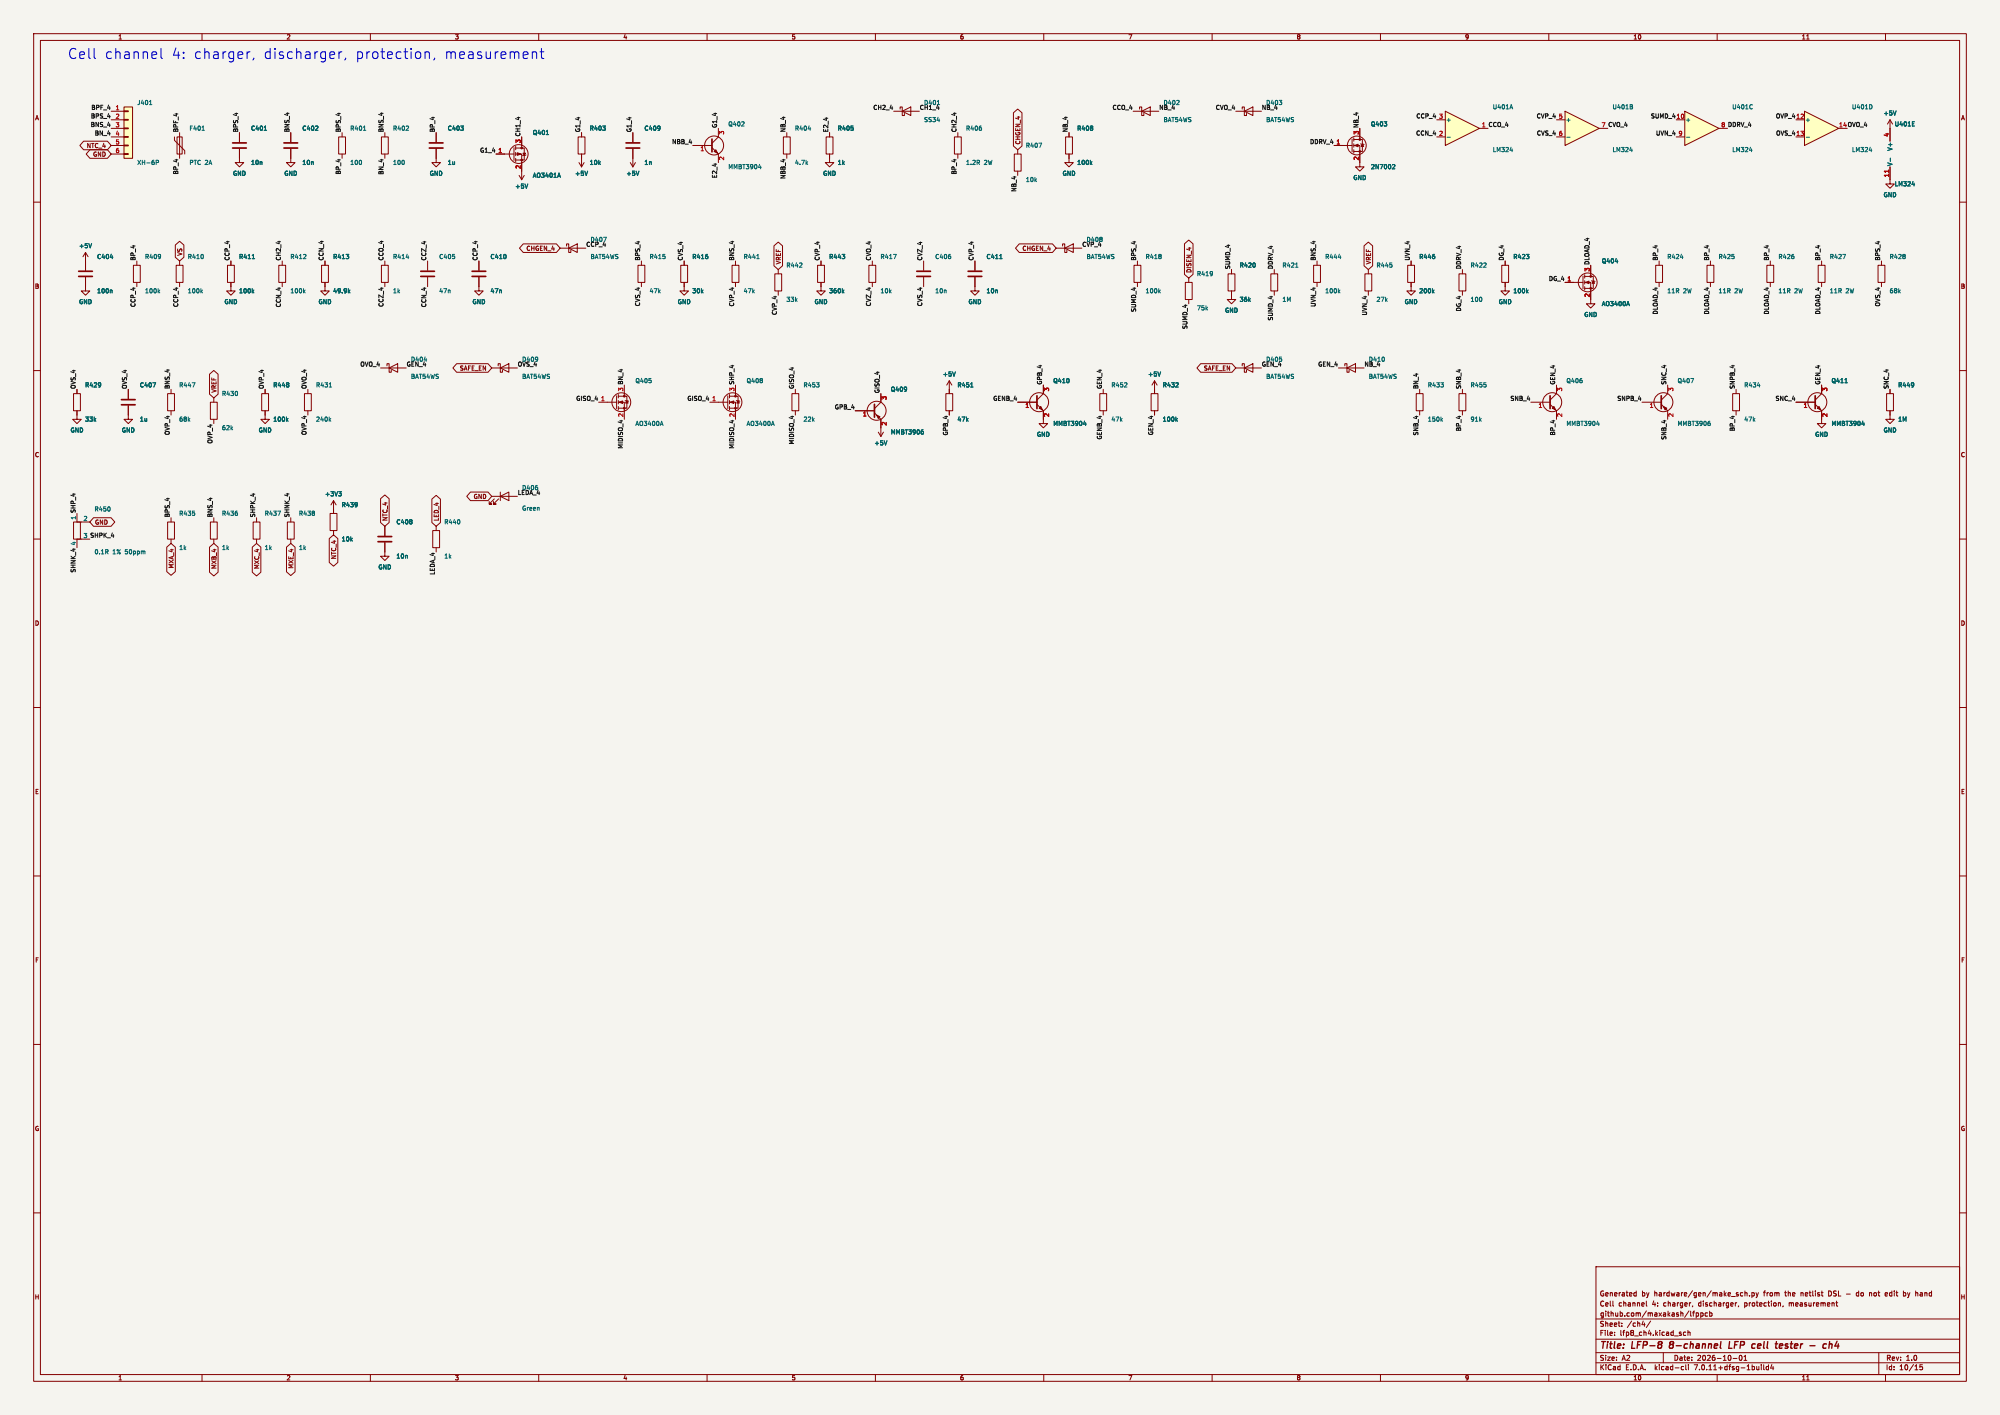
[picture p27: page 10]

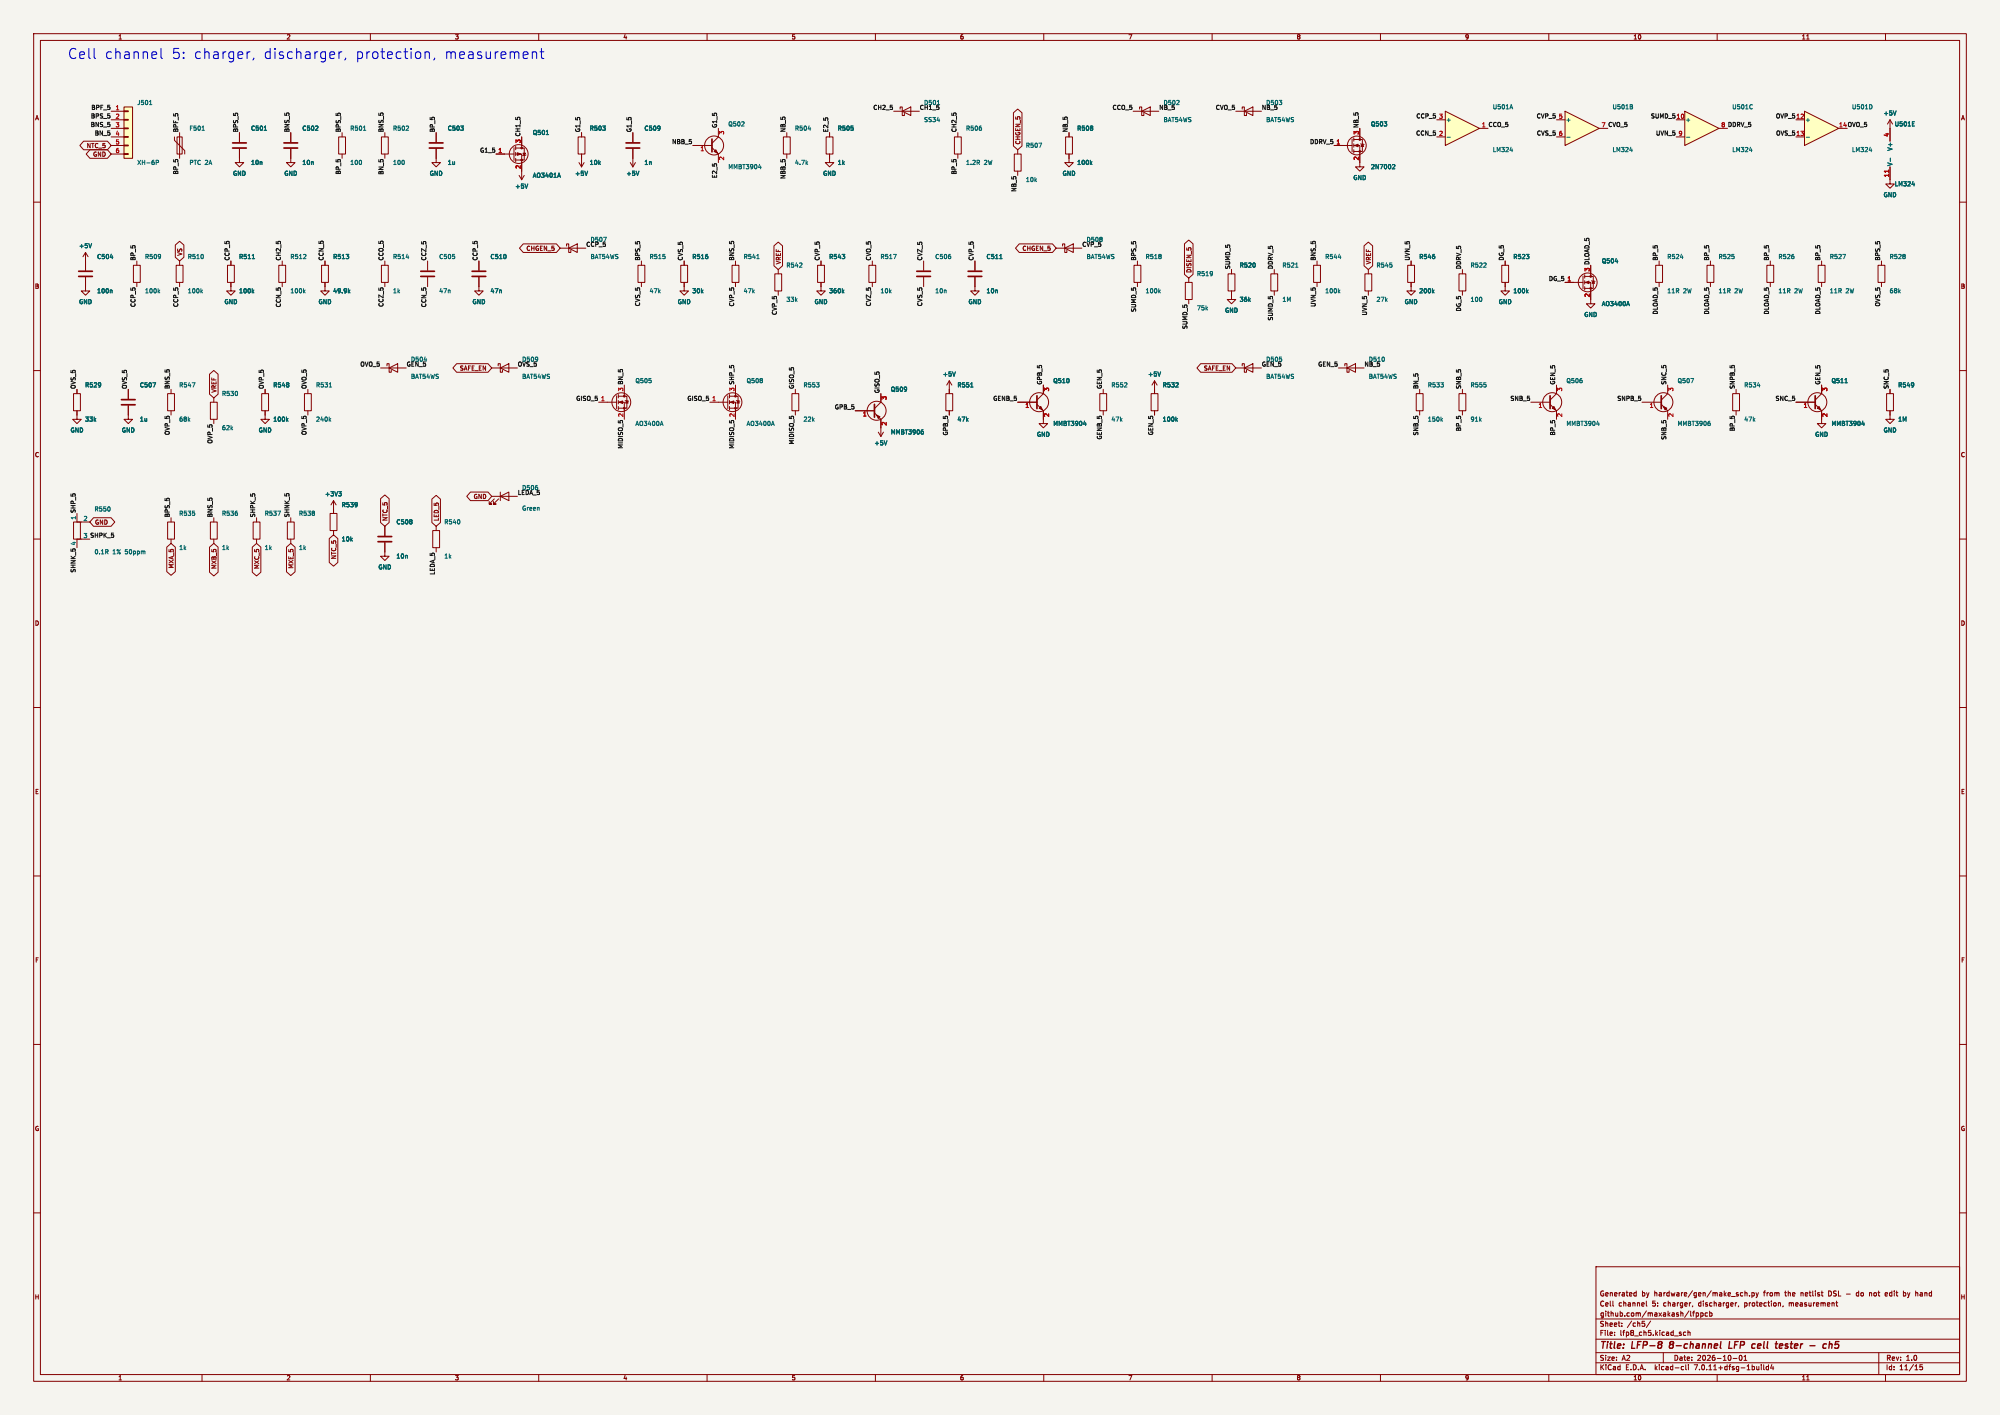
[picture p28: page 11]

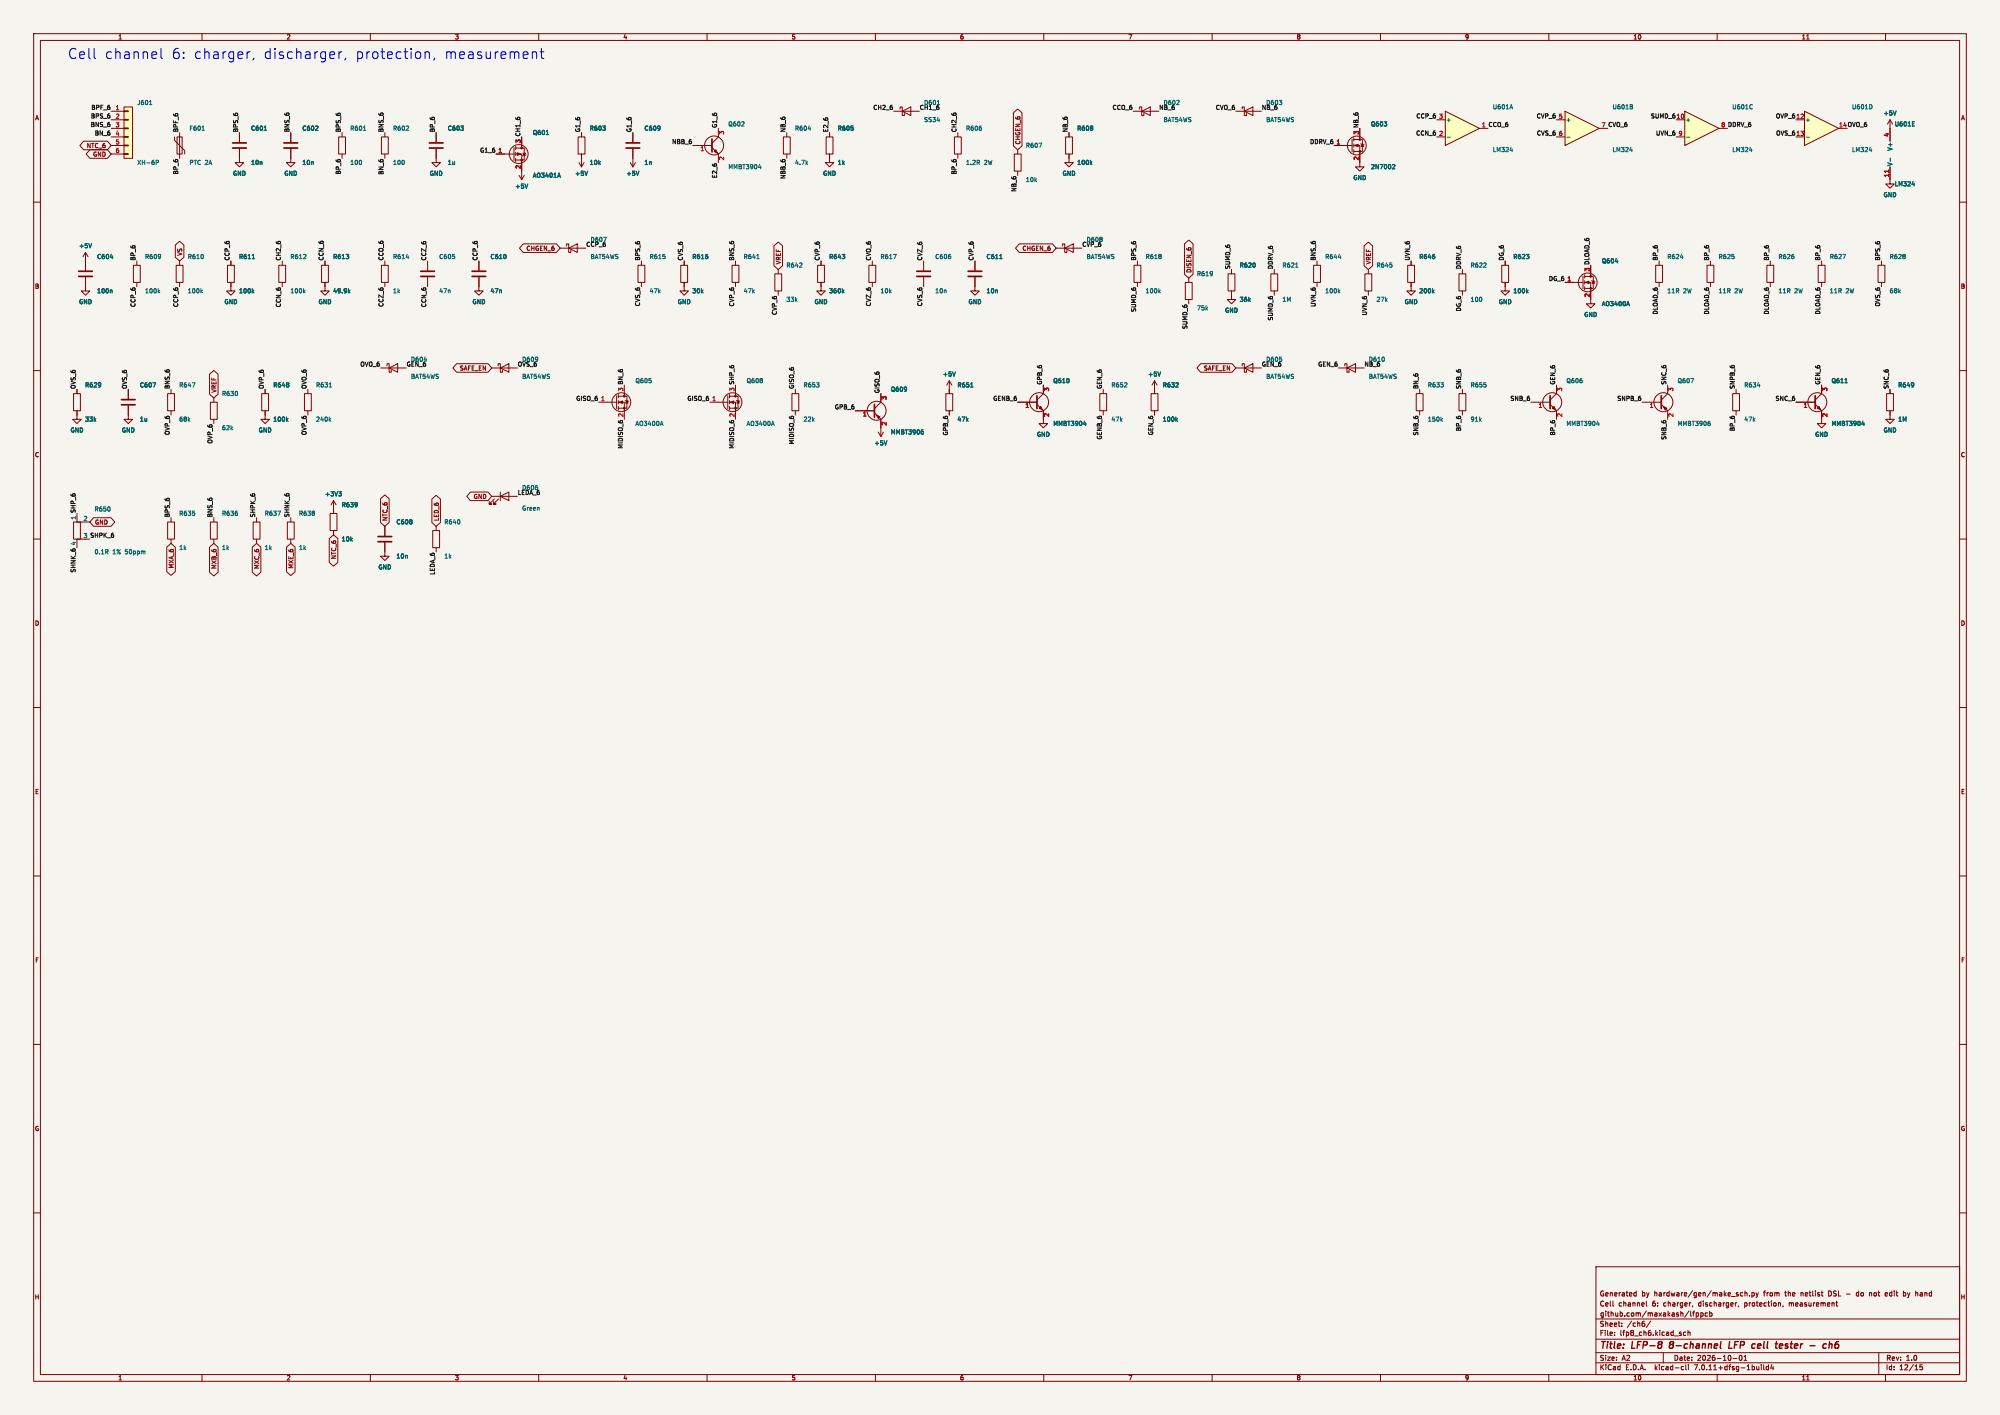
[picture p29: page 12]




File: lfp8_mech.kicad_sch Sheet: /mech/ github.com/maxakash/lfppcb

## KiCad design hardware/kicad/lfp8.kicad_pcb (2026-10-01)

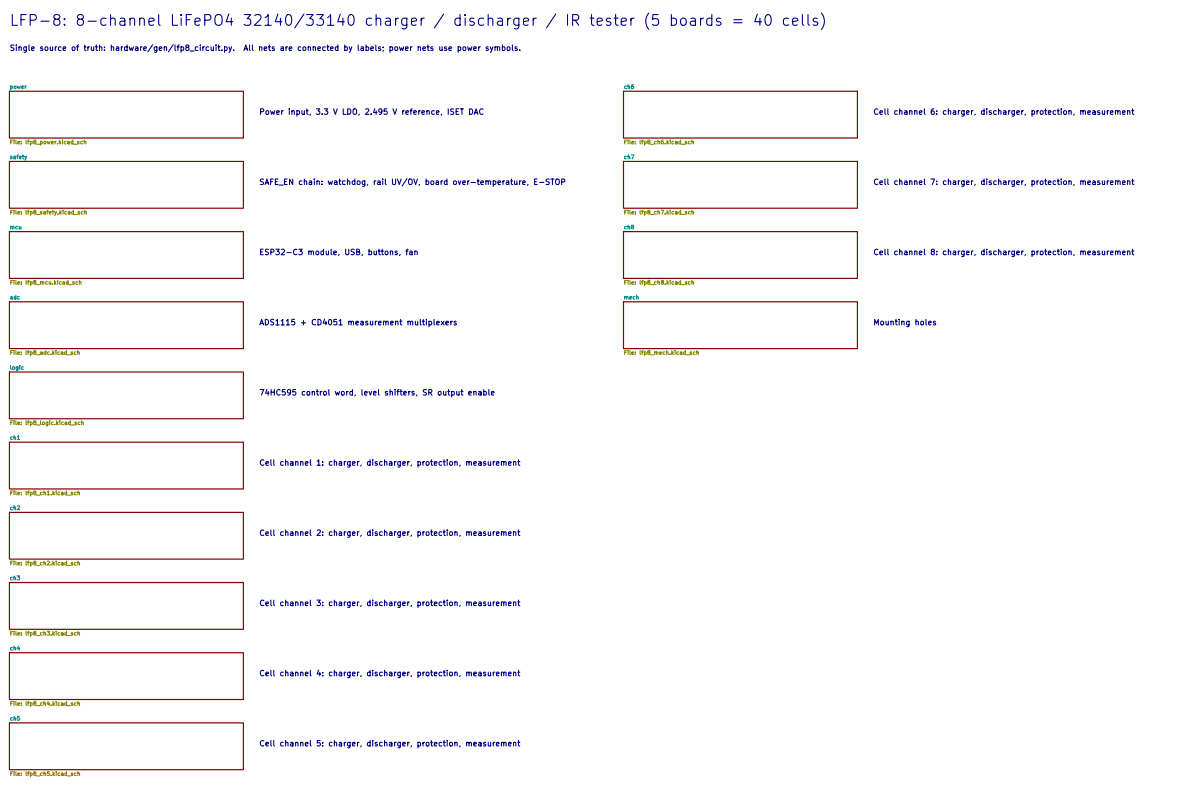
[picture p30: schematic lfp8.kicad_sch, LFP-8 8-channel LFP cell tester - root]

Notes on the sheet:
Power input, 3.3 V LDO, 2.495 V reference, ISET DAC
SAFE_EN chain: watchdog, rail UV/OV, board over-temperature, E-STOP
ESP32-C3 module, USB, buttons, fan
ADS1115 + CD4051 measurement multiplexers
74HC595 control word, level shifters, SR output enable
Cell channel 1: charger, discharger, protection, measurement
Cell channel 2: charger, discharger, protection, measurement
Cell channel 3: charger, discharger, protection, measurement
Cell channel 4: charger, discharger, protection, measurement
Cell channel 5: charger, discharger, protection, measurement
Cell channel 6: charger, discharger, protection, measurement
Cell channel 7: charger, discharger, protection, measurement
Cell channel 8: charger, discharger, protection, measurement
Mounting holes
LFP-8: 8-channel LiFePO4 32140/33140 charger / discharger / IR tester (5 boards = 40 cells)
Single source of truth: hardware/gen/lfp8_circuit.py. All nets are connected by labels; power nets use power symbols.

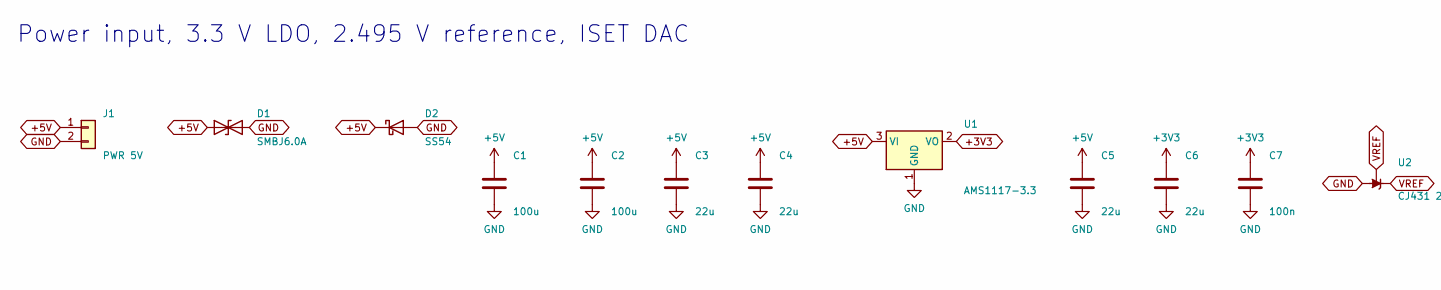
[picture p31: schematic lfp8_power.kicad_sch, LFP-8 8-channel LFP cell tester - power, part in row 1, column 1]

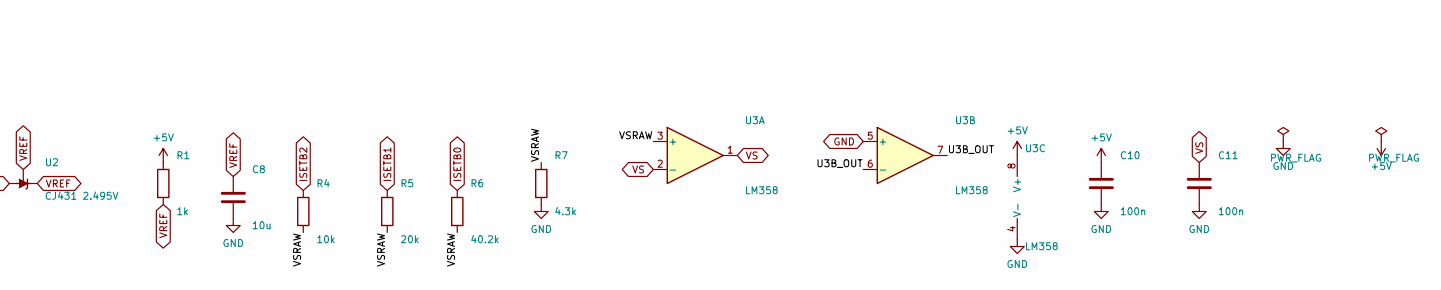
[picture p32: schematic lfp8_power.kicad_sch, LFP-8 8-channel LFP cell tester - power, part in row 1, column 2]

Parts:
C1, C2: 100u; C_1206_3216Metric; LCSC C15008
C3, C4: 22u; C_1206_3216Metric; LCSC C12891
C5, C6: 22u; C_0805_2012Metric; LCSC C45783
C7, C10, C11: 100n; C_0603_1608Metric; LCSC C14663
C8: 10u; C_0805_2012Metric; LCSC C15850
D1: SMBJ6.0A; D_SMB; MPN SMBJ6.0A; LCSC C19077560
D2: SS54; D_SMA; MPN SS54; LCSC C22452
J1: PWR 5V; TerminalBlock_bornier-2_P5.08mm; MPN KF301-5.0-2P / 2-pin 5.08 mm 16 A termi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; JLC Hand
R1: 1k; R_0603_1608Metric; LCSC C21190
R4: 10k; R_0603_1608Metric; LCSC C25804
R5: 20k; R_0603_1608Metric; LCSC C4184
R6: 40.2k; R_0603_1608Metric; LCSC C12447
R7: 4.3k; R_0603_1608Metric; LCSC C23159
U1: AMS1117-3.3; SOT-223-3_TabPin2; MPN AMS1117-3.3; LCSC C6186
U2: CJ431 2.495V; SOT-23; MPN CJ431; LCSC C3113
U3: LM358; SOIC-8_3.9x4.9mm_P1.27mm; MPN LM358DR2G; LCSC C7950

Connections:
+3V3: C6.1, C7.1, U1.2 (VO); also elsewhere on the board
+5V: C1.1, C2.1, C3.1, C4.1, C5.1, C10.1, D1.1 (A1), D2.1 (K), J1.1, R1.1, U1.3 (VI), U3.8 (V+); also elsewhere on the board
/power/U3B_OUT: U3.6 (-), U3.7
/power/VSRAW: R4.2, R5.2, R6.2, R7.1, U3.3 (+)
GND: C1.2, C2.2, C3.2, C4.2, C5.2, C6.2, C7.2, C8.2, C10.2, C11.2, D1.2 (A2), D2.2 (A), J1.2, R7.2, U1.1 (GND), U2.3 (A), U3.4 (V-), U3.5 (+); also elsewhere on the board
ISETB0: R6.1; also elsewhere on the board
ISETB1: R5.1; also elsewhere on the board
ISETB2: R4.1; also elsewhere on the board
VREF: C8.1, R1.2, U2.1 (K), U2.2 (REF); also elsewhere on the board
VS: C11.1, U3.1, U3.2 (-); also elsewhere on the board

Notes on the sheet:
Power input, 3.3 V LDO, 2.495 V reference, ISET DAC

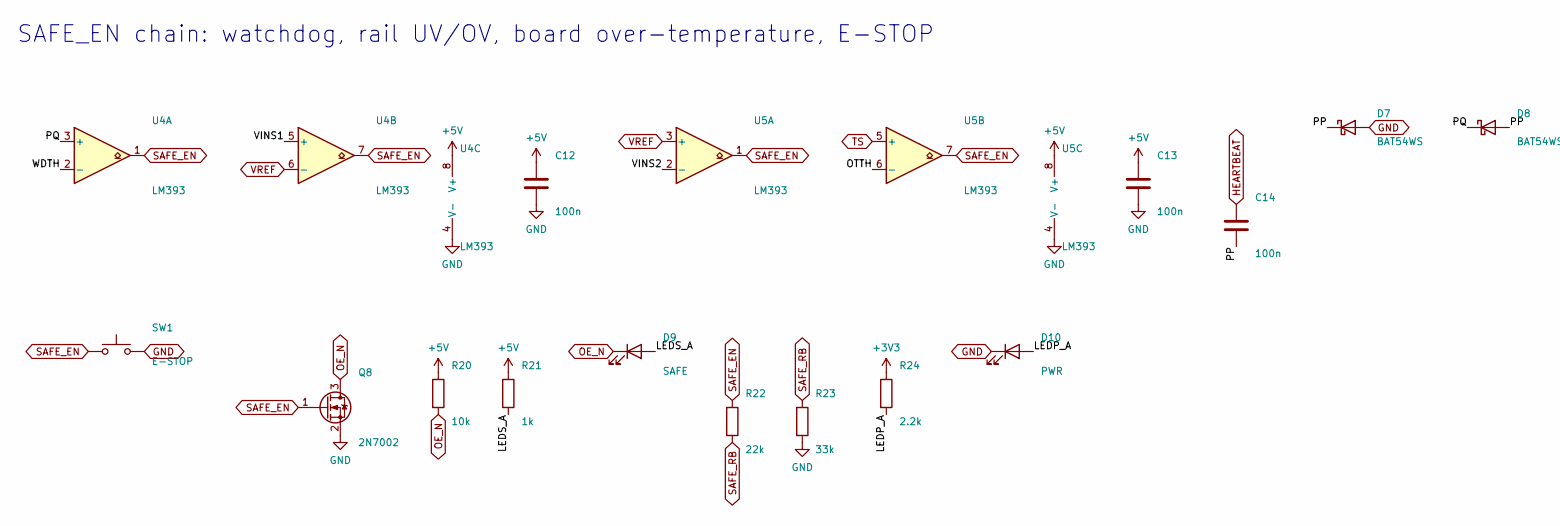
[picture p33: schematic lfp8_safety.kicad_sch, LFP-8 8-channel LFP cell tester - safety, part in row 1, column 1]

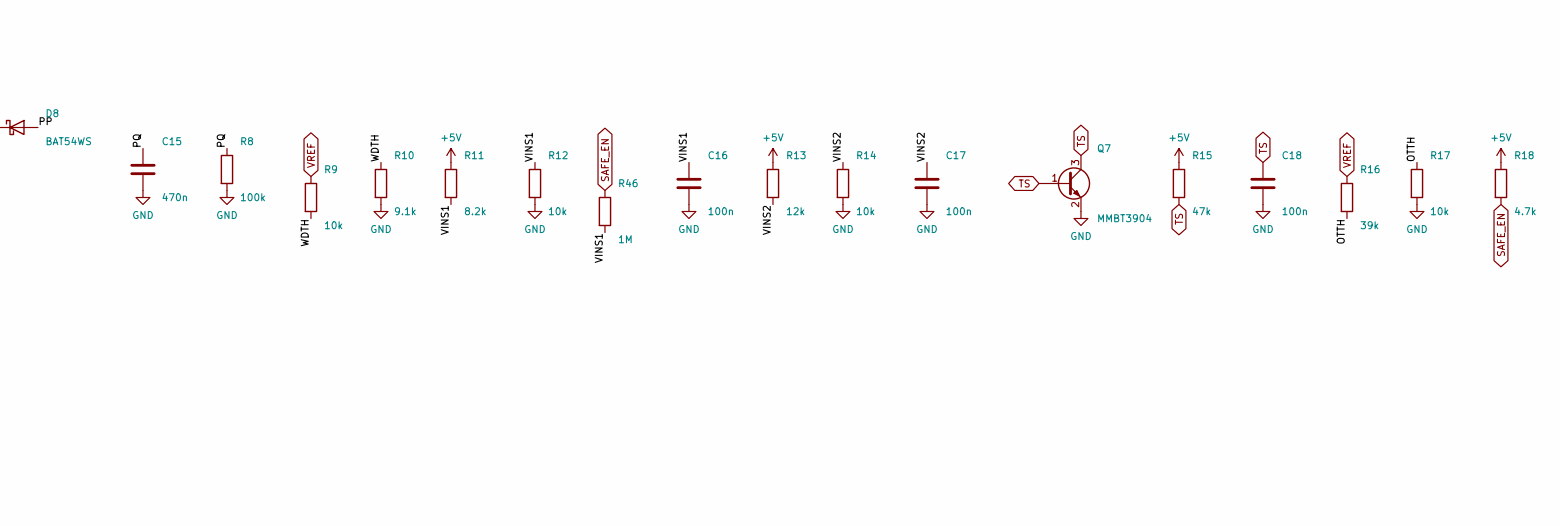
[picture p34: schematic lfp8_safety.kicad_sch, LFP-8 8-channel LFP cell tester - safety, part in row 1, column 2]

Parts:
C12, C13, C14, C16, C17, C18: 100n; C_0603_1608Metric; LCSC C14663
C15: 470n; C_0603_1608Metric; LCSC C1623
D7, D8: BAT54WS; D_SOD-323; MPN BAT54WS; LCSC C7502694
D9: SAFE; LED_0805_2012Metric; MPN 0805 green; LCSC C2297
D10: PWR; LED_0603_1608Metric; MPN 0603 red; LCSC C2286
Q7: MMBT3904; SOT-23; MPN MMBT3904; LCSC C20526
Q8: 2N7002; SOT-23; MPN 2N7002; LCSC C8545
R8: 100k; R_0603_1608Metric; LCSC C25803
R9, R12, R14, R17, R20: 10k; R_0603_1608Metric; LCSC C25804
R10: 9.1k; R_0603_1608Metric; LCSC C23260
R11: 8.2k; R_0603_1608Metric; LCSC C25981
R13: 12k; R_0603_1608Metric; LCSC C22790
R15: 47k; R_0603_1608Metric; LCSC C25819
R16: 39k; R_0603_1608Metric; LCSC C23153
R18: 4.7k; R_0603_1608Metric; LCSC C23162
R21: 1k; R_0603_1608Metric; LCSC C21190
R22: 22k; R_0603_1608Metric; LCSC C31850
R23: 33k; R_0603_1608Metric; LCSC C4216
R24: 2.2k; R_0603_1608Metric; LCSC C4190
R46: 1M; R_0603_1608Metric; LCSC C22935
SW1: E-STOP; SW_SMD_5.1x5.1_4P; MPN TS-1088 type 5.1x5.1; LCSC C318884
U4, U5: LM393; SOIC-8_3.9x4.9mm_P1.27mm; MPN LM393DR2G; LCSC C7955

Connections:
+3V3: R24.1; also elsewhere on the board
+5V: C12.1, C13.1, R11.1, R13.1, R15.1, R18.1, R20.1, R21.1, U4.8 (V+), U5.8 (V+); also elsewhere on the board
/safety/LEDP_A: D10.2 (A), R24.2
/safety/LEDS_A: D9.2 (A), R21.2
/safety/OTTH: R16.2, R17.1, U5.6 (-)
/safety/PP: C14.2, D7.1 (K), D8.2 (A)
/safety/PQ: C15.1, D8.1 (K), R8.1, U4.3 (+)
/safety/VINS1: C16.1, R11.2, R12.1, R46.2, U4.5 (+)
/safety/VINS2: C17.1, R13.2, R14.1, U5.2 (-)
/safety/WDTH: R9.2, R10.1, U4.2 (-)
GND: C12.2, C13.2, C15.2, C16.2, C17.2, C18.2, D7.2 (A), D10.1 (K), Q7.2 (E), Q8.2 (S), R8.2, R10.2, R12.2, R14.2, R17.2, R23.2, SW1.2, U4.4 (V-), U5.4 (V-); also elsewhere on the board
HEARTBEAT: C14.1; also elsewhere on the board
OE_N: D9.1 (K), Q8.3 (D), R20.2; also elsewhere on the board
SAFE_EN: Q8.1 (G), R18.2, R22.1, R46.1, SW1.1, U4.1, U4.7, U5.1, U5.7; also elsewhere on the board
SAFE_RB: R22.2, R23.1; also elsewhere on the board
TS: C18.1, Q7.1 (B), Q7.3 (C), R15.2, U5.5 (+); also elsewhere on the board
VREF: R9.1, R16.1, U4.6 (-), U5.3 (+); also elsewhere on the board

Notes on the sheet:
SAFE_EN chain: watchdog, rail UV/OV, board over-temperature, E-STOP

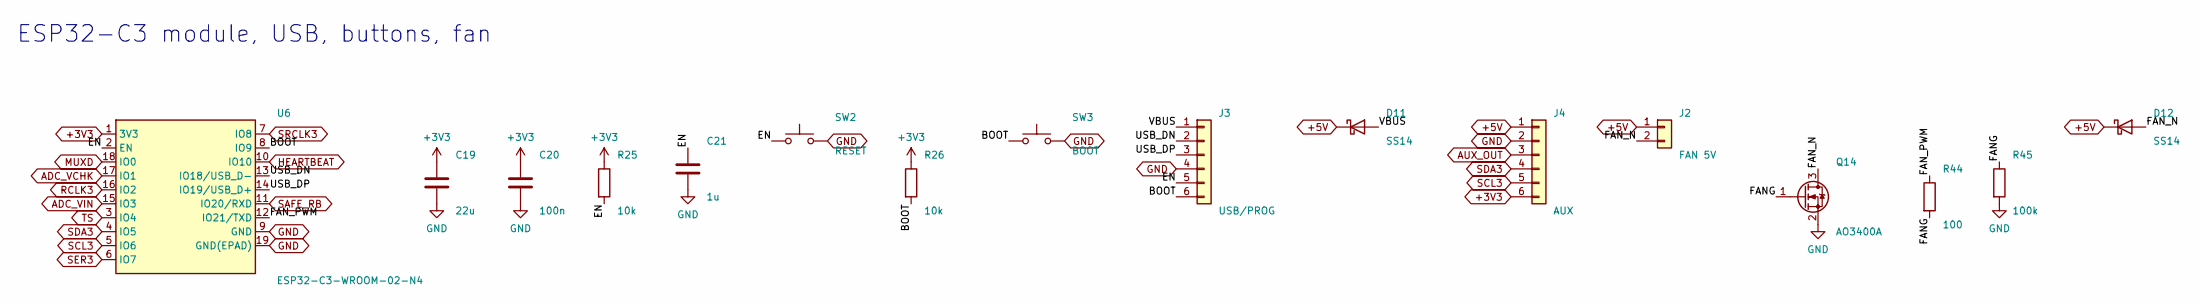
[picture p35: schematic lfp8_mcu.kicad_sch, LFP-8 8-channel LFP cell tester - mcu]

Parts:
C19: 22u; C_0805_2012Metric; LCSC C45783
C20: 100n; C_0603_1608Metric; LCSC C14663
C21: 1u; C_0603_1608Metric; LCSC C15849
D11, D12: SS14; D_SMA; MPN SS14; LCSC C2480
J2: FAN 5V; PinHeader_1x02_P2.54mm_Vertical; MPN 2.54 mm header; JLC Hand
J3: USB/PROG; PinHeader_1x06_P2.54mm_Vertical; MPN 2.54 mm header; JLC Hand
J4: AUX; PinHeader_1x06_P2.54mm_Vertical; MPN 2.54 mm header; JLC Hand
Q14: AO3400A; SOT-23; MPN AO3400A; LCSC C20917
R25, R26: 10k; R_0603_1608Metric; LCSC C25804
R44: 100; R_0603_1608Metric; LCSC C22775
R45: 100k; R_0603_1608Metric; LCSC C25803
SW2: RESET; SW_SMD_5.1x5.1_4P; MPN TS-1088 type 5.1x5.1; LCSC C318884
SW3: BOOT; SW_SMD_5.1x5.1_4P; MPN TS-1088 type 5.1x5.1; LCSC C318884
U6: ESP32-C3-WROOM-02-N4; ESP32-C3-WROOM-02; MPN ESP32-C3-WROOM-02-N4; LCSC C2934560

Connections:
+3V3: C19.1, C20.1, J4.6, R25.1, R26.1, U6.1 (3V3); also elsewhere on the board
+5V: D11.1 (K), D12.1 (K), J2.1, J4.1; also elsewhere on the board
/mcu/BOOT: J3.6, R26.2, SW3.1, U6.8 (IO9)
/mcu/EN: C21.1, J3.5, R25.2, SW2.1, U6.2 (EN)
/mcu/FANG: Q14.1 (G), R44.2, R45.1
/mcu/FAN_N: D12.2 (A), J2.2, Q14.3 (D)
/mcu/FAN_PWM: R44.1, U6.12 (IO21/TXD)
/mcu/USB_DN: J3.2, U6.13 (IO18/USB_D-)
/mcu/USB_DP: J3.3, U6.14 (IO19/USB_D+)
/mcu/VBUS: D11.2 (A), J3.1
ADC_VCHK: U6.17 (IO1); also elsewhere on the board
ADC_VIN: U6.15 (IO3); also elsewhere on the board
AUX_OUT: J4.3; also elsewhere on the board
GND: C19.2, C20.2, C21.2, J3.4, J4.2, Q14.2 (S), R45.2, SW2.2, SW3.2, U6.9 (GND), U6.19 (GND(EPAD)); also elsewhere on the board
HEARTBEAT: U6.10 (IO10); also elsewhere on the board
MUXD: U6.18 (IO0); also elsewhere on the board
RCLK3: U6.16 (IO2); also elsewhere on the board
SAFE_RB: U6.11 (IO20/RXD); also elsewhere on the board
SCL3: J4.5, U6.5 (IO6); also elsewhere on the board
SDA3: J4.4, U6.4 (IO5); also elsewhere on the board
SER3: U6.6 (IO7); also elsewhere on the board
SRCLK3: U6.7 (IO8); also elsewhere on the board
TS: U6.3 (IO4); also elsewhere on the board

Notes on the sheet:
ESP32-C3 module, USB, buttons, fan

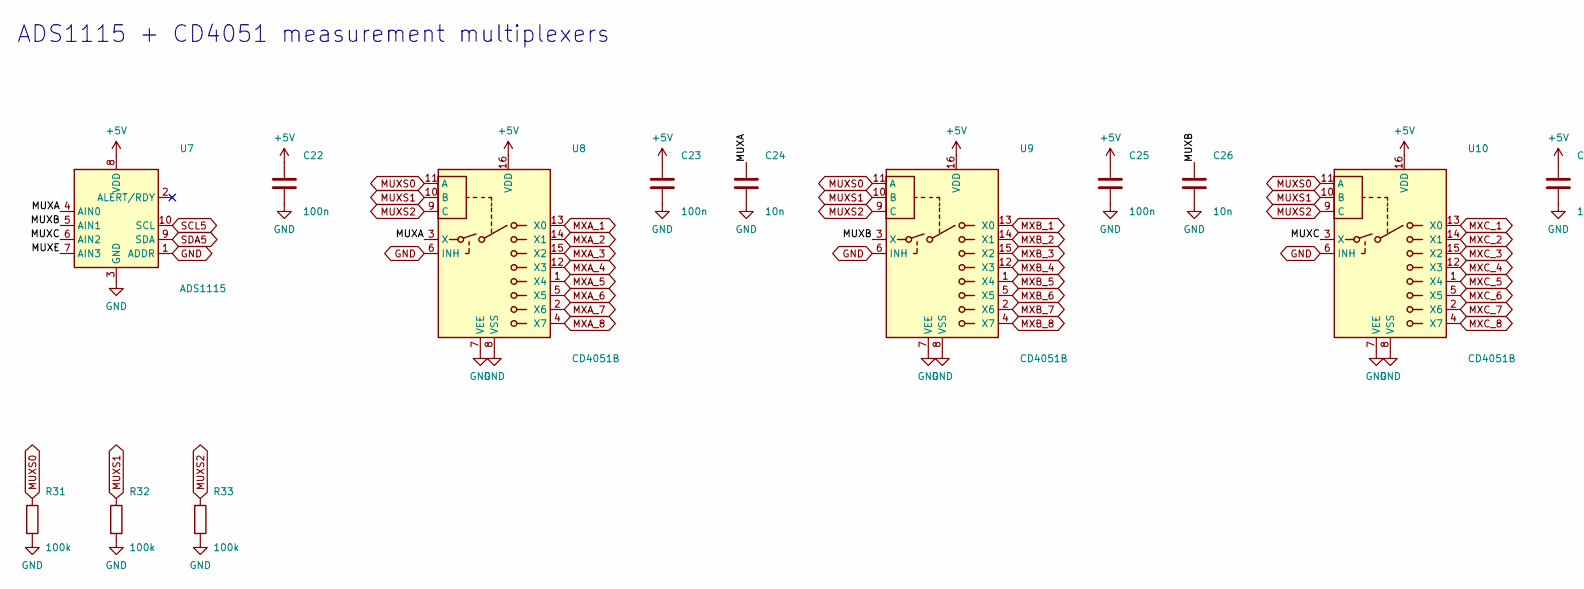
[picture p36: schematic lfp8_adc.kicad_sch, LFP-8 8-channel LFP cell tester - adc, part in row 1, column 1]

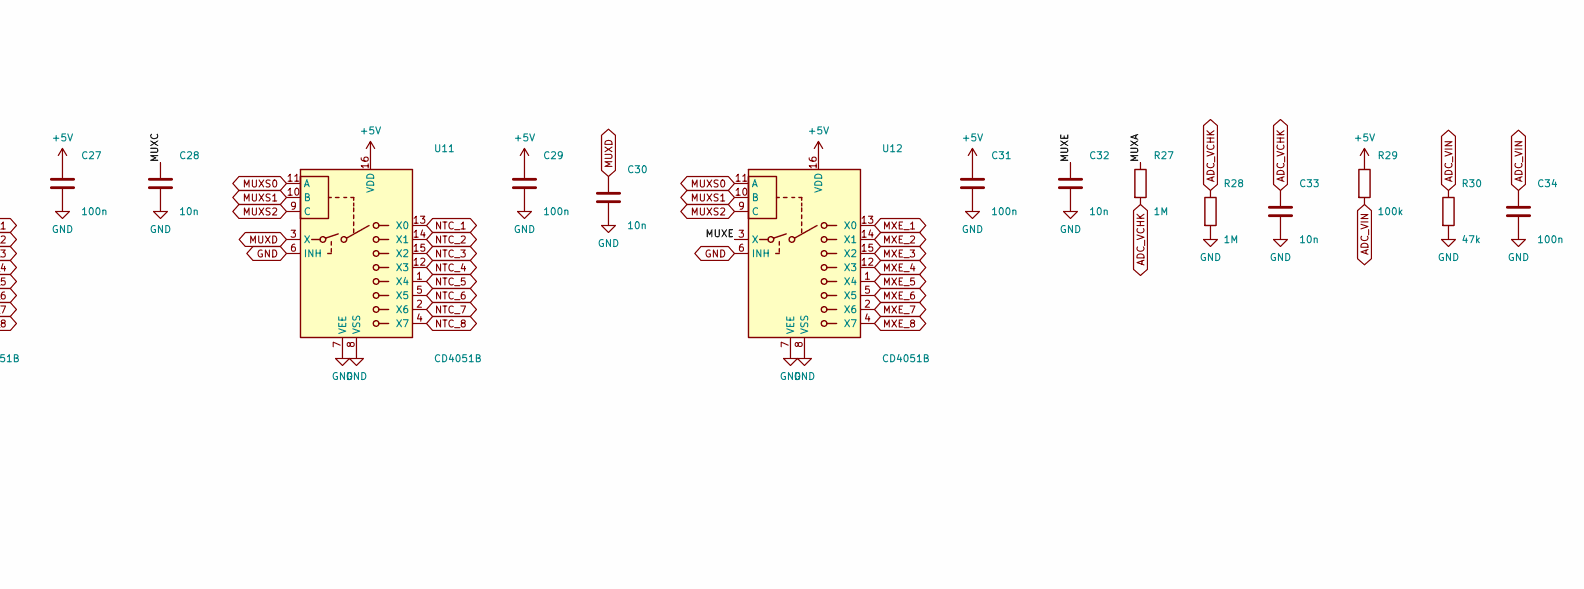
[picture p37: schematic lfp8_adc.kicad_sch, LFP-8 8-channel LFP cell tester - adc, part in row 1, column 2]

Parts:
C22, C23, C25, C27, C29, C31, C34: 100n; C_0603_1608Metric; LCSC C14663
C24, C26, C28, C30, C32, C33: 10n; C_0603_1608Metric; LCSC C57112
R27, R28: 1M; R_0603_1608Metric; LCSC C22935
R29, R31, R32, R33: 100k; R_0603_1608Metric; LCSC C25803
R30: 47k; R_0603_1608Metric; LCSC C25819
U7: ADS1115; TSSOP-10_3x3mm_P0.5mm; MPN ADS1115IDGSR; LCSC C37593
U8, U9, U10, U11, U12: CD4051B; SOIC-16_3.9x9.9mm_P1.27mm; MPN CD4051BM96; LCSC C21379

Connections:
+5V: C22.1, C23.1, C25.1, C27.1, C29.1, C31.1, R29.1, U7.8 (VDD), U8.16 (VDD), U9.16 (VDD), U10.16 (VDD), U11.16 (VDD), U12.16 (VDD); also elsewhere on the board
/adc/MUXA: C24.1, R27.1, U7.4 (AIN0), U8.3 (X)
/adc/MUXB: C26.1, U7.5 (AIN1), U9.3 (X)
/adc/MUXC: C28.1, U7.6 (AIN2), U10.3 (X)
/adc/MUXE: C32.1, U7.7 (AIN3), U12.3 (X)
ADC_VCHK: C33.1, R27.2, R28.1; also elsewhere on the board
ADC_VIN: C34.1, R29.2, R30.1; also elsewhere on the board
GND: C22.2, C23.2, C24.2, C25.2, C26.2, C27.2, C28.2, C29.2, C30.2, C31.2, C32.2, C33.2, C34.2, R28.2, R30.2, R31.2, R32.2, R33.2, U7.1 (ADDR), U7.3 (GND), U8.6 (INH), U8.7 (VEE), U8.8 (VSS), U9.6 (INH), U9.7 (VEE), U9.8 (VSS), U10.6 (INH), U10.7 (VEE), U10.8 (VSS), U11.6 (INH), U11.7 (VEE), U11.8 (VSS), U12.6 (INH), U12.7 (VEE), U12.8 (VSS); also elsewhere on the board
MUXD: C30.1, U11.3 (X); also elsewhere on the board
MUXS0: R31.1, U8.11 (A), U9.11 (A), U10.11 (A), U11.11 (A), U12.11 (A); also elsewhere on the board
MUXS1: R32.1, U8.10 (B), U9.10 (B), U10.10 (B), U11.10 (B), U12.10 (B); also elsewhere on the board
MUXS2: R33.1, U8.9 (C), U9.9 (C), U10.9 (C), U11.9 (C), U12.9 (C); also elsewhere on the board
MXA_1: U8.13 (X0); also elsewhere on the board
MXA_2: U8.14 (X1); also elsewhere on the board
MXA_3: U8.15 (X2); also elsewhere on the board
MXA_4: U8.12 (X3); also elsewhere on the board
MXA_5: U8.1 (X4); also elsewhere on the board
MXA_6: U8.5 (X5); also elsewhere on the board
MXA_7: U8.2 (X6); also elsewhere on the board
MXA_8: U8.4 (X7); also elsewhere on the board
MXB_1: U9.13 (X0); also elsewhere on the board
MXB_2: U9.14 (X1); also elsewhere on the board
MXB_3: U9.15 (X2); also elsewhere on the board
MXB_4: U9.12 (X3); also elsewhere on the board
MXB_5: U9.1 (X4); also elsewhere on the board
MXB_6: U9.5 (X5); also elsewhere on the board
MXB_7: U9.2 (X6); also elsewhere on the board
MXB_8: U9.4 (X7); also elsewhere on the board
MXC_1: U10.13 (X0); also elsewhere on the board
MXC_2: U10.14 (X1); also elsewhere on the board
MXC_3: U10.15 (X2); also elsewhere on the board
MXC_4: U10.12 (X3); also elsewhere on the board
MXC_5: U10.1 (X4); also elsewhere on the board
MXC_6: U10.5 (X5); also elsewhere on the board
MXC_7: U10.2 (X6); also elsewhere on the board
MXC_8: U10.4 (X7); also elsewhere on the board
MXE_1: U12.13 (X0); also elsewhere on the board
MXE_2: U12.14 (X1); also elsewhere on the board
MXE_3: U12.15 (X2); also elsewhere on the board
MXE_4: U12.12 (X3); also elsewhere on the board
MXE_5: U12.1 (X4); also elsewhere on the board
MXE_6: U12.5 (X5); also elsewhere on the board
MXE_7: U12.2 (X6); also elsewhere on the board
MXE_8: U12.4 (X7); also elsewhere on the board
NTC_1: U11.13 (X0); also elsewhere on the board
NTC_2: U11.14 (X1); also elsewhere on the board
NTC_3: U11.15 (X2); also elsewhere on the board
NTC_4: U11.12 (X3); also elsewhere on the board
NTC_5: U11.1 (X4); also elsewhere on the board
NTC_6: U11.5 (X5); also elsewhere on the board
NTC_7: U11.2 (X6); also elsewhere on the board
NTC_8: U11.4 (X7); also elsewhere on the board
SCL5: U7.10 (SCL); also elsewhere on the board
SDA5: U7.9 (SDA); also elsewhere on the board

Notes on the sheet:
ADS1115 + CD4051 measurement multiplexers

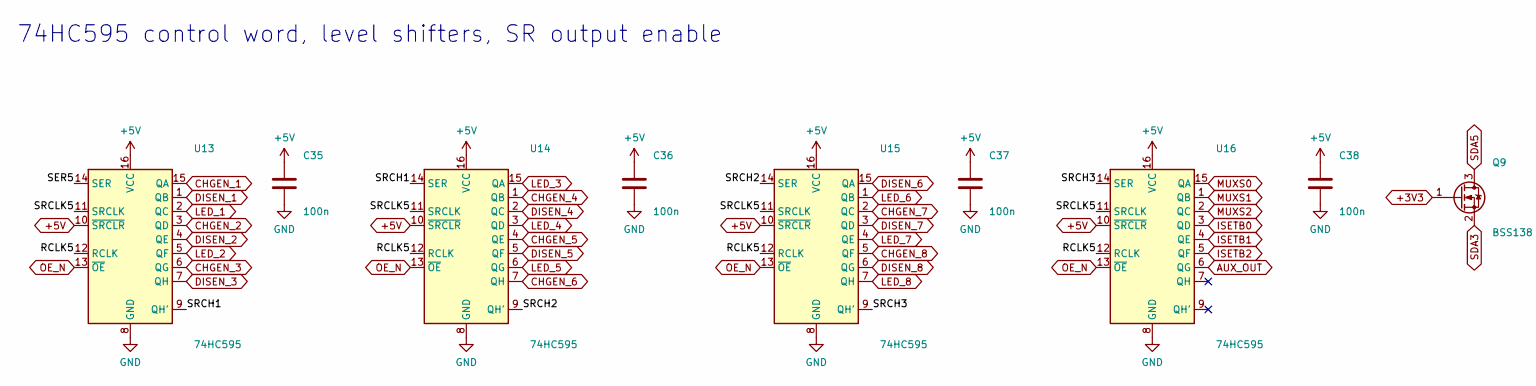
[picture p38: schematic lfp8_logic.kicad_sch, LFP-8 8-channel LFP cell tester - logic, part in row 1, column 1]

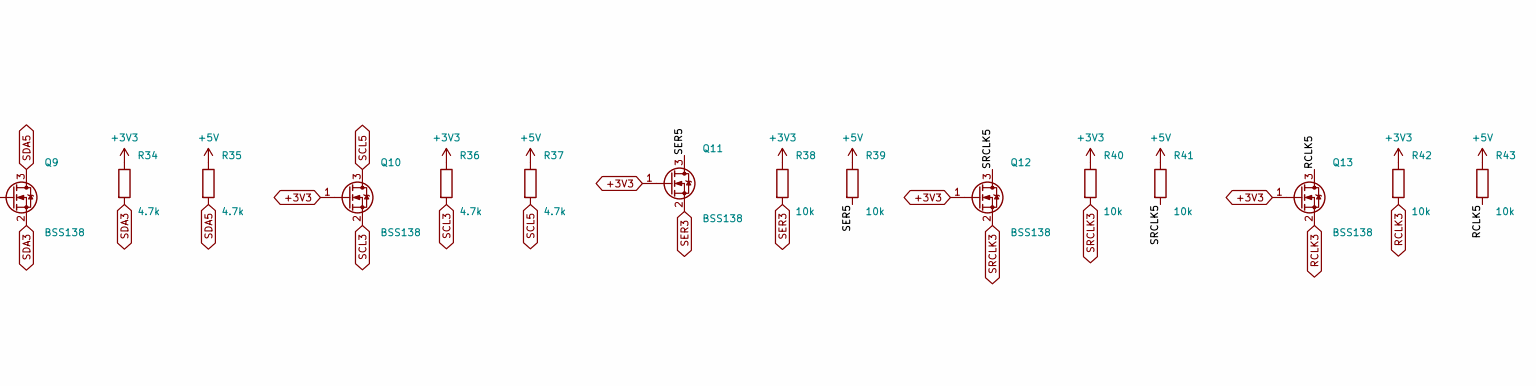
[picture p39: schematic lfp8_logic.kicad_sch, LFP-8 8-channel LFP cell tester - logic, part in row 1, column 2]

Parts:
C35, C36, C37, C38: 100n; C_0603_1608Metric; LCSC C14663
Q9, Q10, Q11, Q12, Q13: BSS138; SOT-23; MPN BSS138; LCSC C7420339
R34, R35, R36, R37: 4.7k; R_0603_1608Metric; LCSC C23162
R38, R39, R40, R41, R42, R43: 10k; R_0603_1608Metric; LCSC C25804
U13, U14, U15, U16: 74HC595; SOIC-16_3.9x9.9mm_P1.27mm; MPN 74HC595D,118; LCSC C5947

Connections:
+3V3: Q9.1 (G), Q10.1 (G), Q11.1 (G), Q12.1 (G), Q13.1 (G), R34.1, R36.1, R38.1, R40.1, R42.1; also elsewhere on the board
+5V: C35.1, C36.1, C37.1, C38.1, R35.1, R37.1, R39.1, R41.1, R43.1, U13.10 (~SRCLR), U13.16 (VCC), U14.10 (~SRCLR), U14.16 (VCC), U15.10 (~SRCLR), U15.16 (VCC), U16.10 (~SRCLR), U16.16 (VCC); also elsewhere on the board
/logic/RCLK5: Q13.3 (D), R43.2, U13.12 (RCLK), U14.12 (RCLK), U15.12 (RCLK), U16.12 (RCLK)
/logic/SER5: Q11.3 (D), R39.2, U13.14 (SER)
/logic/SRCH1: U13.9 (QH'), U14.14 (SER)
/logic/SRCH2: U14.9 (QH'), U15.14 (SER)
/logic/SRCH3: U15.9 (QH'), U16.14 (SER)
/logic/SRCLK5: Q12.3 (D), R41.2, U13.11 (SRCLK), U14.11 (SRCLK), U15.11 (SRCLK), U16.11 (SRCLK)
AUX_OUT: U16.6 (QG); also elsewhere on the board
CHGEN_1: U13.15 (QA); also elsewhere on the board
CHGEN_2: U13.3 (QD); also elsewhere on the board
CHGEN_3: U13.6 (QG); also elsewhere on the board
CHGEN_4: U14.1 (QB); also elsewhere on the board
CHGEN_5: U14.4 (QE); also elsewhere on the board
CHGEN_6: U14.7 (QH); also elsewhere on the board
CHGEN_7: U15.2 (QC); also elsewhere on the board
CHGEN_8: U15.5 (QF); also elsewhere on the board
DISEN_1: U13.1 (QB); also elsewhere on the board
DISEN_2: U13.4 (QE); also elsewhere on the board
DISEN_3: U13.7 (QH); also elsewhere on the board
DISEN_4: U14.2 (QC); also elsewhere on the board
DISEN_5: U14.5 (QF); also elsewhere on the board
DISEN_6: U15.15 (QA); also elsewhere on the board
DISEN_7: U15.3 (QD); also elsewhere on the board
DISEN_8: U15.6 (QG); also elsewhere on the board
GND: C35.2, C36.2, C37.2, C38.2, U13.8 (GND), U14.8 (GND), U15.8 (GND), U16.8 (GND); also elsewhere on the board
ISETB0: U16.3 (QD); also elsewhere on the board
ISETB1: U16.4 (QE); also elsewhere on the board
ISETB2: U16.5 (QF); also elsewhere on the board
LED_1: U13.2 (QC); also elsewhere on the board
LED_2: U13.5 (QF); also elsewhere on the board
LED_3: U14.15 (QA); also elsewhere on the board
LED_4: U14.3 (QD); also elsewhere on the board
LED_5: U14.6 (QG); also elsewhere on the board
LED_6: U15.1 (QB); also elsewhere on the board
LED_7: U15.4 (QE); also elsewhere on the board
LED_8: U15.7 (QH); also elsewhere on the board
MUXS0: U16.15 (QA); also elsewhere on the board
MUXS1: U16.1 (QB); also elsewhere on the board
MUXS2: U16.2 (QC); also elsewhere on the board
OE_N: U13.13 (~OE), U14.13 (~OE), U15.13 (~OE), U16.13 (~OE); also elsewhere on the board
RCLK3: Q13.2 (S), R42.2; also elsewhere on the board
SCL3: Q10.2 (S), R36.2; also elsewhere on the board
SCL5: Q10.3 (D), R37.2; also elsewhere on the board
SDA3: Q9.2 (S), R34.2; also elsewhere on the board
SDA5: Q9.3 (D), R35.2; also elsewhere on the board
SER3: Q11.2 (S), R38.2; also elsewhere on the board
SRCLK3: Q12.2 (S), R40.2; also elsewhere on the board

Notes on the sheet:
74HC595 control word, level shifters, SR output enable

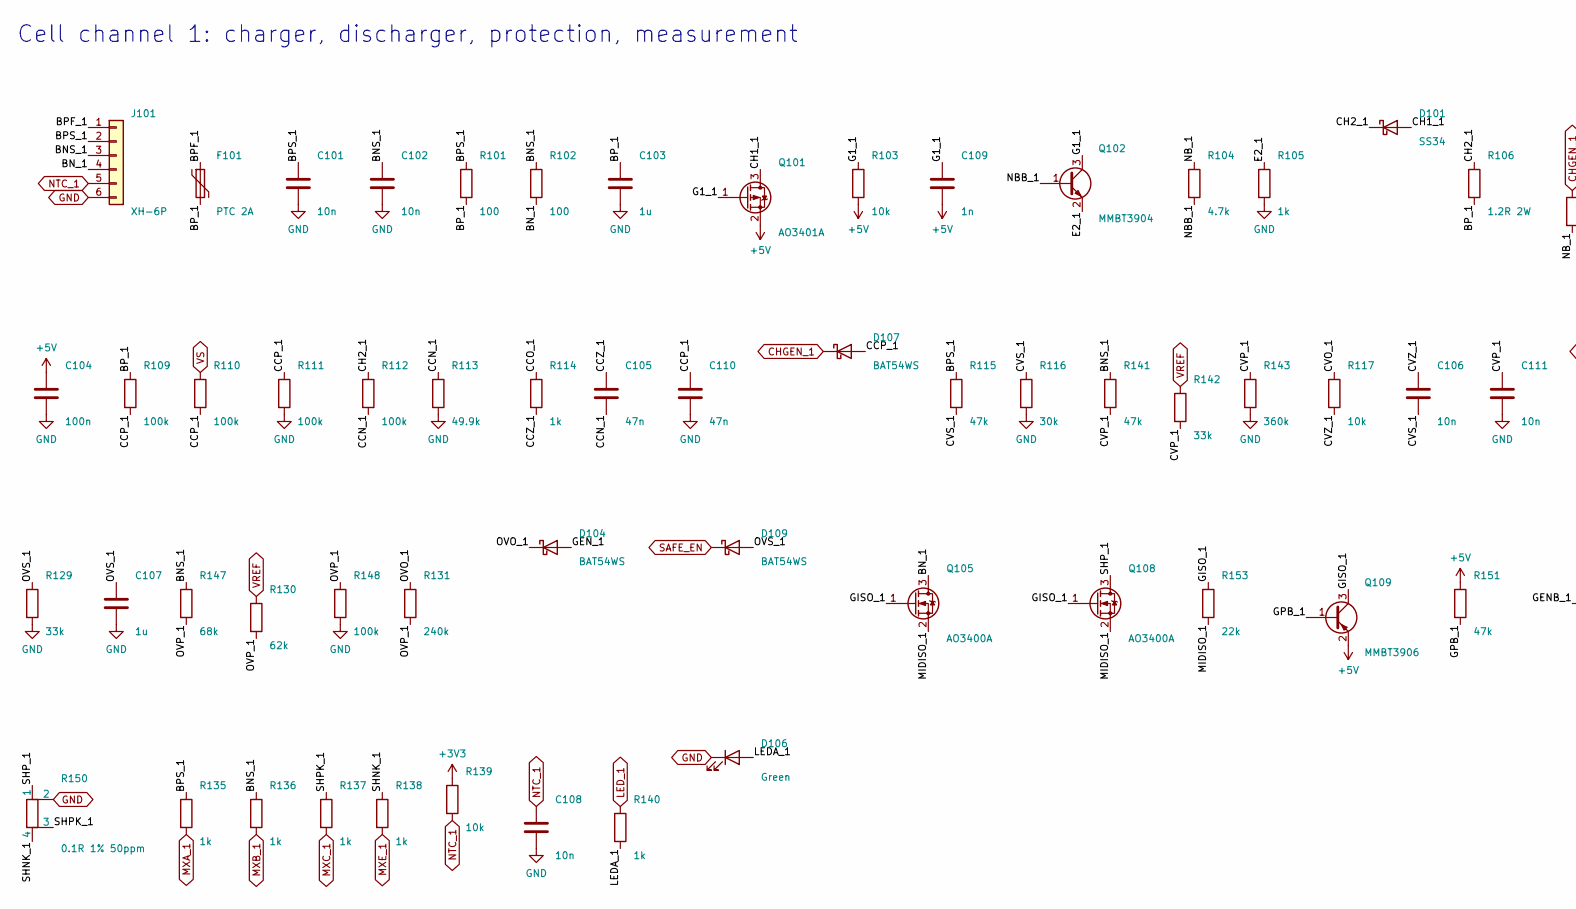
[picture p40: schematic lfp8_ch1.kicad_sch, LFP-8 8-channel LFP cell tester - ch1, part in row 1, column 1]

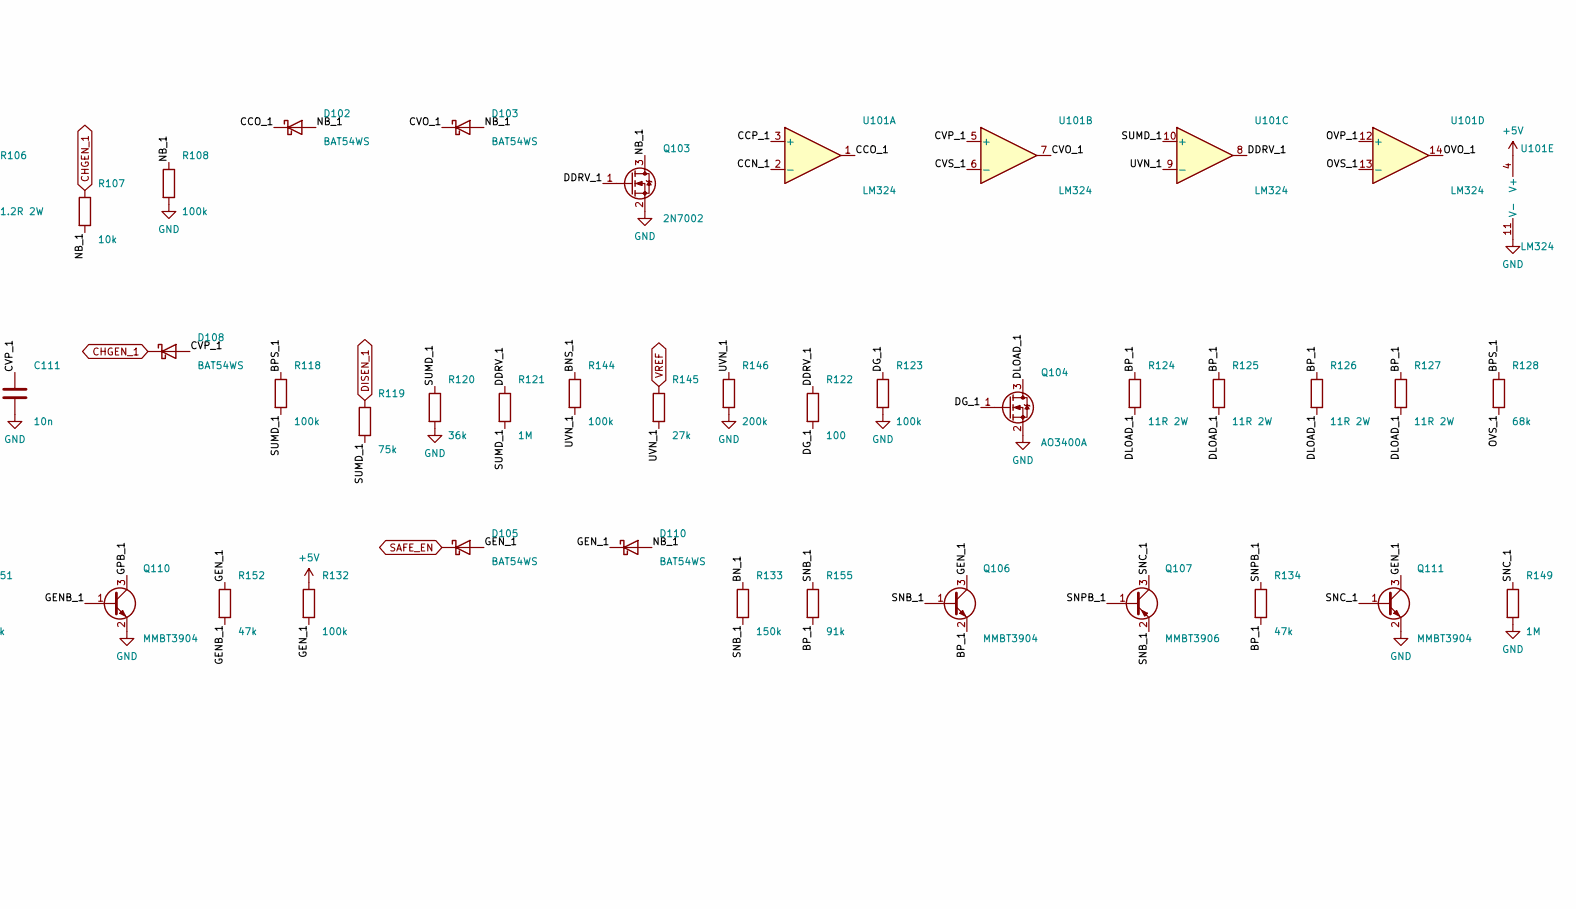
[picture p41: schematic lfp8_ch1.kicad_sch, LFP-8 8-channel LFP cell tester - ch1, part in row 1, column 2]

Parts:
C101, C102, C106, C108, C111: 10n; C_0603_1608Metric; LCSC C57112
C103, C107: 1u; C_0603_1608Metric; LCSC C15849
C104: 100n; C_0603_1608Metric; LCSC C14663
C105, C110: 47n; C_0603_1608Metric; LCSC C1622
C109: 1n; C_0603_1608Metric; LCSC C1588
D101: SS34; D_SMA; MPN SS34; LCSC C8678
D102, D103, D104, D105, D107, D108, D109, D110: BAT54WS; D_SOD-323; MPN BAT54WS; LCSC C7502694
D106: Green; LED_0805_2012Metric; MPN 0805 green; LCSC C2297
F101: PTC 2A; Fuse_1812_4532Metric; MPN 1812L200/30GR; LCSC C18198342
J101: XH-6P; JST_XH_B6B-XH-A_1x06_P2.50mm_Vertical; MPN JST B6B-XH-A (or clone); JLC Hand
Q101: AO3401A; SOT-23; MPN AO3401A; LCSC C15127
Q102, Q106, Q110, Q111: MMBT3904; SOT-23; MPN MMBT3904; LCSC C20526
Q103: 2N7002; SOT-23; MPN 2N7002; LCSC C8545
Q104, Q105, Q108: AO3400A; SOT-23; MPN AO3400A; LCSC C20917
Q107, Q109: MMBT3906; SOT-23; MPN MMBT3906; LCSC C7420354
R101, R102, R122: 100; R_0603_1608Metric; LCSC C22775
R103, R107, R117, R139: 10k; R_0603_1608Metric; LCSC C25804
R104: 4.7k; R_0603_1608Metric; LCSC C23162
R105, R114, R135, R136, R137, R138, R140: 1k; R_0603_1608Metric; LCSC C21190
R106: 1.2R 2W; R_2512_6332Metric; MPN FRP2512F1R20TS; LCSC C7468247
R108, R109, R110, R111, R112, R118, R123, R132, R144, R148: 100k; R_0603_1608Metric; LCSC C25803
R113: 49.9k; R_0603_1608Metric; LCSC C23184
R115, R134, R141, R151, R152: 47k; R_0603_1608Metric; LCSC C25819
R116: 30k; R_0603_1608Metric; LCSC C22984
R119: 75k; R_0603_1608Metric; LCSC C23242
R120: 36k; R_0603_1608Metric; LCSC C23147
R121, R149: 1M; R_0603_1608Metric; LCSC C22935
R124, R125, R126, R127: 11R 2W; R_2512_6332Metric; MPN FRP2512F11R0TS; LCSC C7468192
R128, R147: 68k; R_0603_1608Metric; LCSC C23231
R129, R142: 33k; R_0603_1608Metric; LCSC C4216
R130: 62k; R_0603_1608Metric; LCSC C23221
R131: 240k; R_0603_1608Metric; LCSC C4197
R133: 150k; R_0603_1608Metric; LCSC C22807
R143: 360k; R_0603_1608Metric; LCSC C23146
R145: 27k; R_0603_1608Metric; LCSC C22967
R146: 200k; R_0603_1608Metric; LCSC C25811
R150: 0.1R 1% 50ppm; R_2512_Kelvin; MPN FRM252WFR100TN; LCSC C7420048
R153: 22k; R_0603_1608Metric; LCSC C31850
R155: 91k; R_0603_1608Metric; LCSC C23265
U101: LM324; SOIC-14_3.9x8.7mm_P1.27mm; MPN LM324DT; LCSC C71035

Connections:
+3V3: R139.1; also elsewhere on the board
+5V: C104.1, C109.2, Q101.2 (S), Q109.2 (E), R103.2, R132.1, R151.1, U101.4 (V+); also elsewhere on the board
/ch1/BNS_1: C102.1, J101.3, R102.1, R136.1, R141.1, R144.1, R147.1
/ch1/BN_1: J101.4, Q105.3 (D), R102.2, R133.1
/ch1/BPF_1: F101.1, J101.1
/ch1/BPS_1: C101.1, J101.2, R101.1, R115.1, R118.1, R128.1, R135.1
/ch1/BP_1: C103.1, F101.2, Q106.2 (E), R101.2, R106.2, R109.1, R124.1, R125.1, R126.1, R127.1, R134.2, R155.2
/ch1/CCN_1: C105.2, R112.2, R113.1, U101.2 (-)
/ch1/CCO_1: D102.1 (K), R114.1, U101.1
/ch1/CCP_1: C110.1, D107.2 (A), R109.2, R110.2, R111.1, U101.3 (+)
/ch1/CCZ_1: C105.1, R114.2
/ch1/CH1_1: D101.2 (A), Q101.3 (D)
/ch1/CH2_1: D101.1 (K), R106.1, R112.1
/ch1/CVO_1: D103.1 (K), R117.1, U101.7
/ch1/CVP_1: C111.1, D108.2 (A), R141.2, R142.2, R143.1, U101.5 (+)
/ch1/CVS_1: C106.2, R115.2, R116.1, U101.6 (-)
/ch1/CVZ_1: C106.1, R117.2
/ch1/DDRV_1: Q103.1 (G), R121.1, R122.1, U101.8
/ch1/DG_1: Q104.1 (G), R122.2, R123.1
/ch1/DLOAD_1: Q104.3 (D), R124.2, R125.2, R126.2, R127.2
/ch1/E2_1: Q102.2 (E), R105.1
/ch1/G1_1: C109.1, Q101.1 (G), Q102.3 (C), R103.1
/ch1/GENB_1: Q110.1 (B), R152.2
/ch1/GEN_1: D104.2 (A), D105.2 (A), D110.1 (K), Q106.3 (C), Q111.3 (C), R132.2, R152.1
/ch1/GISO_1: Q105.1 (G), Q108.1 (G), Q109.3 (C), R153.1
/ch1/GPB_1: Q109.1 (B), Q110.3 (C), R151.2
/ch1/LEDA_1: D106.2 (A), R140.2
/ch1/MIDISO_1: Q105.2 (S), Q108.2 (S), R153.2
/ch1/NBB_1: Q102.1 (B), R104.2
/ch1/NB_1: D102.2 (A), D103.2 (A), D110.2 (A), Q103.3 (D), R104.1, R107.2, R108.1
/ch1/OVO_1: D104.1 (K), R131.1, U101.14
/ch1/OVP_1: R130.2, R131.2, R147.2, R148.1, U101.12 (+)
/ch1/OVS_1: C107.1, D109.2 (A), R128.2, R129.1, U101.13 (-)
/ch1/SHNK_1: R138.1, R150.4
/ch1/SHPK_1: R137.1, R150.3
/ch1/SHP_1: Q108.3 (D), R150.1
/ch1/SNB_1: Q106.1 (B), Q107.2 (E), R133.2, R155.1
/ch1/SNC_1: Q107.3 (C), Q111.1 (B), R149.1
/ch1/SNPB_1: Q107.1 (B), R134.1
/ch1/SUMD_1: R118.2, R119.2, R120.1, R121.2, U101.10 (+)
/ch1/UVN_1: R144.2, R145.2, R146.1, U101.9 (-)
CHGEN_1: D107.1 (K), D108.1 (K), R107.1; also elsewhere on the board
DISEN_1: R119.1; also elsewhere on the board
GND: C101.2, C102.2, C103.2, C104.2, C107.2, C108.2, C110.2, C111.2, D106.1 (K), J101.6, Q103.2 (S), Q104.2 (S), Q110.2 (E), Q111.2 (E), R105.2, R108.2, R111.2, R113.2, R116.2, R120.2, R123.2, R129.2, R143.2, R146.2, R148.2, R149.2, R150.2, U101.11 (V-); also elsewhere on the board
LED_1: R140.1; also elsewhere on the board
MXA_1: R135.2; also elsewhere on the board
MXB_1: R136.2; also elsewhere on the board
MXC_1: R137.2; also elsewhere on the board
MXE_1: R138.2; also elsewhere on the board
NTC_1: C108.1, J101.5, R139.2; also elsewhere on the board
SAFE_EN: D105.1 (K), D109.1 (K); also elsewhere on the board
VREF: R130.1, R142.1, R145.1; also elsewhere on the board
VS: R110.1; also elsewhere on the board

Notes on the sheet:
Cell channel 1: charger, discharger, protection, measurement

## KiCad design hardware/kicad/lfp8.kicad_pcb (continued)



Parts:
C201, C202, C206, C208, C211: 10n; C_0603_1608Metric; LCSC C57112
C203, C207: 1u; C_0603_1608Metric; LCSC C15849
C204: 100n; C_0603_1608Metric; LCSC C14663
C205, C210: 47n; C_0603_1608Metric; LCSC C1622
C209: 1n; C_0603_1608Metric; LCSC C1588
D201: SS34; D_SMA; MPN SS34; LCSC C8678
D202, D203, D204, D205, D207, D208, D209, D210: BAT54WS; D_SOD-323; MPN BAT54WS; LCSC C7502694
D206: Green; LED_0805_2012Metric; MPN 0805 green; LCSC C2297
F201: PTC 2A; Fuse_1812_4532Metric; MPN 1812L200/30GR; LCSC C18198342
J201: XH-6P; JST_XH_B6B-XH-A_1x06_P2.50mm_Vertical; MPN JST B6B-XH-A (or clone); JLC Hand
Q201: AO3401A; SOT-23; MPN AO3401A; LCSC C15127
Q202, Q206, Q210, Q211: MMBT3904; SOT-23; MPN MMBT3904; LCSC C20526
Q203: 2N7002; SOT-23; MPN 2N7002; LCSC C8545
Q204, Q205, Q208: AO3400A; SOT-23; MPN AO3400A; LCSC C20917
Q207, Q209: MMBT3906; SOT-23; MPN MMBT3906; LCSC C7420354
R201, R202, R222: 100; R_0603_1608Metric; LCSC C22775
R203, R207, R217, R239: 10k; R_0603_1608Metric; LCSC C25804
R204: 4.7k; R_0603_1608Metric; LCSC C23162
R205, R214, R235, R236, R237, R238, R240: 1k; R_0603_1608Metric; LCSC C21190
R206: 1.2R 2W; R_2512_6332Metric; MPN FRP2512F1R20TS; LCSC C7468247
R208, R209, R210, R211, R212, R218, R223, R232, R244, R248: 100k; R_0603_1608Metric; LCSC C25803
R213: 49.9k; R_0603_1608Metric; LCSC C23184
R215, R234, R241, R251, R252: 47k; R_0603_1608Metric; LCSC C25819
R216: 30k; R_0603_1608Metric; LCSC C22984
R219: 75k; R_0603_1608Metric; LCSC C23242
R220: 36k; R_0603_1608Metric; LCSC C23147
R221, R249: 1M; R_0603_1608Metric; LCSC C22935
R224, R225, R226, R227: 11R 2W; R_2512_6332Metric; MPN FRP2512F11R0TS; LCSC C7468192
R228, R247: 68k; R_0603_1608Metric; LCSC C23231
R229, R242: 33k; R_0603_1608Metric; LCSC C4216
R230: 62k; R_0603_1608Metric; LCSC C23221
R231: 240k; R_0603_1608Metric; LCSC C4197
R233: 150k; R_0603_1608Metric; LCSC C22807
R243: 360k; R_0603_1608Metric; LCSC C23146
R245: 27k; R_0603_1608Metric; LCSC C22967
R246: 200k; R_0603_1608Metric; LCSC C25811
R250: 0.1R 1% 50ppm; R_2512_Kelvin; MPN FRM252WFR100TN; LCSC C7420048
R253: 22k; R_0603_1608Metric; LCSC C31850
R255: 91k; R_0603_1608Metric; LCSC C23265
U201: LM324; SOIC-14_3.9x8.7mm_P1.27mm; MPN LM324DT; LCSC C71035

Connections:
+3V3: R239.1; also elsewhere on the board
+5V: C204.1, C209.2, Q201.2 (S), Q209.2 (E), R203.2, R232.1, R251.1, U201.4 (V+); also elsewhere on the board
/ch2/BNS_2: C202.1, J201.3, R202.1, R236.1, R241.1, R244.1, R247.1
/ch2/BN_2: J201.4, Q205.3 (D), R202.2, R233.1
/ch2/BPF_2: F201.1, J201.1
/ch2/BPS_2: C201.1, J201.2, R201.1, R215.1, R218.1, R228.1, R235.1
/ch2/BP_2: C203.1, F201.2, Q206.2 (E), R201.2, R206.2, R209.1, R224.1, R225.1, R226.1, R227.1, R234.2, R255.2
/ch2/CCN_2: C205.2, R212.2, R213.1, U201.2 (-)
/ch2/CCO_2: D202.1 (K), R214.1, U201.1
/ch2/CCP_2: C210.1, D207.2 (A), R209.2, R210.2, R211.1, U201.3 (+)
/ch2/CCZ_2: C205.1, R214.2
/ch2/CH1_2: D201.2 (A), Q201.3 (D)
/ch2/CH2_2: D201.1 (K), R206.1, R212.1
/ch2/CVO_2: D203.1 (K), R217.1, U201.7
/ch2/CVP_2: C211.1, D208.2 (A), R241.2, R242.2, R243.1, U201.5 (+)
/ch2/CVS_2: C206.2, R215.2, R216.1, U201.6 (-)
/ch2/CVZ_2: C206.1, R217.2
/ch2/DDRV_2: Q203.1 (G), R221.1, R222.1, U201.8
/ch2/DG_2: Q204.1 (G), R222.2, R223.1
/ch2/DLOAD_2: Q204.3 (D), R224.2, R225.2, R226.2, R227.2
/ch2/E2_2: Q202.2 (E), R205.1
/ch2/G1_2: C209.1, Q201.1 (G), Q202.3 (C), R203.1
/ch2/GENB_2: Q210.1 (B), R252.2
/ch2/GEN_2: D204.2 (A), D205.2 (A), D210.1 (K), Q206.3 (C), Q211.3 (C), R232.2, R252.1
/ch2/GISO_2: Q205.1 (G), Q208.1 (G), Q209.3 (C), R253.1
/ch2/GPB_2: Q209.1 (B), Q210.3 (C), R251.2
/ch2/LEDA_2: D206.2 (A), R240.2
/ch2/MIDISO_2: Q205.2 (S), Q208.2 (S), R253.2
/ch2/NBB_2: Q202.1 (B), R204.2
/ch2/NB_2: D202.2 (A), D203.2 (A), D210.2 (A), Q203.3 (D), R204.1, R207.2, R208.1
/ch2/OVO_2: D204.1 (K), R231.1, U201.14
/ch2/OVP_2: R230.2, R231.2, R247.2, R248.1, U201.12 (+)
/ch2/OVS_2: C207.1, D209.2 (A), R228.2, R229.1, U201.13 (-)
/ch2/SHNK_2: R238.1, R250.4
/ch2/SHPK_2: R237.1, R250.3
/ch2/SHP_2: Q208.3 (D), R250.1
/ch2/SNB_2: Q206.1 (B), Q207.2 (E), R233.2, R255.1
/ch2/SNC_2: Q207.3 (C), Q211.1 (B), R249.1
/ch2/SNPB_2: Q207.1 (B), R234.1
/ch2/SUMD_2: R218.2, R219.2, R220.1, R221.2, U201.10 (+)
/ch2/UVN_2: R244.2, R245.2, R246.1, U201.9 (-)
CHGEN_2: D207.1 (K), D208.1 (K), R207.1; also elsewhere on the board
DISEN_2: R219.1; also elsewhere on the board
GND: C201.2, C202.2, C203.2, C204.2, C207.2, C208.2, C210.2, C211.2, D206.1 (K), J201.6, Q203.2 (S), Q204.2 (S), Q210.2 (E), Q211.2 (E), R205.2, R208.2, R211.2, R213.2, R216.2, R220.2, R223.2, R229.2, R243.2, R246.2, R248.2, R249.2, R250.2, U201.11 (V-); also elsewhere on the board
LED_2: R240.1; also elsewhere on the board
MXA_2: R235.2; also elsewhere on the board
MXB_2: R236.2; also elsewhere on the board
MXC_2: R237.2; also elsewhere on the board
MXE_2: R238.2; also elsewhere on the board
NTC_2: C208.1, J201.5, R239.2; also elsewhere on the board
SAFE_EN: D205.1 (K), D209.1 (K); also elsewhere on the board
VREF: R230.1, R242.1, R245.1; also elsewhere on the board
VS: R210.1; also elsewhere on the board

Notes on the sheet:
Cell channel 2: charger, discharger, protection, measurement

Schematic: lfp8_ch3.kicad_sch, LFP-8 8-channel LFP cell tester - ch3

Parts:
C301, C302, C306, C308, C311: 10n; C_0603_1608Metric; LCSC C57112
C303, C307: 1u; C_0603_1608Metric; LCSC C15849
C304: 100n; C_0603_1608Metric; LCSC C14663
C305, C310: 47n; C_0603_1608Metric; LCSC C1622
C309: 1n; C_0603_1608Metric; LCSC C1588
D301: SS34; D_SMA; MPN SS34; LCSC C8678
D302, D303, D304, D305, D307, D308, D309, D310: BAT54WS; D_SOD-323; MPN BAT54WS; LCSC C7502694
D306: Green; LED_0805_2012Metric; MPN 0805 green; LCSC C2297
F301: PTC 2A; Fuse_1812_4532Metric; MPN 1812L200/30GR; LCSC C18198342
J301: XH-6P; JST_XH_B6B-XH-A_1x06_P2.50mm_Vertical; MPN JST B6B-XH-A (or clone); JLC Hand
Q301: AO3401A; SOT-23; MPN AO3401A; LCSC C15127
Q302, Q306, Q310, Q311: MMBT3904; SOT-23; MPN MMBT3904; LCSC C20526
Q303: 2N7002; SOT-23; MPN 2N7002; LCSC C8545
Q304, Q305, Q308: AO3400A; SOT-23; MPN AO3400A; LCSC C20917
Q307, Q309: MMBT3906; SOT-23; MPN MMBT3906; LCSC C7420354
R301, R302, R322: 100; R_0603_1608Metric; LCSC C22775
R303, R307, R317, R339: 10k; R_0603_1608Metric; LCSC C25804
R304: 4.7k; R_0603_1608Metric; LCSC C23162
R305, R314, R335, R336, R337, R338, R340: 1k; R_0603_1608Metric; LCSC C21190
R306: 1.2R 2W; R_2512_6332Metric; MPN FRP2512F1R20TS; LCSC C7468247
R308, R309, R310, R311, R312, R318, R323, R332, R344, R348: 100k; R_0603_1608Metric; LCSC C25803
R313: 49.9k; R_0603_1608Metric; LCSC C23184
R315, R334, R341, R351, R352: 47k; R_0603_1608Metric; LCSC C25819
R316: 30k; R_0603_1608Metric; LCSC C22984
R319: 75k; R_0603_1608Metric; LCSC C23242
R320: 36k; R_0603_1608Metric; LCSC C23147
R321, R349: 1M; R_0603_1608Metric; LCSC C22935
R324, R325, R326, R327: 11R 2W; R_2512_6332Metric; MPN FRP2512F11R0TS; LCSC C7468192
R328, R347: 68k; R_0603_1608Metric; LCSC C23231
R329, R342: 33k; R_0603_1608Metric; LCSC C4216
R330: 62k; R_0603_1608Metric; LCSC C23221
R331: 240k; R_0603_1608Metric; LCSC C4197
R333: 150k; R_0603_1608Metric; LCSC C22807
R343: 360k; R_0603_1608Metric; LCSC C23146
R345: 27k; R_0603_1608Metric; LCSC C22967
R346: 200k; R_0603_1608Metric; LCSC C25811
R350: 0.1R 1% 50ppm; R_2512_Kelvin; MPN FRM252WFR100TN; LCSC C7420048
R353: 22k; R_0603_1608Metric; LCSC C31850
R355: 91k; R_0603_1608Metric; LCSC C23265
U301: LM324; SOIC-14_3.9x8.7mm_P1.27mm; MPN LM324DT; LCSC C71035

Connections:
+3V3: R339.1; also elsewhere on the board
+5V: C304.1, C309.2, Q301.2 (S), Q309.2 (E), R303.2, R332.1, R351.1, U301.4 (V+); also elsewhere on the board
/ch3/BNS_3: C302.1, J301.3, R302.1, R336.1, R341.1, R344.1, R347.1
/ch3/BN_3: J301.4, Q305.3 (D), R302.2, R333.1
/ch3/BPF_3: F301.1, J301.1
/ch3/BPS_3: C301.1, J301.2, R301.1, R315.1, R318.1, R328.1, R335.1
/ch3/BP_3: C303.1, F301.2, Q306.2 (E), R301.2, R306.2, R309.1, R324.1, R325.1, R326.1, R327.1, R334.2, R355.2
/ch3/CCN_3: C305.2, R312.2, R313.1, U301.2 (-)
/ch3/CCO_3: D302.1 (K), R314.1, U301.1
/ch3/CCP_3: C310.1, D307.2 (A), R309.2, R310.2, R311.1, U301.3 (+)
/ch3/CCZ_3: C305.1, R314.2
/ch3/CH1_3: D301.2 (A), Q301.3 (D)
/ch3/CH2_3: D301.1 (K), R306.1, R312.1
/ch3/CVO_3: D303.1 (K), R317.1, U301.7
/ch3/CVP_3: C311.1, D308.2 (A), R341.2, R342.2, R343.1, U301.5 (+)
/ch3/CVS_3: C306.2, R315.2, R316.1, U301.6 (-)
/ch3/CVZ_3: C306.1, R317.2
/ch3/DDRV_3: Q303.1 (G), R321.1, R322.1, U301.8
/ch3/DG_3: Q304.1 (G), R322.2, R323.1
/ch3/DLOAD_3: Q304.3 (D), R324.2, R325.2, R326.2, R327.2
/ch3/E2_3: Q302.2 (E), R305.1
/ch3/G1_3: C309.1, Q301.1 (G), Q302.3 (C), R303.1
/ch3/GENB_3: Q310.1 (B), R352.2
/ch3/GEN_3: D304.2 (A), D305.2 (A), D310.1 (K), Q306.3 (C), Q311.3 (C), R332.2, R352.1
/ch3/GISO_3: Q305.1 (G), Q308.1 (G), Q309.3 (C), R353.1
/ch3/GPB_3: Q309.1 (B), Q310.3 (C), R351.2
/ch3/LEDA_3: D306.2 (A), R340.2
/ch3/MIDISO_3: Q305.2 (S), Q308.2 (S), R353.2
/ch3/NBB_3: Q302.1 (B), R304.2
/ch3/NB_3: D302.2 (A), D303.2 (A), D310.2 (A), Q303.3 (D), R304.1, R307.2, R308.1
/ch3/OVO_3: D304.1 (K), R331.1, U301.14
/ch3/OVP_3: R330.2, R331.2, R347.2, R348.1, U301.12 (+)
/ch3/OVS_3: C307.1, D309.2 (A), R328.2, R329.1, U301.13 (-)
/ch3/SHNK_3: R338.1, R350.4
/ch3/SHPK_3: R337.1, R350.3
/ch3/SHP_3: Q308.3 (D), R350.1
/ch3/SNB_3: Q306.1 (B), Q307.2 (E), R333.2, R355.1
/ch3/SNC_3: Q307.3 (C), Q311.1 (B), R349.1
/ch3/SNPB_3: Q307.1 (B), R334.1
/ch3/SUMD_3: R318.2, R319.2, R320.1, R321.2, U301.10 (+)
/ch3/UVN_3: R344.2, R345.2, R346.1, U301.9 (-)
CHGEN_3: D307.1 (K), D308.1 (K), R307.1; also elsewhere on the board
DISEN_3: R319.1; also elsewhere on the board
GND: C301.2, C302.2, C303.2, C304.2, C307.2, C308.2, C310.2, C311.2, D306.1 (K), J301.6, Q303.2 (S), Q304.2 (S), Q310.2 (E), Q311.2 (E), R305.2, R308.2, R311.2, R313.2, R316.2, R320.2, R323.2, R329.2, R343.2, R346.2, R348.2, R349.2, R350.2, U301.11 (V-); also elsewhere on the board
LED_3: R340.1; also elsewhere on the board
MXA_3: R335.2; also elsewhere on the board
MXB_3: R336.2; also elsewhere on the board
MXC_3: R337.2; also elsewhere on the board
MXE_3: R338.2; also elsewhere on the board
NTC_3: C308.1, J301.5, R339.2; also elsewhere on the board
SAFE_EN: D305.1 (K), D309.1 (K); also elsewhere on the board
VREF: R330.1, R342.1, R345.1; also elsewhere on the board
VS: R310.1; also elsewhere on the board

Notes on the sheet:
Cell channel 3: charger, discharger, protection, measurement

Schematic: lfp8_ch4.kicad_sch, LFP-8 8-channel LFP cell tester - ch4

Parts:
C401, C402, C406, C408, C411: 10n; C_0603_1608Metric; LCSC C57112
C403, C407: 1u; C_0603_1608Metric; LCSC C15849
C404: 100n; C_0603_1608Metric; LCSC C14663
C405, C410: 47n; C_0603_1608Metric; LCSC C1622
C409: 1n; C_0603_1608Metric; LCSC C1588
D401: SS34; D_SMA; MPN SS34; LCSC C8678
D402, D403, D404, D405, D407, D408, D409, D410: BAT54WS; D_SOD-323; MPN BAT54WS; LCSC C7502694
D406: Green; LED_0805_2012Metric; MPN 0805 green; LCSC C2297
F401: PTC 2A; Fuse_1812_4532Metric; MPN 1812L200/30GR; LCSC C18198342
J401: XH-6P; JST_XH_B6B-XH-A_1x06_P2.50mm_Vertical; MPN JST B6B-XH-A (or clone); JLC Hand
Q401: AO3401A; SOT-23; MPN AO3401A; LCSC C15127
Q402, Q406, Q410, Q411: MMBT3904; SOT-23; MPN MMBT3904; LCSC C20526
Q403: 2N7002; SOT-23; MPN 2N7002; LCSC C8545
Q404, Q405, Q408: AO3400A; SOT-23; MPN AO3400A; LCSC C20917
Q407, Q409: MMBT3906; SOT-23; MPN MMBT3906; LCSC C7420354
R401, R402, R422: 100; R_0603_1608Metric; LCSC C22775
R403, R407, R417, R439: 10k; R_0603_1608Metric; LCSC C25804
R404: 4.7k; R_0603_1608Metric; LCSC C23162
R405, R414, R435, R436, R437, R438, R440: 1k; R_0603_1608Metric; LCSC C21190
R406: 1.2R 2W; R_2512_6332Metric; MPN FRP2512F1R20TS; LCSC C7468247
R408, R409, R410, R411, R412, R418, R423, R432, R444, R448: 100k; R_0603_1608Metric; LCSC C25803
R413: 49.9k; R_0603_1608Metric; LCSC C23184
R415, R434, R441, R451, R452: 47k; R_0603_1608Metric; LCSC C25819
R416: 30k; R_0603_1608Metric; LCSC C22984
R419: 75k; R_0603_1608Metric; LCSC C23242
R420: 36k; R_0603_1608Metric; LCSC C23147
R421, R449: 1M; R_0603_1608Metric; LCSC C22935
R424, R425, R426, R427: 11R 2W; R_2512_6332Metric; MPN FRP2512F11R0TS; LCSC C7468192
R428, R447: 68k; R_0603_1608Metric; LCSC C23231
R429, R442: 33k; R_0603_1608Metric; LCSC C4216
R430: 62k; R_0603_1608Metric; LCSC C23221
R431: 240k; R_0603_1608Metric; LCSC C4197
R433: 150k; R_0603_1608Metric; LCSC C22807
R443: 360k; R_0603_1608Metric; LCSC C23146
R445: 27k; R_0603_1608Metric; LCSC C22967
R446: 200k; R_0603_1608Metric; LCSC C25811
R450: 0.1R 1% 50ppm; R_2512_Kelvin; MPN FRM252WFR100TN; LCSC C7420048
R453: 22k; R_0603_1608Metric; LCSC C31850
R455: 91k; R_0603_1608Metric; LCSC C23265
U401: LM324; SOIC-14_3.9x8.7mm_P1.27mm; MPN LM324DT; LCSC C71035

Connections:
+3V3: R439.1; also elsewhere on the board
+5V: C404.1, C409.2, Q401.2 (S), Q409.2 (E), R403.2, R432.1, R451.1, U401.4 (V+); also elsewhere on the board
/ch4/BNS_4: C402.1, J401.3, R402.1, R436.1, R441.1, R444.1, R447.1
/ch4/BN_4: J401.4, Q405.3 (D), R402.2, R433.1
/ch4/BPF_4: F401.1, J401.1
/ch4/BPS_4: C401.1, J401.2, R401.1, R415.1, R418.1, R428.1, R435.1
/ch4/BP_4: C403.1, F401.2, Q406.2 (E), R401.2, R406.2, R409.1, R424.1, R425.1, R426.1, R427.1, R434.2, R455.2
/ch4/CCN_4: C405.2, R412.2, R413.1, U401.2 (-)
/ch4/CCO_4: D402.1 (K), R414.1, U401.1
/ch4/CCP_4: C410.1, D407.2 (A), R409.2, R410.2, R411.1, U401.3 (+)
/ch4/CCZ_4: C405.1, R414.2
/ch4/CH1_4: D401.2 (A), Q401.3 (D)
/ch4/CH2_4: D401.1 (K), R406.1, R412.1
/ch4/CVO_4: D403.1 (K), R417.1, U401.7
/ch4/CVP_4: C411.1, D408.2 (A), R441.2, R442.2, R443.1, U401.5 (+)
/ch4/CVS_4: C406.2, R415.2, R416.1, U401.6 (-)
/ch4/CVZ_4: C406.1, R417.2
/ch4/DDRV_4: Q403.1 (G), R421.1, R422.1, U401.8
/ch4/DG_4: Q404.1 (G), R422.2, R423.1
/ch4/DLOAD_4: Q404.3 (D), R424.2, R425.2, R426.2, R427.2
/ch4/E2_4: Q402.2 (E), R405.1
/ch4/G1_4: C409.1, Q401.1 (G), Q402.3 (C), R403.1
/ch4/GENB_4: Q410.1 (B), R452.2
/ch4/GEN_4: D404.2 (A), D405.2 (A), D410.1 (K), Q406.3 (C), Q411.3 (C), R432.2, R452.1
/ch4/GISO_4: Q405.1 (G), Q408.1 (G), Q409.3 (C), R453.1
/ch4/GPB_4: Q409.1 (B), Q410.3 (C), R451.2
/ch4/LEDA_4: D406.2 (A), R440.2
/ch4/MIDISO_4: Q405.2 (S), Q408.2 (S), R453.2
/ch4/NBB_4: Q402.1 (B), R404.2
/ch4/NB_4: D402.2 (A), D403.2 (A), D410.2 (A), Q403.3 (D), R404.1, R407.2, R408.1
/ch4/OVO_4: D404.1 (K), R431.1, U401.14
/ch4/OVP_4: R430.2, R431.2, R447.2, R448.1, U401.12 (+)
/ch4/OVS_4: C407.1, D409.2 (A), R428.2, R429.1, U401.13 (-)
/ch4/SHNK_4: R438.1, R450.4
/ch4/SHPK_4: R437.1, R450.3
/ch4/SHP_4: Q408.3 (D), R450.1
/ch4/SNB_4: Q406.1 (B), Q407.2 (E), R433.2, R455.1
/ch4/SNC_4: Q407.3 (C), Q411.1 (B), R449.1
/ch4/SNPB_4: Q407.1 (B), R434.1
/ch4/SUMD_4: R418.2, R419.2, R420.1, R421.2, U401.10 (+)
/ch4/UVN_4: R444.2, R445.2, R446.1, U401.9 (-)
CHGEN_4: D407.1 (K), D408.1 (K), R407.1; also elsewhere on the board
DISEN_4: R419.1; also elsewhere on the board
GND: C401.2, C402.2, C403.2, C404.2, C407.2, C408.2, C410.2, C411.2, D406.1 (K), J401.6, Q403.2 (S), Q404.2 (S), Q410.2 (E), Q411.2 (E), R405.2, R408.2, R411.2, R413.2, R416.2, R420.2, R423.2, R429.2, R443.2, R446.2, R448.2, R449.2, R450.2, U401.11 (V-); also elsewhere on the board
LED_4: R440.1; also elsewhere on the board
MXA_4: R435.2; also elsewhere on the board
MXB_4: R436.2; also elsewhere on the board
MXC_4: R437.2; also elsewhere on the board
MXE_4: R438.2; also elsewhere on the board
NTC_4: C408.1, J401.5, R439.2; also elsewhere on the board
SAFE_EN: D405.1 (K), D409.1 (K); also elsewhere on the board
VREF: R430.1, R442.1, R445.1; also elsewhere on the board
VS: R410.1; also elsewhere on the board

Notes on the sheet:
Cell channel 4: charger, discharger, protection, measurement

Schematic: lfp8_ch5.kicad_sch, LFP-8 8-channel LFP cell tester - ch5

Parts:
C501, C502, C506, C508, C511: 10n; C_0603_1608Metric; LCSC C57112
C503, C507: 1u; C_0603_1608Metric; LCSC C15849
C504: 100n; C_0603_1608Metric; LCSC C14663
C505, C510: 47n; C_0603_1608Metric; LCSC C1622
C509: 1n; C_0603_1608Metric; LCSC C1588
D501: SS34; D_SMA; MPN SS34; LCSC C8678
D502, D503, D504, D505, D507, D508, D509, D510: BAT54WS; D_SOD-323; MPN BAT54WS; LCSC C7502694
D506: Green; LED_0805_2012Metric; MPN 0805 green; LCSC C2297
F501: PTC 2A; Fuse_1812_4532Metric; MPN 1812L200/30GR; LCSC C18198342
J501: XH-6P; JST_XH_B6B-XH-A_1x06_P2.50mm_Vertical; MPN JST B6B-XH-A (or clone); JLC Hand
Q501: AO3401A; SOT-23; MPN AO3401A; LCSC C15127
Q502, Q506, Q510, Q511: MMBT3904; SOT-23; MPN MMBT3904; LCSC C20526
Q503: 2N7002; SOT-23; MPN 2N7002; LCSC C8545
Q504, Q505, Q508: AO3400A; SOT-23; MPN AO3400A; LCSC C20917
Q507, Q509: MMBT3906; SOT-23; MPN MMBT3906; LCSC C7420354
R501, R502, R522: 100; R_0603_1608Metric; LCSC C22775
R503, R507, R517, R539: 10k; R_0603_1608Metric; LCSC C25804
R504: 4.7k; R_0603_1608Metric; LCSC C23162
R505, R514, R535, R536, R537, R538, R540: 1k; R_0603_1608Metric; LCSC C21190
R506: 1.2R 2W; R_2512_6332Metric; MPN FRP2512F1R20TS; LCSC C7468247
R508, R509, R510, R511, R512, R518, R523, R532, R544, R548: 100k; R_0603_1608Metric; LCSC C25803
R513: 49.9k; R_0603_1608Metric; LCSC C23184
R515, R534, R541, R551, R552: 47k; R_0603_1608Metric; LCSC C25819
R516: 30k; R_0603_1608Metric; LCSC C22984
R519: 75k; R_0603_1608Metric; LCSC C23242
R520: 36k; R_0603_1608Metric; LCSC C23147
R521, R549: 1M; R_0603_1608Metric; LCSC C22935
R524, R525, R526, R527: 11R 2W; R_2512_6332Metric; MPN FRP2512F11R0TS; LCSC C7468192
R528, R547: 68k; R_0603_1608Metric; LCSC C23231
R529, R542: 33k; R_0603_1608Metric; LCSC C4216
R530: 62k; R_0603_1608Metric; LCSC C23221
R531: 240k; R_0603_1608Metric; LCSC C4197
R533: 150k; R_0603_1608Metric; LCSC C22807
R543: 360k; R_0603_1608Metric; LCSC C23146
R545: 27k; R_0603_1608Metric; LCSC C22967
R546: 200k; R_0603_1608Metric; LCSC C25811
R550: 0.1R 1% 50ppm; R_2512_Kelvin; MPN FRM252WFR100TN; LCSC C7420048
R553: 22k; R_0603_1608Metric; LCSC C31850
R555: 91k; R_0603_1608Metric; LCSC C23265
U501: LM324; SOIC-14_3.9x8.7mm_P1.27mm; MPN LM324DT; LCSC C71035

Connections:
+3V3: R539.1; also elsewhere on the board
+5V: C504.1, C509.2, Q501.2 (S), Q509.2 (E), R503.2, R532.1, R551.1, U501.4 (V+); also elsewhere on the board
/ch5/BNS_5: C502.1, J501.3, R502.1, R536.1, R541.1, R544.1, R547.1
/ch5/BN_5: J501.4, Q505.3 (D), R502.2, R533.1
/ch5/BPF_5: F501.1, J501.1
/ch5/BPS_5: C501.1, J501.2, R501.1, R515.1, R518.1, R528.1, R535.1
/ch5/BP_5: C503.1, F501.2, Q506.2 (E), R501.2, R506.2, R509.1, R524.1, R525.1, R526.1, R527.1, R534.2, R555.2
/ch5/CCN_5: C505.2, R512.2, R513.1, U501.2 (-)
/ch5/CCO_5: D502.1 (K), R514.1, U501.1
/ch5/CCP_5: C510.1, D507.2 (A), R509.2, R510.2, R511.1, U501.3 (+)
/ch5/CCZ_5: C505.1, R514.2
/ch5/CH1_5: D501.2 (A), Q501.3 (D)
/ch5/CH2_5: D501.1 (K), R506.1, R512.1
/ch5/CVO_5: D503.1 (K), R517.1, U501.7
/ch5/CVP_5: C511.1, D508.2 (A), R541.2, R542.2, R543.1, U501.5 (+)
/ch5/CVS_5: C506.2, R515.2, R516.1, U501.6 (-)
/ch5/CVZ_5: C506.1, R517.2
/ch5/DDRV_5: Q503.1 (G), R521.1, R522.1, U501.8
/ch5/DG_5: Q504.1 (G), R522.2, R523.1
/ch5/DLOAD_5: Q504.3 (D), R524.2, R525.2, R526.2, R527.2
/ch5/E2_5: Q502.2 (E), R505.1
/ch5/G1_5: C509.1, Q501.1 (G), Q502.3 (C), R503.1
/ch5/GENB_5: Q510.1 (B), R552.2
/ch5/GEN_5: D504.2 (A), D505.2 (A), D510.1 (K), Q506.3 (C), Q511.3 (C), R532.2, R552.1
/ch5/GISO_5: Q505.1 (G), Q508.1 (G), Q509.3 (C), R553.1
/ch5/GPB_5: Q509.1 (B), Q510.3 (C), R551.2
/ch5/LEDA_5: D506.2 (A), R540.2
/ch5/MIDISO_5: Q505.2 (S), Q508.2 (S), R553.2
/ch5/NBB_5: Q502.1 (B), R504.2
/ch5/NB_5: D502.2 (A), D503.2 (A), D510.2 (A), Q503.3 (D), R504.1, R507.2, R508.1
/ch5/OVO_5: D504.1 (K), R531.1, U501.14
/ch5/OVP_5: R530.2, R531.2, R547.2, R548.1, U501.12 (+)
/ch5/OVS_5: C507.1, D509.2 (A), R528.2, R529.1, U501.13 (-)
/ch5/SHNK_5: R538.1, R550.4
/ch5/SHPK_5: R537.1, R550.3
/ch5/SHP_5: Q508.3 (D), R550.1
/ch5/SNB_5: Q506.1 (B), Q507.2 (E), R533.2, R555.1
/ch5/SNC_5: Q507.3 (C), Q511.1 (B), R549.1
/ch5/SNPB_5: Q507.1 (B), R534.1
/ch5/SUMD_5: R518.2, R519.2, R520.1, R521.2, U501.10 (+)
/ch5/UVN_5: R544.2, R545.2, R546.1, U501.9 (-)
CHGEN_5: D507.1 (K), D508.1 (K), R507.1; also elsewhere on the board
DISEN_5: R519.1; also elsewhere on the board
GND: C501.2, C502.2, C503.2, C504.2, C507.2, C508.2, C510.2, C511.2, D506.1 (K), J501.6, Q503.2 (S), Q504.2 (S), Q510.2 (E), Q511.2 (E), R505.2, R508.2, R511.2, R513.2, R516.2, R520.2, R523.2, R529.2, R543.2, R546.2, R548.2, R549.2, R550.2, U501.11 (V-); also elsewhere on the board
LED_5: R540.1; also elsewhere on the board
MXA_5: R535.2; also elsewhere on the board
MXB_5: R536.2; also elsewhere on the board
MXC_5: R537.2; also elsewhere on the board
MXE_5: R538.2; also elsewhere on the board
NTC_5: C508.1, J501.5, R539.2; also elsewhere on the board
SAFE_EN: D505.1 (K), D509.1 (K); also elsewhere on the board
VREF: R530.1, R542.1, R545.1; also elsewhere on the board
VS: R510.1; also elsewhere on the board

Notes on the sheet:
Cell channel 5: charger, discharger, protection, measurement

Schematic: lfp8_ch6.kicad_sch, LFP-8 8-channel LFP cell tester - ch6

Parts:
C601, C602, C606, C608, C611: 10n; C_0603_1608Metric; LCSC C57112
C603, C607: 1u; C_0603_1608Metric; LCSC C15849
C604: 100n; C_0603_1608Metric; LCSC C14663
C605, C610: 47n; C_0603_1608Metric; LCSC C1622
C609: 1n; C_0603_1608Metric; LCSC C1588
D601: SS34; D_SMA; MPN SS34; LCSC C8678
D602, D603, D604, D605, D607, D608, D609, D610: BAT54WS; D_SOD-323; MPN BAT54WS; LCSC C7502694
D606: Green; LED_0805_2012Metric; MPN 0805 green; LCSC C2297
F601: PTC 2A; Fuse_1812_4532Metric; MPN 1812L200/30GR; LCSC C18198342
J601: XH-6P; JST_XH_B6B-XH-A_1x06_P2.50mm_Vertical; MPN JST B6B-XH-A (or clone); JLC Hand
Q601: AO3401A; SOT-23; MPN AO3401A; LCSC C15127
Q602, Q606, Q610, Q611: MMBT3904; SOT-23; MPN MMBT3904; LCSC C20526
Q603: 2N7002; SOT-23; MPN 2N7002; LCSC C8545
Q604, Q605, Q608: AO3400A; SOT-23; MPN AO3400A; LCSC C20917
Q607, Q609: MMBT3906; SOT-23; MPN MMBT3906; LCSC C7420354
R601, R602, R622: 100; R_0603_1608Metric; LCSC C22775
R603, R607, R617, R639: 10k; R_0603_1608Metric; LCSC C25804
R604: 4.7k; R_0603_1608Metric; LCSC C23162
R605, R614, R635, R636, R637, R638, R640: 1k; R_0603_1608Metric; LCSC C21190
R606: 1.2R 2W; R_2512_6332Metric; MPN FRP2512F1R20TS; LCSC C7468247
R608, R609, R610, R611, R612, R618, R623, R632, R644, R648: 100k; R_0603_1608Metric; LCSC C25803
R613: 49.9k; R_0603_1608Metric; LCSC C23184
R615, R634, R641, R651, R652: 47k; R_0603_1608Metric; LCSC C25819
R616: 30k; R_0603_1608Metric; LCSC C22984
R619: 75k; R_0603_1608Metric; LCSC C23242
R620: 36k; R_0603_1608Metric; LCSC C23147
R621, R649: 1M; R_0603_1608Metric; LCSC C22935
R624, R625, R626, R627: 11R 2W; R_2512_6332Metric; MPN FRP2512F11R0TS; LCSC C7468192
R628, R647: 68k; R_0603_1608Metric; LCSC C23231
R629, R642: 33k; R_0603_1608Metric; LCSC C4216
R630: 62k; R_0603_1608Metric; LCSC C23221
R631: 240k; R_0603_1608Metric; LCSC C4197
R633: 150k; R_0603_1608Metric; LCSC C22807
R643: 360k; R_0603_1608Metric; LCSC C23146
R645: 27k; R_0603_1608Metric; LCSC C22967
R646: 200k; R_0603_1608Metric; LCSC C25811
R650: 0.1R 1% 50ppm; R_2512_Kelvin; MPN FRM252WFR100TN; LCSC C7420048
R653: 22k; R_0603_1608Metric; LCSC C31850
R655: 91k; R_0603_1608Metric; LCSC C23265
U601: LM324; SOIC-14_3.9x8.7mm_P1.27mm; MPN LM324DT; LCSC C71035

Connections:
+3V3: R639.1; also elsewhere on the board
+5V: C604.1, C609.2, Q601.2 (S), Q609.2 (E), R603.2, R632.1, R651.1, U601.4 (V+); also elsewhere on the board
/ch6/BNS_6: C602.1, J601.3, R602.1, R636.1, R641.1, R644.1, R647.1
/ch6/BN_6: J601.4, Q605.3 (D), R602.2, R633.1
/ch6/BPF_6: F601.1, J601.1
/ch6/BPS_6: C601.1, J601.2, R601.1, R615.1, R618.1, R628.1, R635.1
/ch6/BP_6: C603.1, F601.2, Q606.2 (E), R601.2, R606.2, R609.1, R624.1, R625.1, R626.1, R627.1, R634.2, R655.2
/ch6/CCN_6: C605.2, R612.2, R613.1, U601.2 (-)
/ch6/CCO_6: D602.1 (K), R614.1, U601.1
/ch6/CCP_6: C610.1, D607.2 (A), R609.2, R610.2, R611.1, U601.3 (+)
/ch6/CCZ_6: C605.1, R614.2
/ch6/CH1_6: D601.2 (A), Q601.3 (D)
/ch6/CH2_6: D601.1 (K), R606.1, R612.1
/ch6/CVO_6: D603.1 (K), R617.1, U601.7
/ch6/CVP_6: C611.1, D608.2 (A), R641.2, R642.2, R643.1, U601.5 (+)
/ch6/CVS_6: C606.2, R615.2, R616.1, U601.6 (-)
/ch6/CVZ_6: C606.1, R617.2
/ch6/DDRV_6: Q603.1 (G), R621.1, R622.1, U601.8
/ch6/DG_6: Q604.1 (G), R622.2, R623.1
/ch6/DLOAD_6: Q604.3 (D), R624.2, R625.2, R626.2, R627.2
/ch6/E2_6: Q602.2 (E), R605.1
/ch6/G1_6: C609.1, Q601.1 (G), Q602.3 (C), R603.1
/ch6/GENB_6: Q610.1 (B), R652.2
/ch6/GEN_6: D604.2 (A), D605.2 (A), D610.1 (K), Q606.3 (C), Q611.3 (C), R632.2, R652.1
/ch6/GISO_6: Q605.1 (G), Q608.1 (G), Q609.3 (C), R653.1
/ch6/GPB_6: Q609.1 (B), Q610.3 (C), R651.2
/ch6/LEDA_6: D606.2 (A), R640.2
/ch6/MIDISO_6: Q605.2 (S), Q608.2 (S), R653.2
/ch6/NBB_6: Q602.1 (B), R604.2
/ch6/NB_6: D602.2 (A), D603.2 (A), D610.2 (A), Q603.3 (D), R604.1, R607.2, R608.1
/ch6/OVO_6: D604.1 (K), R631.1, U601.14
/ch6/OVP_6: R630.2, R631.2, R647.2, R648.1, U601.12 (+)
/ch6/OVS_6: C607.1, D609.2 (A), R628.2, R629.1, U601.13 (-)
/ch6/SHNK_6: R638.1, R650.4
/ch6/SHPK_6: R637.1, R650.3
/ch6/SHP_6: Q608.3 (D), R650.1
/ch6/SNB_6: Q606.1 (B), Q607.2 (E), R633.2, R655.1
/ch6/SNC_6: Q607.3 (C), Q611.1 (B), R649.1
/ch6/SNPB_6: Q607.1 (B), R634.1
/ch6/SUMD_6: R618.2, R619.2, R620.1, R621.2, U601.10 (+)
/ch6/UVN_6: R644.2, R645.2, R646.1, U601.9 (-)
CHGEN_6: D607.1 (K), D608.1 (K), R607.1; also elsewhere on the board
DISEN_6: R619.1; also elsewhere on the board
GND: C601.2, C602.2, C603.2, C604.2, C607.2, C608.2, C610.2, C611.2, D606.1 (K), J601.6, Q603.2 (S), Q604.2 (S), Q610.2 (E), Q611.2 (E), R605.2, R608.2, R611.2, R613.2, R616.2, R620.2, R623.2, R629.2, R643.2, R646.2, R648.2, R649.2, R650.2, U601.11 (V-); also elsewhere on the board
LED_6: R640.1; also elsewhere on the board
MXA_6: R635.2; also elsewhere on the board
MXB_6: R636.2; also elsewhere on the board
MXC_6: R637.2; also elsewhere on the board
MXE_6: R638.2; also elsewhere on the board
NTC_6: C608.1, J601.5, R639.2; also elsewhere on the board
SAFE_EN: D605.1 (K), D609.1 (K); also elsewhere on the board
VREF: R630.1, R642.1, R645.1; also elsewhere on the board
VS: R610.1; also elsewhere on the board

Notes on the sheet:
Cell channel 6: charger, discharger, protection, measurement

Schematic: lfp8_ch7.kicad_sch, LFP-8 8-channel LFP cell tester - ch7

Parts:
C701, C702, C706, C708, C711: 10n; C_0603_1608Metric; LCSC C57112
C703, C707: 1u; C_0603_1608Metric; LCSC C15849
C704: 100n; C_0603_1608Metric; LCSC C14663
C705, C710: 47n; C_0603_1608Metric; LCSC C1622
C709: 1n; C_0603_1608Metric; LCSC C1588
D701: SS34; D_SMA; MPN SS34; LCSC C8678
D702, D703, D704, D705, D707, D708, D709, D710: BAT54WS; D_SOD-323; MPN BAT54WS; LCSC C7502694
D706: Green; LED_0805_2012Metric; MPN 0805 green; LCSC C2297
F701: PTC 2A; Fuse_1812_4532Metric; MPN 1812L200/30GR; LCSC C18198342
J701: XH-6P; JST_XH_B6B-XH-A_1x06_P2.50mm_Vertical; MPN JST B6B-XH-A (or clone); JLC Hand
Q701: AO3401A; SOT-23; MPN AO3401A; LCSC C15127
Q702, Q706, Q710, Q711: MMBT3904; SOT-23; MPN MMBT3904; LCSC C20526
Q703: 2N7002; SOT-23; MPN 2N7002; LCSC C8545
Q704, Q705, Q708: AO3400A; SOT-23; MPN AO3400A; LCSC C20917
Q707, Q709: MMBT3906; SOT-23; MPN MMBT3906; LCSC C7420354
R701, R702, R722: 100; R_0603_1608Metric; LCSC C22775
R703, R707, R717, R739: 10k; R_0603_1608Metric; LCSC C25804
R704: 4.7k; R_0603_1608Metric; LCSC C23162
R705, R714, R735, R736, R737, R738, R740: 1k; R_0603_1608Metric; LCSC C21190
R706: 1.2R 2W; R_2512_6332Metric; MPN FRP2512F1R20TS; LCSC C7468247
R708, R709, R710, R711, R712, R718, R723, R732, R744, R748: 100k; R_0603_1608Metric; LCSC C25803
R713: 49.9k; R_0603_1608Metric; LCSC C23184
R715, R734, R741, R751, R752: 47k; R_0603_1608Metric; LCSC C25819
R716: 30k; R_0603_1608Metric; LCSC C22984
R719: 75k; R_0603_1608Metric; LCSC C23242
R720: 36k; R_0603_1608Metric; LCSC C23147
R721, R749: 1M; R_0603_1608Metric; LCSC C22935
R724, R725, R726, R727: 11R 2W; R_2512_6332Metric; MPN FRP2512F11R0TS; LCSC C7468192
R728, R747: 68k; R_0603_1608Metric; LCSC C23231
R729, R742: 33k; R_0603_1608Metric; LCSC C4216
R730: 62k; R_0603_1608Metric; LCSC C23221
R731: 240k; R_0603_1608Metric; LCSC C4197
R733: 150k; R_0603_1608Metric; LCSC C22807
R743: 360k; R_0603_1608Metric; LCSC C23146
R745: 27k; R_0603_1608Metric; LCSC C22967
R746: 200k; R_0603_1608Metric; LCSC C25811
R750: 0.1R 1% 50ppm; R_2512_Kelvin; MPN FRM252WFR100TN; LCSC C7420048
R753: 22k; R_0603_1608Metric; LCSC C31850
R755: 91k; R_0603_1608Metric; LCSC C23265
U701: LM324; SOIC-14_3.9x8.7mm_P1.27mm; MPN LM324DT; LCSC C71035

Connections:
+3V3: R739.1; also elsewhere on the board
+5V: C704.1, C709.2, Q701.2 (S), Q709.2 (E), R703.2, R732.1, R751.1, U701.4 (V+); also elsewhere on the board
/ch7/BNS_7: C702.1, J701.3, R702.1, R736.1, R741.1, R744.1, R747.1
/ch7/BN_7: J701.4, Q705.3 (D), R702.2, R733.1
/ch7/BPF_7: F701.1, J701.1
/ch7/BPS_7: C701.1, J701.2, R701.1, R715.1, R718.1, R728.1, R735.1
/ch7/BP_7: C703.1, F701.2, Q706.2 (E), R701.2, R706.2, R709.1, R724.1, R725.1, R726.1, R727.1, R734.2, R755.2
/ch7/CCN_7: C705.2, R712.2, R713.1, U701.2 (-)
/ch7/CCO_7: D702.1 (K), R714.1, U701.1
/ch7/CCP_7: C710.1, D707.2 (A), R709.2, R710.2, R711.1, U701.3 (+)
/ch7/CCZ_7: C705.1, R714.2
/ch7/CH1_7: D701.2 (A), Q701.3 (D)
/ch7/CH2_7: D701.1 (K), R706.1, R712.1
/ch7/CVO_7: D703.1 (K), R717.1, U701.7
/ch7/CVP_7: C711.1, D708.2 (A), R741.2, R742.2, R743.1, U701.5 (+)
/ch7/CVS_7: C706.2, R715.2, R716.1, U701.6 (-)
/ch7/CVZ_7: C706.1, R717.2
/ch7/DDRV_7: Q703.1 (G), R721.1, R722.1, U701.8
/ch7/DG_7: Q704.1 (G), R722.2, R723.1
/ch7/DLOAD_7: Q704.3 (D), R724.2, R725.2, R726.2, R727.2
/ch7/E2_7: Q702.2 (E), R705.1
/ch7/G1_7: C709.1, Q701.1 (G), Q702.3 (C), R703.1
/ch7/GENB_7: Q710.1 (B), R752.2
/ch7/GEN_7: D704.2 (A), D705.2 (A), D710.1 (K), Q706.3 (C), Q711.3 (C), R732.2, R752.1
/ch7/GISO_7: Q705.1 (G), Q708.1 (G), Q709.3 (C), R753.1
/ch7/GPB_7: Q709.1 (B), Q710.3 (C), R751.2
/ch7/LEDA_7: D706.2 (A), R740.2
/ch7/MIDISO_7: Q705.2 (S), Q708.2 (S), R753.2
/ch7/NBB_7: Q702.1 (B), R704.2
/ch7/NB_7: D702.2 (A), D703.2 (A), D710.2 (A), Q703.3 (D), R704.1, R707.2, R708.1
/ch7/OVO_7: D704.1 (K), R731.1, U701.14
/ch7/OVP_7: R730.2, R731.2, R747.2, R748.1, U701.12 (+)
/ch7/OVS_7: C707.1, D709.2 (A), R728.2, R729.1, U701.13 (-)
/ch7/SHNK_7: R738.1, R750.4
/ch7/SHPK_7: R737.1, R750.3
/ch7/SHP_7: Q708.3 (D), R750.1
/ch7/SNB_7: Q706.1 (B), Q707.2 (E), R733.2, R755.1
/ch7/SNC_7: Q707.3 (C), Q711.1 (B), R749.1
/ch7/SNPB_7: Q707.1 (B), R734.1
/ch7/SUMD_7: R718.2, R719.2, R720.1, R721.2, U701.10 (+)
/ch7/UVN_7: R744.2, R745.2, R746.1, U701.9 (-)
CHGEN_7: D707.1 (K), D708.1 (K), R707.1; also elsewhere on the board
DISEN_7: R719.1; also elsewhere on the board
GND: C701.2, C702.2, C703.2, C704.2, C707.2, C708.2, C710.2, C711.2, D706.1 (K), J701.6, Q703.2 (S), Q704.2 (S), Q710.2 (E), Q711.2 (E), R705.2, R708.2, R711.2, R713.2, R716.2, R720.2, R723.2, R729.2, R743.2, R746.2, R748.2, R749.2, R750.2, U701.11 (V-); also elsewhere on the board
LED_7: R740.1; also elsewhere on the board
MXA_7: R735.2; also elsewhere on the board
MXB_7: R736.2; also elsewhere on the board
MXC_7: R737.2; also elsewhere on the board
MXE_7: R738.2; also elsewhere on the board
NTC_7: C708.1, J701.5, R739.2; also elsewhere on the board
SAFE_EN: D705.1 (K), D709.1 (K); also elsewhere on the board
VREF: R730.1, R742.1, R745.1; also elsewhere on the board
VS: R710.1; also elsewhere on the board

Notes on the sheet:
Cell channel 7: charger, discharger, protection, measurement

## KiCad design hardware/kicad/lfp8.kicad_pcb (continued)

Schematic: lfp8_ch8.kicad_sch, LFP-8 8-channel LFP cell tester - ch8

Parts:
C801, C802, C806, C808, C811: 10n; C_0603_1608Metric; LCSC C57112
C803, C807: 1u; C_0603_1608Metric; LCSC C15849
C804: 100n; C_0603_1608Metric; LCSC C14663
C805, C810: 47n; C_0603_1608Metric; LCSC C1622
C809: 1n; C_0603_1608Metric; LCSC C1588
D801: SS34; D_SMA; MPN SS34; LCSC C8678
D802, D803, D804, D805, D807, D808, D809, D810: BAT54WS; D_SOD-323; MPN BAT54WS; LCSC C7502694
D806: Green; LED_0805_2012Metric; MPN 0805 green; LCSC C2297
F801: PTC 2A; Fuse_1812_4532Metric; MPN 1812L200/30GR; LCSC C18198342
J801: XH-6P; JST_XH_B6B-XH-A_1x06_P2.50mm_Vertical; MPN JST B6B-XH-A (or clone); JLC Hand
Q801: AO3401A; SOT-23; MPN AO3401A; LCSC C15127
Q802, Q806, Q810, Q811: MMBT3904; SOT-23; MPN MMBT3904; LCSC C20526
Q803: 2N7002; SOT-23; MPN 2N7002; LCSC C8545
Q804, Q805, Q808: AO3400A; SOT-23; MPN AO3400A; LCSC C20917
Q807, Q809: MMBT3906; SOT-23; MPN MMBT3906; LCSC C7420354
R801, R802, R822: 100; R_0603_1608Metric; LCSC C22775
R803, R807, R817, R839: 10k; R_0603_1608Metric; LCSC C25804
R804: 4.7k; R_0603_1608Metric; LCSC C23162
R805, R814, R835, R836, R837, R838, R840: 1k; R_0603_1608Metric; LCSC C21190
R806: 1.2R 2W; R_2512_6332Metric; MPN FRP2512F1R20TS; LCSC C7468247
R808, R809, R810, R811, R812, R818, R823, R832, R844, R848: 100k; R_0603_1608Metric; LCSC C25803
R813: 49.9k; R_0603_1608Metric; LCSC C23184
R815, R834, R841, R851, R852: 47k; R_0603_1608Metric; LCSC C25819
R816: 30k; R_0603_1608Metric; LCSC C22984
R819: 75k; R_0603_1608Metric; LCSC C23242
R820: 36k; R_0603_1608Metric; LCSC C23147
R821, R849: 1M; R_0603_1608Metric; LCSC C22935
R824, R825, R826, R827: 11R 2W; R_2512_6332Metric; MPN FRP2512F11R0TS; LCSC C7468192
R828, R847: 68k; R_0603_1608Metric; LCSC C23231
R829, R842: 33k; R_0603_1608Metric; LCSC C4216
R830: 62k; R_0603_1608Metric; LCSC C23221
R831: 240k; R_0603_1608Metric; LCSC C4197
R833: 150k; R_0603_1608Metric; LCSC C22807
R843: 360k; R_0603_1608Metric; LCSC C23146
R845: 27k; R_0603_1608Metric; LCSC C22967
R846: 200k; R_0603_1608Metric; LCSC C25811
R850: 0.1R 1% 50ppm; R_2512_Kelvin; MPN FRM252WFR100TN; LCSC C7420048
R853: 22k; R_0603_1608Metric; LCSC C31850
R855: 91k; R_0603_1608Metric; LCSC C23265
U801: LM324; SOIC-14_3.9x8.7mm_P1.27mm; MPN LM324DT; LCSC C71035

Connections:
+3V3: R839.1; also elsewhere on the board
+5V: C804.1, C809.2, Q801.2 (S), Q809.2 (E), R803.2, R832.1, R851.1, U801.4 (V+); also elsewhere on the board
/ch8/BNS_8: C802.1, J801.3, R802.1, R836.1, R841.1, R844.1, R847.1
/ch8/BN_8: J801.4, Q805.3 (D), R802.2, R833.1
/ch8/BPF_8: F801.1, J801.1
/ch8/BPS_8: C801.1, J801.2, R801.1, R815.1, R818.1, R828.1, R835.1
/ch8/BP_8: C803.1, F801.2, Q806.2 (E), R801.2, R806.2, R809.1, R824.1, R825.1, R826.1, R827.1, R834.2, R855.2
/ch8/CCN_8: C805.2, R812.2, R813.1, U801.2 (-)
/ch8/CCO_8: D802.1 (K), R814.1, U801.1
/ch8/CCP_8: C810.1, D807.2 (A), R809.2, R810.2, R811.1, U801.3 (+)
/ch8/CCZ_8: C805.1, R814.2
/ch8/CH1_8: D801.2 (A), Q801.3 (D)
/ch8/CH2_8: D801.1 (K), R806.1, R812.1
/ch8/CVO_8: D803.1 (K), R817.1, U801.7
/ch8/CVP_8: C811.1, D808.2 (A), R841.2, R842.2, R843.1, U801.5 (+)
/ch8/CVS_8: C806.2, R815.2, R816.1, U801.6 (-)
/ch8/CVZ_8: C806.1, R817.2
/ch8/DDRV_8: Q803.1 (G), R821.1, R822.1, U801.8
/ch8/DG_8: Q804.1 (G), R822.2, R823.1
/ch8/DLOAD_8: Q804.3 (D), R824.2, R825.2, R826.2, R827.2
/ch8/E2_8: Q802.2 (E), R805.1
/ch8/G1_8: C809.1, Q801.1 (G), Q802.3 (C), R803.1
/ch8/GENB_8: Q810.1 (B), R852.2
/ch8/GEN_8: D804.2 (A), D805.2 (A), D810.1 (K), Q806.3 (C), Q811.3 (C), R832.2, R852.1
/ch8/GISO_8: Q805.1 (G), Q808.1 (G), Q809.3 (C), R853.1
/ch8/GPB_8: Q809.1 (B), Q810.3 (C), R851.2
/ch8/LEDA_8: D806.2 (A), R840.2
/ch8/MIDISO_8: Q805.2 (S), Q808.2 (S), R853.2
/ch8/NBB_8: Q802.1 (B), R804.2
/ch8/NB_8: D802.2 (A), D803.2 (A), D810.2 (A), Q803.3 (D), R804.1, R807.2, R808.1
/ch8/OVO_8: D804.1 (K), R831.1, U801.14
/ch8/OVP_8: R830.2, R831.2, R847.2, R848.1, U801.12 (+)
/ch8/OVS_8: C807.1, D809.2 (A), R828.2, R829.1, U801.13 (-)
/ch8/SHNK_8: R838.1, R850.4
/ch8/SHPK_8: R837.1, R850.3
/ch8/SHP_8: Q808.3 (D), R850.1
/ch8/SNB_8: Q806.1 (B), Q807.2 (E), R833.2, R855.1
/ch8/SNC_8: Q807.3 (C), Q811.1 (B), R849.1
/ch8/SNPB_8: Q807.1 (B), R834.1
/ch8/SUMD_8: R818.2, R819.2, R820.1, R821.2, U801.10 (+)
/ch8/UVN_8: R844.2, R845.2, R846.1, U801.9 (-)
CHGEN_8: D807.1 (K), D808.1 (K), R807.1; also elsewhere on the board
DISEN_8: R819.1; also elsewhere on the board
GND: C801.2, C802.2, C803.2, C804.2, C807.2, C808.2, C810.2, C811.2, D806.1 (K), J801.6, Q803.2 (S), Q804.2 (S), Q810.2 (E), Q811.2 (E), R805.2, R808.2, R811.2, R813.2, R816.2, R820.2, R823.2, R829.2, R843.2, R846.2, R848.2, R849.2, R850.2, U801.11 (V-); also elsewhere on the board
LED_8: R840.1; also elsewhere on the board
MXA_8: R835.2; also elsewhere on the board
MXB_8: R836.2; also elsewhere on the board
MXC_8: R837.2; also elsewhere on the board
MXE_8: R838.2; also elsewhere on the board
NTC_8: C808.1, J801.5, R839.2; also elsewhere on the board
SAFE_EN: D805.1 (K), D809.1 (K); also elsewhere on the board
VREF: R830.1, R842.1, R845.1; also elsewhere on the board
VS: R810.1; also elsewhere on the board

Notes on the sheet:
Cell channel 8: charger, discharger, protection, measurement

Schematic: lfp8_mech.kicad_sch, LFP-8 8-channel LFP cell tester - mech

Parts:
H1, H2, H3, H4: M3; MountingHole_3.2mm_M3; JLC Hand

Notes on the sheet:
Mounting holes


Board: 2 copper layers, 216.0 x 146.0 mm, 835 parts (0 on the bottom side), 431 nets.

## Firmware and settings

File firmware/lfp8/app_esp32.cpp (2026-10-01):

// ESP32 application: control task + persistence + glue.
#if defined(ARDUINO)
#include "app_esp32.h"

#include <Arduino.h>
#include <esp_mac.h>
#include <esp_task_wdt.h>
#include <freertos/FreeRTOS.h>
#include <freertos/semphr.h>
#include <freertos/task.h>

#include "hal_esp32.h"

namespace lfp8 {
namespace app {

namespace {
#if ARDUINO_USB_MODE && ARDUINO_USB_CDC_ON_BOOT
HWCDC &usb() { return HWCDCSerial; }
#else
HWCDC g_usb;  // own instance: works with the default "USB CDC On Boot: Disabled"
HWCDC &usb() { return g_usb; }
#endif

Esp32Hal g_hal;
Controller g_ctl(g_hal);  // ~110 KB incl. the 24 h history ring
SemaphoreHandle_t g_mtx = nullptr;
TaskHandle_t g_ctlTask = nullptr;
uint32_t g_rebootAtMs = 0;
bool g_reboot = false;
uint32_t g_lastPersistMs = 0;
uint32_t g_savedResultsVersion = 0;
uint32_t g_bootPressedMs = 0;
bool g_cfgPending = false;  // settings changed but not yet written to NVS

// Higher than the Arduino loop task (1) and the web server, lower than the
// WiFi/lwIP tasks so networking keeps working.
constexpr UBaseType_t kCtlPriority = 10;
constexpr uint32_t kCtlStack = 6144;
constexpr uint32_t kTwdtMs = 3000;

// The main control loop. The heartbeat is toggled inside Controller::step()
// (software GPIO write, never a timer/LEDC/RMT): if this loop stalls, the
// hardware watchdog removes SAFE_EN within ~70 ms. The task watchdog resets
// the chip if the loop hangs for 3 s.
void controlTask(void *) {
  esp_task_wdt_add(nullptr);
  for (;;) {
    bool fast = false;
    // Short wait only: the hardware watchdog trips 23..33 ms after the last
    // heartbeat edge. The web side holds the lock for copies (microseconds).
    if (xSemaphoreTake(g_mtx, pdMS_TO_TICKS(3)) == pdTRUE) {
      g_ctl.step();
      fast = g_ctl.wantsFastLoop();
      xSemaphoreGive(g_mtx);
      esp_task_wdt_reset();
    }
    if (fast) {
      // IR pulse running: poll the ADS1115 at 860 SPS without sleeping a tick.
      esp_rom_delay_us(100);
      taskYIELD();
    } else {
      vTaskDelay(1);  // 1 ms tick -> ~500 Hz heartbeat square wave
    }
  }
}

// NVS writes may erase a flash sector, which stalls the whole CPU (cache off)
// for tens of ms - longer than the 23 ms hardware watchdog window. They are
// therefore only done while no job is running (or right before a reboot);
// changes are applied in RAM immediately.
void persistLoop(bool force) {
  uint32_t now = millis();
  if (!force && now - g_lastPersistMs < 1000) return;
  g_lastPersistMs = now;
  bool saveCfg = false, saveRes = false;
  Settings s;
  static ChResult res[kNumCh];
  if (lock()) {
    if (!force && g_ctl.anyJobActive()) {
      unlock();
      return;  // deferred until the board is idle
    }
    if (g_ctl.settingsDirty() || g_cfgPending) {
      s = g_ctl.settings();
      g_ctl.clearSettingsDirty();
      g_cfgPending = false;
      saveCfg = true;
    }
    if (g_ctl.resultsVersion() != g_savedResultsVersion) {
      g_savedResultsVersion = g_ctl.resultsVersion();
      g_ctl.getResults(res);
      saveRes = true;
    }
    unlock();
  }
  if (saveCfg) nvsSaveSettings(s);
  if (saveRes) nvsSaveResults(res);
}

void bootButtonLoop() {
  // Hold BOOT for 5 s at runtime: forget WiFi credentials and restart in AP mode.
  bool pressed = g_hal.bootButton();
  uint32_t now = millis();
  if (!pressed) {
    g_bootPressedMs = 0;
    return;
  }
  if (g_bootPressedMs == 0) g_bootPressedMs = now ? now : 1;
  if (now - g_bootPressedMs > 5000) {
    Settings s = settings();
    s.wifiSsid[0] = 0;
    s.wifiPass[0] = 0;
    applySettings(s);
    con().println("[lfp8] BOOT held 5 s: WiFi credentials cleared, rebooting to AP mode");
    requestReboot(200);
    g_bootPressedMs = now;
  }
}
}  // namespace

::Print &con() { return usb(); }

Controller &ctl() { return g_ctl; }

bool lock(uint32_t timeoutMs) { return g_mtx && xSemaphoreTake(g_mtx, pdMS_TO_TICKS(timeoutMs)) == pdTRUE; }
void unlock() { xSemaphoreGive(g_mtx); }

Settings settings() {
  Settings s;
  Lock l;
  s = g_ctl.settings();
  return s;
}

bool applySettings(const Settings &in) {
  Settings s = in;
  settingsSanitize(s);
  bool busy = true;
  {
    Lock l;
    if (l.ok) {
      g_ctl.setSettings(s);
      busy = g_ctl.anyJobActive();
    }
  }
  if (busy) {
    g_cfgPending = true;  // written by persistLoop() once the board is idle
    return false;
  }
  nvsSaveSettings(s);
  return true;
}

void requestReboot(uint32_t delayMs) {
  g_rebootAtMs = millis() + delayMs;
  g_reboot = true;
}

void setup() {
  usb().begin(115200);  // native USB console; UART0 pins are IO20/IO21 (SAFE_RB/FAN)
  g_hal.begin();              // outputs off, heartbeat low

  Settings s;
  bool loaded = nvsLoadSettings(s);
  if (!loaded) {
    settingsDefaults(s);
    uint8_t mac[6] = {0};
    esp_read_mac(mac, ESP_MAC_WIFI_STA);
    s.boardId = boardIdFromMac(mac);
  }
  settingsSanitize(s);

  esp_task_wdt_config_t twdt = {};
  twdt.timeout_ms = kTwdtMs;
  twdt.idle_core_mask = 0;
  twdt.trigger_panic = true;
  if (esp_task_wdt_reconfigure(&twdt) != ESP_OK) esp_task_wdt_init(&twdt);

  g_mtx = xSemaphoreCreateMutex();
  g_ctl.begin(s);
  static ChResult res[kNumCh];
  if (nvsLoadResults(res)) g_ctl.restoreResults(res);
  g_savedResultsVersion = g_ctl.resultsVersion();
  if (!loaded || g_ctl.settingsDirty()) {
    nvsSaveSettings(g_ctl.settings());
    g_ctl.clearSettingsDirty();
  }
  // Start the control loop (and with it the heartbeat) before WiFi so the
  // board is supervised while the network comes up.
  xTaskCreate(controlTask, "lfp8_ctl", kCtlStack, nullptr, kCtlPriority, &g_ctlTask);

  con().printf("[lfp8] LFP-8 firmware %s, board %u\n", LFP8_FW_VERSION, (unsigned)s.boardId);
  netBegin(s);
  webBegin();
}

void loop() {
  webLoop();
  netLoop();
  persistLoop(false);
  bootButtonLoop();
  if (g_reboot && (int32_t)(millis() - g_rebootAtMs) >= 0) {
    {
      Lock l;
      if (l.ok) g_ctl.setMaintenance(true);  // outputs off before the reset
    }
    persistLoop(true);  // heartbeat already stopped: flash stalls are harmless now
    delay(50);
    ESP.restart();
  }
  vTaskDelay(1);
}

}  // namespace app
}  // namespace lfp8
#endif  // ARDUINO

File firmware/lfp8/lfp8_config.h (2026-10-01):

// LFP-8 firmware - fixed board constants, pin map and timing.
// Source of truth: docs/INTERFACE.md (sections referenced below).
// Pure C++ (no Arduino headers) - shared by the ESP32 build and host tests.
#pragma once
#include <stdint.h>

#define LFP8_FW_VERSION "1.0.0"

namespace lfp8 {

constexpr int kNumCh = 8;  // channels per board

// ---- §8 fixed board constants ---------------------------------------------
constexpr float kRShunt = 0.100f;        // ohm, current shunt
constexpr float kRChgBallast = 1.2f;     // ohm, charge path (also the CC sense resistor)
constexpr float kRLoad = 2.75f;          // ohm, discharge load (4 x 11R)
constexpr float kDivVchk = 0.5f;         // ADC_VCHK = B+S * 0.5
constexpr float kDivVin = 0.3197f;       // ADC_VIN = +5V * 0.3197
constexpr float kNtcPullup = 10000.0f;   // ohm to 3.3 V
constexpr float kNtcR25 = 10000.0f;      // ohm
constexpr float kNtcBeta = 3950.0f;      // K
constexpr float kNtcSupply = 3.3f;       // V
constexpr float kVref = 2.495f;          // V
constexpr float kCvSetNom = 3.576f;      // V, hardware CV (nominal; 3.51..3.62 with tolerances)
constexpr float kOvTrip = 3.82f;         // V, hardware OV latch (3.78..3.87), releases < 2.74 V or SAFE_EN low
constexpr float kOvRelease = 2.74f;
constexpr float kUvTrip = 2.22f;         // V, hardware UV backstop under load (DIS_EN=1)
constexpr float kUvRearm = 2.59f;        // V, the load cannot (re)start below this
constexpr float kDisStartMinV = 2.62f;   // refuse discharge starts below (load would not start)
constexpr float kTbrdSlope = -0.00197f;  // V/K, MMBT3904 Vbe at ~100 uA (§8)
constexpr float kTbrdV25Default = 0.601f;// V at 25 C (§8)

// §4 charge-current DAC: set-point at a 5.20 V rail, scales with V_IN/5.20
constexpr float kIsetLutA[8] = {0.0f, 0.265f, 0.532f, 0.797f, 1.064f, 1.328f, 1.595f, 1.860f};
constexpr float kIsetRefRail = 5.20f;
// §4 passive ceiling of the linear charger: I_max = (V_IN - 0.38 V - V_cell) / 1.5 ohm
constexpr float kChgCeilDrop = 0.38f;
constexpr float kChgCeilR = 1.5f;
constexpr float kRailNominal = 5.20f;   // recommended +5V setting (5.00..5.25 allowed)
constexpr float kRailUvTrip = 4.48f;    // hardware rail UV
constexpr float kRailOvTrip = 5.50f;    // hardware rail OV
// §4 thermal policy of the SOT-23 pass FET
constexpr uint32_t kPulse50PeriodMs = 1000;  // 2.80..3.05 V: 50 % duty, 1 s period
constexpr uint32_t kPre20OnMs = 1000;        // 2.00..2.80 V: 20 % duty (1 s on / 4 s off)
constexpr uint32_t kPre20OffMs = 4000;
constexpr uint8_t kIsetDefault = 4;
constexpr uint8_t kIsetHotLimit = 5;     // ISET >= 6 only when board < 50 C
constexpr float kIsetHotTempC = 50.0f;
constexpr uint8_t kIsetIrPulse = 4;      // §7.1 charge-pulse fallback uses ISET 4

// ---- §2 GPIO map ----------------------------------------------------------
constexpr int kPinAdcNtc = 0;    // IO0  ADC1_CH0 mux D (cell NTC)
constexpr int kPinAdcVchk = 1;   // IO1  ADC1_CH1 mux A / 2
constexpr int kPinRclk = 2;      // IO2  74HC595 latch (strap)
constexpr int kPinAdcVin = 3;    // IO3  +5V * 0.3197
constexpr int kPinAdcTbrd = 4;   // IO4  board temperature (Vbe)
constexpr int kPinSda = 5;       // IO5
constexpr int kPinScl = 6;       // IO6
constexpr int kPinSer = 7;       // IO7  74HC595 serial data
constexpr int kPinSrclk = 8;     // IO8  74HC595 shift clock (strap)
constexpr int kPinBoot = 9;      // IO9  BOOT button, active low
constexpr int kPinHeartbeat = 10;// IO10 watchdog charge pump - software toggled only
constexpr int kPinSafeRb = 20;   // IO20 SAFE_EN read-back
constexpr int kPinFan = 21;      // IO21 fan MOSFET gate
constexpr uint8_t kAdsAddr = 0x48;
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

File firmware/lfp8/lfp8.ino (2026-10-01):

// LFP-8: 8-channel LiFePO4 (33140, 15 Ah) charger / discharger / tester.
// ESP32-C3-WROOM-02, Arduino-ESP32 core 3.x.
//
// Build:  arduino-cli compile --fqbn esp32:esp32:esp32c3 firmware/lfp8
// Contract with the hardware: docs/INTERFACE.md. See firmware/README.md.
//
// Architecture
//   hal.h            hardware abstraction (shift register, ADS1115, ADC, GPIO, time)
//   hal_esp32.*      ESP32-C3 implementation
//   controller.*     scanner, IR engine, outputs + interlock, heartbeat, fan, LEDs
//   channel.*        per-channel state machine and test programs
//   supervisor.*     safety supervisor (SAFE_RB, VIN, temperatures, ADC faults)
//   app_esp32.*      control task (heartbeat source), NVS, glue
//   net_esp32.cpp    WiFi STA/AP, mDNS, UDP discovery, ArduinoOTA
//   web_esp32.cpp    HTTP dashboard + JSON API
// Everything except *_esp32.* and this file is plain C++ and unit-tested on
// the host (make -C firmware test).
#include "app_esp32.h"

void setup() { lfp8::app::setup(); }

void loop() { lfp8::app::loop(); }

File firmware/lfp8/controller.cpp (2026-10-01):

#include "controller.h"

#include <math.h>
#include <stdio.h>
#include <string.h>

#include "leds.h"

namespace lfp8 {

namespace {
constexpr uint32_t kBoardReadMs = 100;
constexpr uint32_t kLoopMaxWindowMs = 10000;
constexpr uint32_t kIdentifyMs = 10000;
constexpr float kIrVCollapse = kUvTrip - 0.10f;
constexpr uint8_t kBmCount = 3;
constexpr float kBmIdleMax = 0.10f;   // |B-S - SHN| with no current -> B- sense warning
constexpr uint8_t kContactCount = 2;  // consecutive estimates > 0.3 ohm -> CONTACT_WARN
}  // namespace

// ------------------------------------------------------------------ setup ----
void Controller::begin(const Settings &s) {
  cfg_ = s;
  settingsSanitize(cfg_);
  const uint32_t now = hal_.millis();
  hal_.setHeartbeat(false);
  hb_ = false;
  hal_.shiftWrite(0);  // everything off before anything else
  lastWord_ = 0;
  lastWriteMs_ = now;
  hal_.setFanPct(0);
  fanPct_ = 0;
  sup_.init(now);
  hist_.reset(now);
  for (int k = 0; k < kNumCh; k++) {
    ch_[k].init((uint8_t)(k + 1));
    vchk_[k] = NAN;
    vbm_[k] = NAN;
    contactOhm_[k] = NAN;
    contactWarn_[k] = false;
    contactCount_[k] = 0;
    outOn_[k] = false;
    outOffSinceMs_[k] = now;
  }
  ir_.active = false;
  scanSt_ = ScanSt::Select;
  scanCh_ = kNumCh;
  cycleStartMs_ = now;
  loopMaxResetMs_ = now;

  // Probe the ADS1115: write a config (no conversion) and read it back.
  const uint16_t w = (uint16_t)(ads::configWord(ads::kAin0Ain1, ads::kFs4096, ads::kSps128) & ~ads::kOsBit);
  uint16_t rb = 0;
  bool ok = hal_.adsWrite(ads::kRegConfig, w) && hal_.adsRead(ads::kRegConfig, rb);
  if (!ok) sup_.killHeartbeat(BoardAlarm::AdsMissing, "no I2C response at 0x48", now);
  else if ((rb & 0x7FFFu) != (w & 0x7FFFu)) sup_.killHeartbeat(BoardAlarm::AdsMissing, "config read-back mismatch", now);

  // First boot: calibrate the board-temperature diode assuming ambient = 25 C.
  if (!cfg_.v25Valid) {
    int32_t sum = 0, n = 0;
    for (int j = 0; j < 8; j++) {
      int32_t mv = hal_.adcReadMv(AdcPin::Tbrd);
      if (mv >= 0) {
        sum += mv;
        n++;
      }
    }
    float v = n ? (float)sum / (float)n / 1000.0f : -1.0f;
    cfg_.v25 = (n && v > 0.55f && v < 0.73f) ? v : kTbrdV25Default;
    cfg_.v25Valid = 1;
    cfgDirty_ = true;
  }
  readBoardInputs(now);
  lastBoardReadMs_ = now;
}

void Controller::setSettings(const Settings &s) {
  cfg_ = s;
  settingsSanitize(cfg_);
}

uint8_t Controller::isetEff() const {
  uint8_t lim = sup_.isetLimit();
  return cfg_.iset < lim ? cfg_.iset : lim;
}

ChannelCtx Controller::ctx(uint32_t nowMs) const {
  ChannelCtx c;
  c.cfg = &cfg_;
  c.nowMs = nowMs;
  c.isetEff = isetEff();
  c.vin = vinValid_ ? vin_ : 5.0f;
  c.powerOk = sup_.powerAllowed();
  c.boardHot = sup_.boardHot();
  return c;
}

bool Controller::anyJobActive() const {
  for (int k = 0; k < kNumCh; k++)
    if (ch_[k].jobActive()) return true;
  return false;
}

void Controller::readBoardInputs(uint32_t nowMs) {
  (void)nowMs;
  int32_t mv = hal_.adcReadMv(AdcPin::Vin);
  if (mv >= 0) {
    float v = vinFromAdc((float)mv / 1000.0f);
    vin_ = vinValid_ ? 0.6f * vin_ + 0.4f * v : v;
    vinValid_ = true;
  } else {
    vinValid_ = false;
  }
  mv = hal_.adcReadMv(AdcPin::Tbrd);
  if (mv >= 0 && boardDiodePlausible((float)mv / 1000.0f)) {
    float v = (float)mv / 1000.0f;
    tbrdV_ = tBoardValid_ ? 0.6f * tbrdV_ + 0.4f * v : v;
    tBoard_ = boardTempC(tbrdV_, cfg_.v25);
    tBoardValid_ = true;
  } else {
    tBoardValid_ = false;
  }
}

void Controller::invalidateSamples() {
  if (samplesInvalidated_) return;
  samplesInvalidated_ = true;
  for (int k = 0; k < kNumCh; k++) ch_[k].invalidate();
}

void Controller::abortAll(const char *why, uint32_t nowMs) {
  ChannelCtx c = ctx(nowMs);
  if (ir_.active) {
    ir_.pulseOn = false;
    ir_.active = false;
    scanSt_ = ScanSt::Select;
  }
  for (int k = 0; k < kNumCh; k++) ch_[k].abortSafety(c, why);
  writeOutputs(nowMs, true);
}

void Controller::setMaintenance(bool on) {
  uint32_t now = hal_.millis();
  if (on) {
    abortAll("maintenance (OTA)", now);
    sup_.setMaintenance(true);
    hal_.shiftWrite(0);
    lastWord_ = 0;
    hb_ = false;
    hal_.setHeartbeat(false);
  } else {
    sup_.setMaintenance(false);
  }
}

// ------------------------------------------------------------------ loop -----
void Controller::step() {
  const uint32_t nowUs = hal_.micros();
  const uint32_t nowMs = hal_.millis();
  if (haveLastStep_) {
    uint32_t gap = nowUs - lastStepUs_;
    if (gap > gapMaxUs_) gapMaxUs_ = gap;
    if (gap > loopMaxUs_) loopMaxUs_ = gap;
  }
  haveLastStep_ = true;
  lastStepUs_ = nowUs;
  if (nowMs - loopMaxResetMs_ >= kLoopMaxWindowMs) {  // publish the max of the last window
    loopMaxPub_ = loopMaxUs_;
    loopMaxUs_ = 0;
    loopMaxResetMs_ = nowMs;
  }

  // ---- board inputs + supervisor ----
  safeRb_ = hal_.safeRb();
  if (nowMs - lastBoardReadMs_ >= kBoardReadMs) {
    lastBoardReadMs_ = nowMs;
    readBoardInputs(nowMs);
  }
  SupInputs in;
  in.nowMs = nowMs;
  in.safeRb = safeRb_;
  in.vinValid = vinValid_;
  in.vin = vin_;
  in.tBoardValid = tBoardValid_;
  in.tBoard = tBoard_;
  in.maxLoopGapMs = gapMaxUs_ / 1000u;
  gapMaxUs_ = 0;
  sup_.update(in, cfg_);
  if (sup_.takeAbortRequest()) abortAll(sup_.alarmText(), nowMs);

  // ---- measurement ----
  if (!sup_.measurementAllowed()) {
    if (ir_.active) {
      IrResult r;
      r.err = "SAFE_EN lost";
      irFinish(false, r, nowMs, ChState::FaultSafety, "SAFE_EN lost during IR pulse");
    }
    scanSt_ = ScanSt::Select;
    invalidateSamples();
  } else {
    samplesInvalidated_ = false;
    if (ir_.active) irStep(nowUs, nowMs);
    else scanStep(nowUs, nowMs);
  }

  // ---- channel timers ----
  ChannelCtx c = ctx(nowMs);
  for (int k = 0; k < kNumCh; k++) ch_[k].tick(c);
  if (ir_.active && !ch_[ir_.ch - 1].irRunning()) {  // stopped/faulted meanwhile
    ir_.pulseOn = false;
    ir_.active = false;
    scanSt_ = ScanSt::Select;
    writeOutputs(nowMs, true);
  }
  for (int k = 0; k < kNumCh; k++) {
    bool a = ch_[k].jobActive();
    if (wasActive_[k] && !a) resultsVersion_++;
    wasActive_[k] = a;
  }
  // ---- OV latch release: heartbeat pause, only while the board is idle ----
  if (latchResetPending_ && !anyJobActive() && !ir_.active && !sup_.latchResetActive() &&
      sup_.heartbeatAllowed()) {
    sup_.startLatchReset(nowMs, kLatchResetMs);
    latchResetPending_ = false;
    latchResetRunning_ = true;
  } else if (latchResetRunning_ && !sup_.latchResetActive()) {
    latchResetRunning_ = false;
    ovPendingMask_ = 0;
  }
  identify_ = identifyUntilMs_ != 0 && (int32_t)(identifyUntilMs_ - nowMs) > 0;
  hist_.tick(nowMs);

  // ---- outputs ----
  writeOutputs(nowMs, false);
  uint8_t f = sup_.fanPct(anyJobActive());
  if (f != fanPct_) {
    fanPct_ = f;
    hal_.setFanPct(f);
  }
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

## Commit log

2026-10-01 LFP-8 hardware: netlist DSL, ngspice models and adversarial tests, KiCad schematic, 3D-printed holder
    - docs/INTERFACE.md: hardware/firmware contract (GPIO map, SR bit map, thresholds)
    - hardware/gen: single-source netlist DSL (835 parts) with verified JLCPCB/LCSC
    part numbers; generators for the project library and the label-based KiCad 7
    schematic; verify_netlist.py proves the schematic equals the DSL netlist
    - sim: behavioural ngspice models (LM324/LM393/TL431/FETs/PTC/LFP cell),
    32 pytest benches covering CC/CV, discharge, IR measurement, protection
    latches, watchdog, reverse polarity, shorts, Monte Carlo and loop stability
    - mechanical: OpenSCAD 40-cell holder (4-cell cradles),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
    [board_stand.stl, board_tray.stl, cradle_4cell_labels_1-4.stl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]
2026-10-01 Firmware: ESP32-C3 controller, web UI, REST API and per-cell IR calculator
    - Arduino sketch for the ESP32-C3-WROOM-02 (portable C++ core + thin HAL):
    charge / discharge / capacity / IR jobs per channel, ADS1115 Kelvin
    measurements through the CD4051 muxes, watchdog heartbeat, hardware OV
    latch handling, thermal pulse policy for deeply discharged cells
    - web UI and JSON API served by the board, UDP discovery for multi-board setups
    - host test suite (76 tests) and a simulated 8-cell capacity run
    - INTERFACE.md: fix board-temperature sensor constants and latch reset timing
    - schematic generator: tidy power-symbol placement
    Claude-Se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
    [lfp8_adc.kicad_sch, lfp8_ch1.kicad_sch, lfp8_ch2.kicad_sch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]
2026-10-01 Docs, PCB generators and portrait board stand
    - README, DESIGN, ORDERING_AND_ASSEMBLY and TEST_REPORT documents
    - run_all_tests.sh runs every suite; hardware/Makefile regenerates the
    KiCad project and the production files
    - make_pcb.py (placement + locked 1 A pre-routes), route_pcb.py
    (Freerouting + session import + zones), check_pcb.py (DRC, netlist,
    current capacity, BOM), make_fab.py (Gerbers, drill, JLCPCB BOM/CPL)
    - holder: board stand follows the 216 x 146 mm PCB mounted portrait with an
    80 x 15 mm fan offset to the power-stage edge; the flat tray no longer
    fits and is dropped from the build
    Claude-Session: https://clau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
    [board_stand.stl, board_tray.stl, lfp_holder.scad]
2026-10-01 PCB: corner mounting holes, footprint fix-ups, placed board (routing in progress)
    - four M3 holes at the board corners (matches the printed stand); J1 moved
    above the bottom-left hole and fed into the +5 V bus on both layers
    - board_fixups(): ESP32 module thermal vias to 0.3 mm drill (JLCPCB 2-layer
    minimum), passive reference designators moved to F.Fab
    - route_pcb.py zone creation is idempotent; check_pcb.py ignores library
    configuration warnings of the headless DRC
    - schematic PDF export
    - lfp8.kicad_pcb is the placed, not yet routed board
    Claude-Session: https://claude.ai/code/session_01741JMFwAZptriPav2AH4Eo
    [lfp8.kicad_pcb]
2026-10-01 Firmware: one IR pulse per scan sweep; researched JLCPCB cost estimate
    - fix: IR measurements that became ready together ran back to back, each
    holding the ADC ~1.1 s, so the other channels went stale and faulted
    (FAULT_ADC). The scanner now starts at most one IR pulse per full sweep,
    round robin. New regression tests: 8 simultaneous IRs, and 3 IRs while
    5 channels discharge (78 host tests pass, ESP32-C3 build OK)
    - parts: 7 resistor values are JLC 'preferred extended' (no loading fee),
    not basic; labels corrected, schematic regenerated (netlist unchanged)
    - ORDERING_AND_ASSEMBLY: per-board cost table for 2 / 5 / 10 assembled boards
    from fee research, the JLC part database and 20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
    [lfp8_ch1.kicad_sch, lfp8_ch2.kicad_sch, lfp8_ch3.kicad_sch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]
2026-10-01 PCB: tiled routing (route one channel, replicate x8, then the common section)
    Routing the whole board in one Freerouting run did not finish within 2 h.
    route_tiled.py routes channel 1 alone with stub pads that bring every
    off-channel net to the column's top edge, copies the result to all eight
    identical channels by translation (nets renamed per channel), and leaves only
    the common section for a final global pass. route_pcb.py helpers take explicit
    DSN/SES paths. lfp8.kicad_pcb is the regenerated placement (corner holes),
    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
    [lfp8.kicad_pcb]
